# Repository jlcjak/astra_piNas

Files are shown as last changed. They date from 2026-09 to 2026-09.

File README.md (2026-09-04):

# Astra piNas — CM5 dual NVMe carrier

This project was an experiment in using GPT-6 Astra to create a complete PCB from a single initial prompt, followed by a request to fully route it.

**Initial prompt** *(lightly edited for spelling and grammar)*

> I need a new KiCad project with schematics for a small Raspberry Pi CM5 carrier board. It needs to take two full-size M.2 SSDs, so you will need a PCIe switch. Find parts for everything, along with symbols and footprints.
>
> It also needs one RJ45 Ethernet connector, an SD card slot, a barrel jack that accepts 9–25 V, PoE capability, and a power-only USB-C port. A second USB-C port should be used just for USB-to-UART.
>
> Find good symbols and footprints for everything, and keep it nice. Pay particular attention to the CM5 footprint and make sure it is correct. You have TI_API_KEY, TI_API_SECRET, MOUSER_API_KEY, DIGIKEY_CLIENT_ID and DIGIKEY_CLIENT_SECRET set as environment variables in `~/.local/share/codex`. You also have easyeda2kicad installed. You can use the other APIs for datasheets and create your own footprints too.
>
> Remember to put the footprints and symbols in self-contained project libraries. All parts should be well in stock and have a MANUFACTURER PART NUMBER property. Actually, let's use only in-stock LCSC parts, with 0402 as the minimum component size. Try to minimize the component count and number of passives.
>
> Place things logically on the board afterward so it is easy for me to route. Explicitly: do not look for other work on this computer that might help. It will not help and must not be used. Strictly.

**Routing follow-up** *(lightly edited for spelling and grammar)*

> OK, now fully route it. Feel free to move things around as much as you like; I like the current size. Make it nice and clean, and pick the stackup and everything. Use six layers at most. I think six makes sense here, actually.

Open **[astra_piNas.kicad_pro](astra_piNas.kicad_pro)** in **KiCad 10**. The project contains nine schematic sheets and a fully routed **100 × 120 mm, six-layer** board. Both 2280 NVMe sockets are on the underside. Use a **CM5 Lite** for the native microSD interface.

- [Routing and placement notes](docs/ROUTING.md), [selected stackup](docs/STACKUP.md)
- [Schematic PDF](docs/schematics.pdf)
- [Top copper view](docs/routing_top.svg), [bottom copper view](docs/routing_bottom.svg)
- [Top assembly view](docs/placement_top.svg), [bottom assembly view](docs/placement_bottom.svg)
- [BOM with MPNs and LCSC stock snapshots](docs/BOM.csv), [library provenance](docs/LIBRARIES.md)
- [Final validation summary](docs/routing_validation.json), [pair measurements](docs/pair_lengths.csv)
- [ERC](docs/erc.rpt), [PCB DRC](docs/drc.rpt), [schematic parity](docs/schematic_parity.rpt)

All symbols and footprints resolve through the project-local library tables to `lib/`. Available 3D models use project-relative paths. No unrelated local project was searched or reused; the Raspberry Pi reference files were downloaded from the official archive linked in [library provenance](docs/LIBRARIES.md).

The main project files above are the current design. Local routing experiments, tool caches and the downloaded CM5IO reference archive are excluded from this repository. Final routing measurements and validation reports are included under `docs/`. Regeneration scripts can overwrite manual edits. No fabrication package is released while the PoE hold remains unresolved.

**Board views**

Slightly angled 3D views of both sides, with project-local passive models:

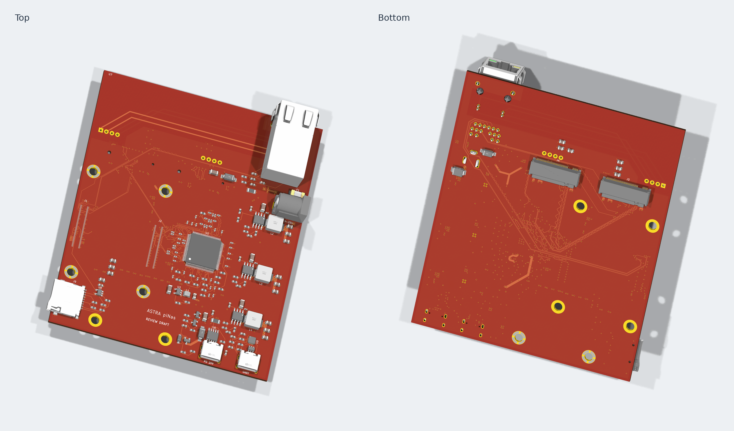
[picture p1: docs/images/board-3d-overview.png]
Angled top and bottom 3D views


Top and bottom placement views:

| Top | Bottom |
| --- | --- |
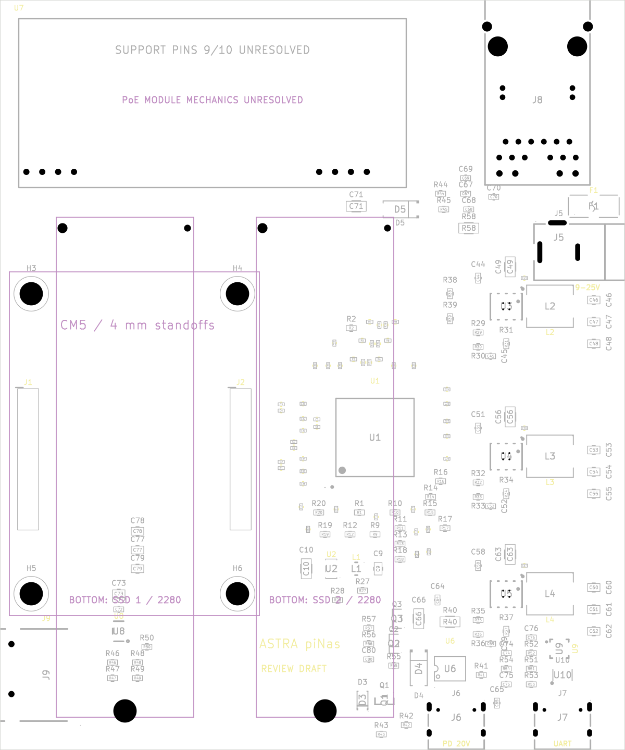
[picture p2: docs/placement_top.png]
Top component placement
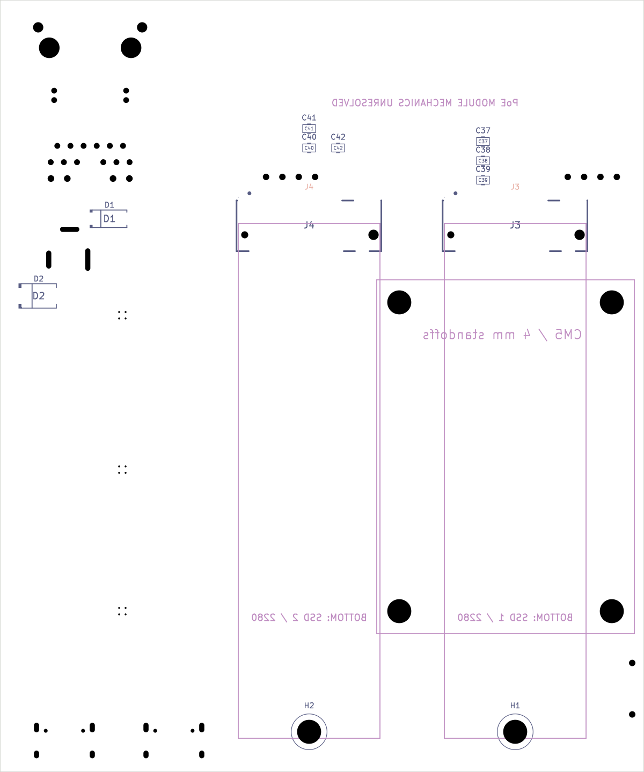
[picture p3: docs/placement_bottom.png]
Bottom component placement
|  |  |

All six copper layers, viewed from the top in stackup order:

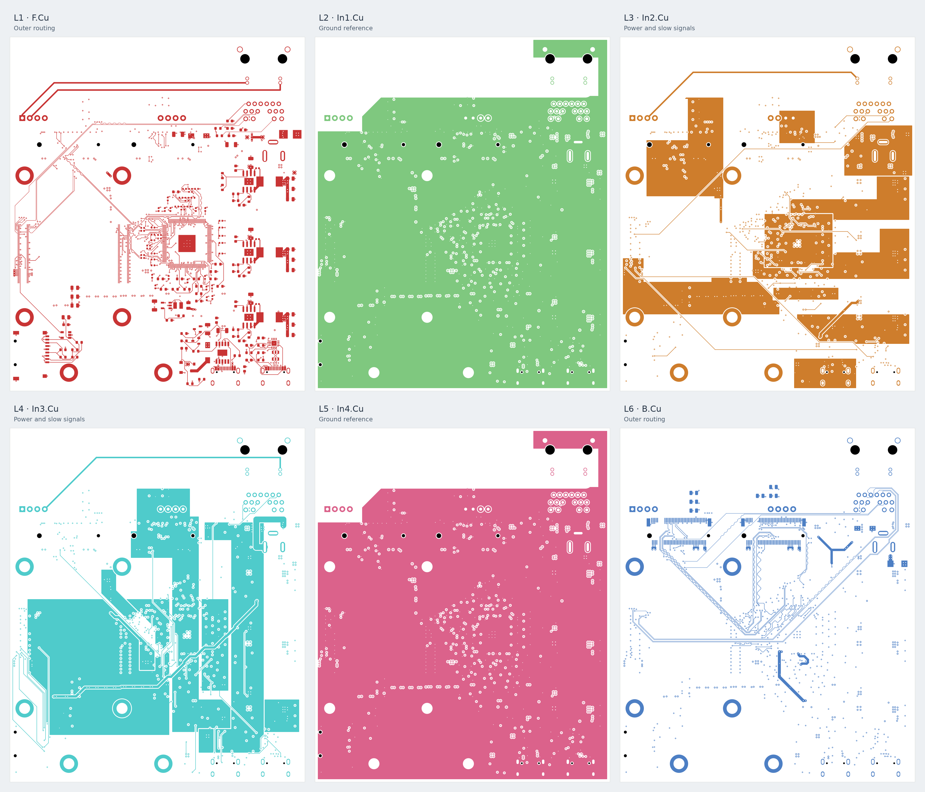
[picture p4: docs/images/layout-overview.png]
Overview of all six PCB copper layers


Individual layers are shown below. Click a layer name for the full-resolution vector drawing.

| Layer | Copper view |
| --- | --- |
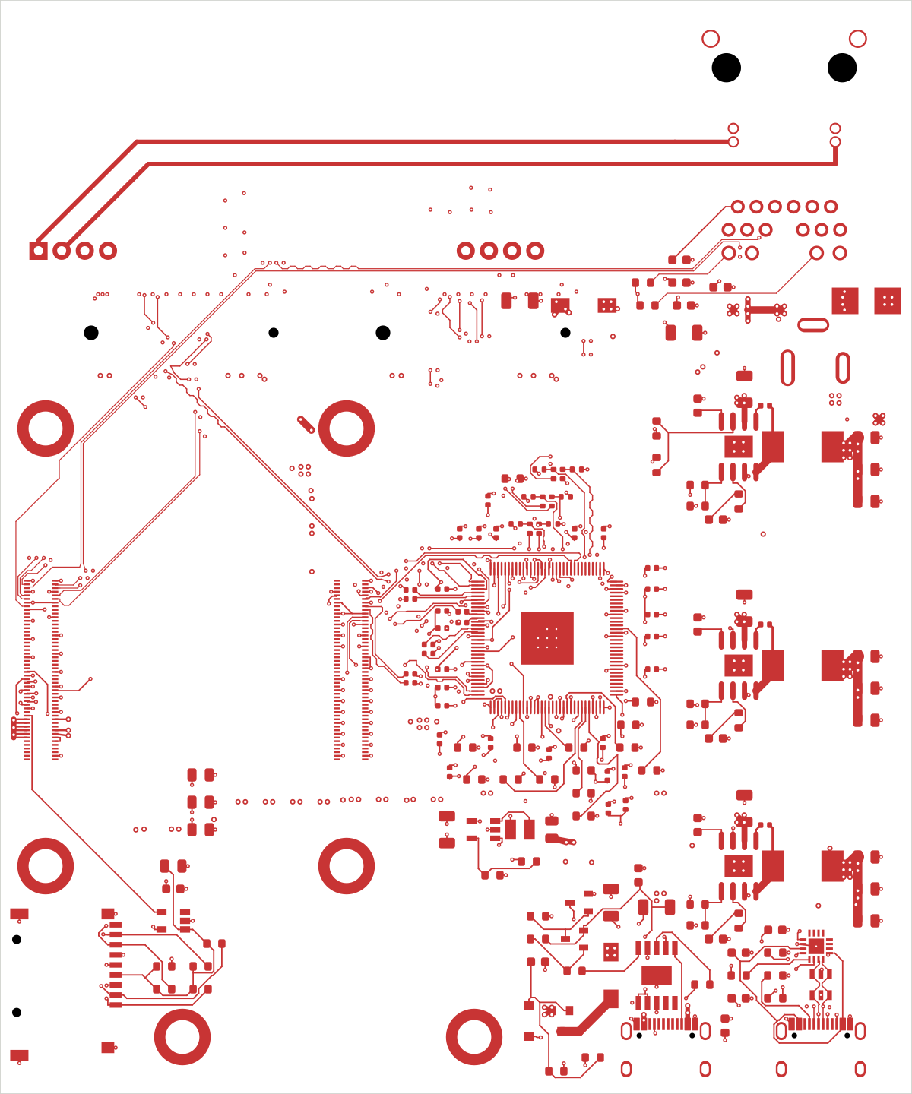
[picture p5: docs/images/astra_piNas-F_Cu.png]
Front copper
| [L1 · F.Cu — outer routing](docs/images/astra_piNas-F_Cu.svg) |  |
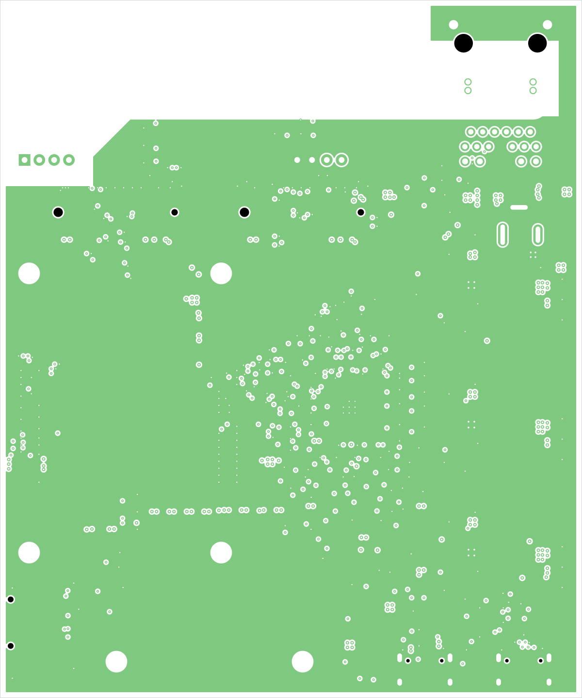
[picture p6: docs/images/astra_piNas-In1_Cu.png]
Inner layer 1 ground plane
| [L2 · In1.Cu — ground reference](docs/images/astra_piNas-In1_Cu.svg) |  |
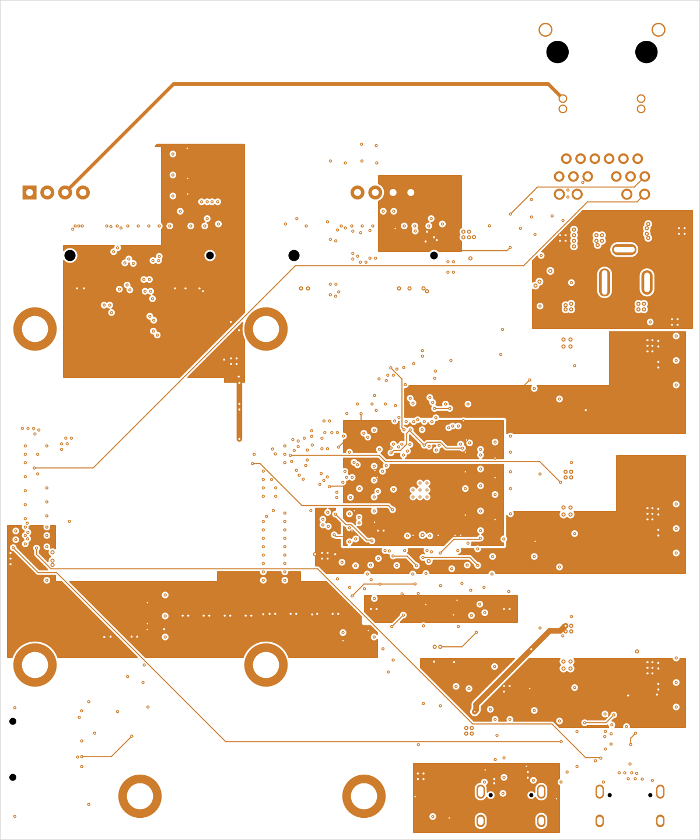
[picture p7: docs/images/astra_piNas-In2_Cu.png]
Inner layer 2 power and signal routing
| [L3 · In2.Cu — power and slow signals](docs/images/astra_piNas-In2_Cu.svg) |  |
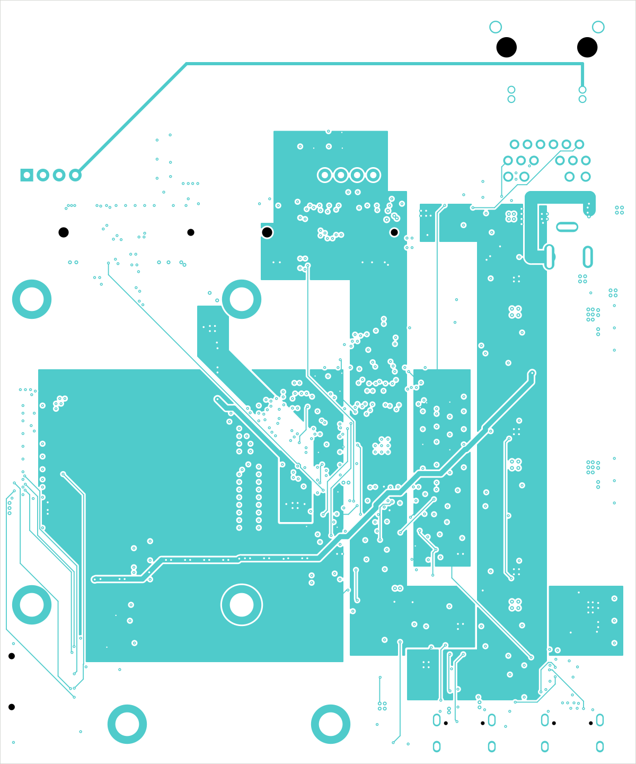
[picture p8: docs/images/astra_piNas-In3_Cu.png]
Inner layer 3 power and signal routing
| [L4 · In3.Cu — power and slow signals](docs/images/astra_piNas-In3_Cu.svg) |  |
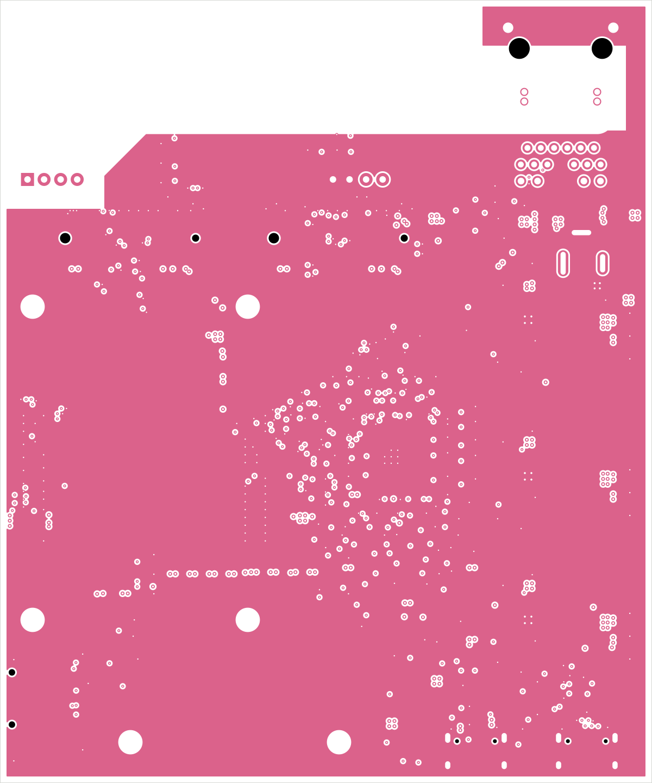
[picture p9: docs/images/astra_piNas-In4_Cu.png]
Inner layer 4 ground plane
| [L5 · In4.Cu — ground reference](docs/images/astra_piNas-In4_Cu.svg) |  |
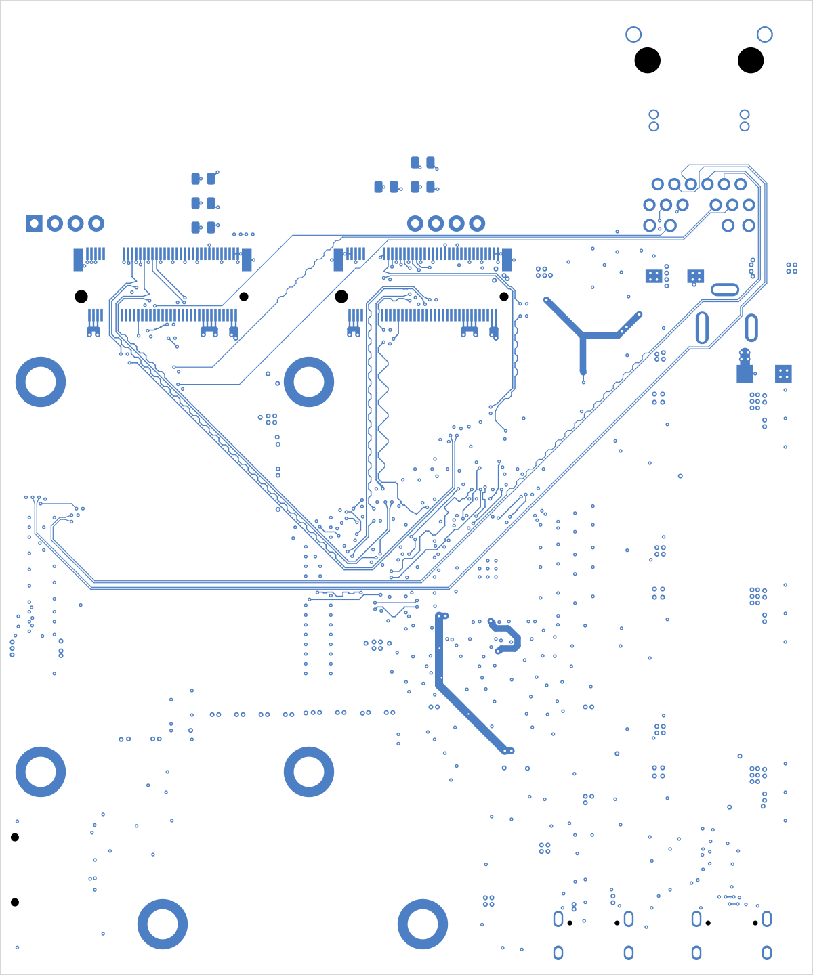
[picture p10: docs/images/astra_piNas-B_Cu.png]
Back copper viewed from the top
| [L6 · B.Cu — outer routing](docs/images/astra_piNas-B_Cu.svg) |  |

**Schematic overview**

All nine sheets are shown below. Open the [schematic PDF](docs/schematics.pdf) to zoom into individual circuits.

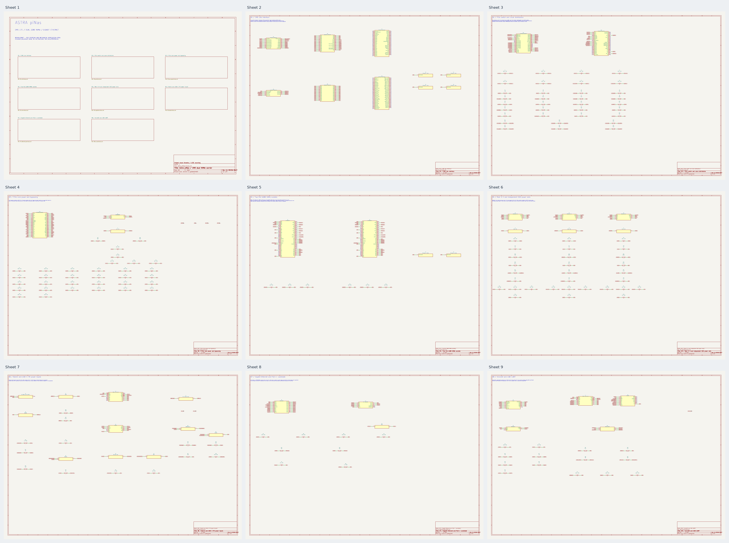
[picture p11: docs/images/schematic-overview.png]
Overview of all nine schematic sheets


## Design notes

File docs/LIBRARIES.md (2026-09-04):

# Local libraries and provenance

`lib/design.kicad_sym` is the active symbol library. Symbols were redrawn into readable functional units with explicit pin numbers; the CM5 connectors and PCIe switch use multiple units but each physical part appears once in the BOM. `lib/astra_piNas.kicad_sym` retains downloaded EasyEDA symbol sources. Active symbols point only to `astra_piNas:` footprints in the project-local `.pretty` directory.

| Part family | Geometry source and treatment |
|---|---|
| CM5 connectors, Amphenol 10164227-1004A1RLF | Pad coordinates taken from Raspberry Pi's official CM5IO revision 2 downloadable KiCad footprint. Split into two physical 100-pin connectors with local numbering. Connector separation, hole locations and module envelope retained in the carrier placement. No substituted CM4/Hirose footprint. |
| TE 1-2199230-5 M.2 | EasyEDA import checked against TE drawing C-2199230, revision B3, sheets 1–3. 0.5 mm pitch, correct M-key gap, 1.1/1.6 mm asymmetric locating holes, and 4.2 mm connector height. Locating holes corrected to NPTH. |
| Hanrun HR913180AE RJ45 | EasyEDA import, checked against Hanrun's schematic and dimensional drawing. Four independent cable center taps feed PoE. Locating holes corrected to NPTH. |
| TYPE-C-31-M-12 | EasyEDA import. Combined VBUS/GND contacts use custom pad shapes; their tiny anchor dimensions do not represent the full copper shape. Locating holes corrected to NPTH. Local pad clearance is 0.09 mm to accommodate the connector's narrow manufactured pad gaps; confirm fabrication capability. |
| AP64501 | EasyEDA package import. Four exposed-pad thermal holes corrected to pin 9/GND and removed from paste openings. Review thermal-via solder treatment with the fabricator. |
| Other semiconductors and connectors | EasyEDA imports tied to the specific LCSC ID, with explicit pin-map review against downloaded datasheets. Imported artwork is not a guarantee of assembly fit. |
| Resistors/capacitors | Vendored standard KiCad SMD footprints matching the selected package size. No 0201 parts. The 1 kΩ PD-feed and PoE-bleeder parts are 1206, 0.5 W ROHM ESR18EZPF1001. |
| YIYUAN SMTSOM225BTR and SMTSOM240BTR spacers | Custom footprints from the YIYUAN family drawing, M2 row: 6.2 mm minimum solder land and 3.73 mm finished hole. Plated holes selected (the drawing permits plating); four separate paste sectors avoid paste over the holes. Heights 2.5 and 4 mm. Verified LCSC pages C5301773 and C19626599. |
| WC-PD60B120A | **Incomplete custom candidate footprint.** The eight electrical pins use dimensions from the module drawing; support pins 9/10 are deliberately absent because their X position is not dimensioned. The body envelope is for placement only. Do not fabricate. |

Available imported WRL/STEP files are stored under `lib/astra_piNas.3dshapes`. Missing optional 3D models were not replaced with guessed geometry. A full assembled CM5/SSD/heatsink model is not provided. All existing model links resolve locally; all 138 resistors and capacitors now link to seven vendored KiCad STEP package models, alongside the existing four inductor models. The generic resistor/capacitor models are visual package representations, not manufacturer-specific height or clearance certification. Their original copyright headers are preserved; see [KiCad model license](../lib/astra_piNas.3dshapes/KICAD-MODELS-LICENSE.md). Model links are present in both the board and local footprint library.

## Primary technical sources

- [Raspberry Pi CM5 datasheet](https://datasheets.raspberrypi.com/cm5/cm5-datasheet.pdf), saved as `sources/cm5.pdf`.
- [Official CM5IO revision 2 KiCad archive](https://pip-assets.raspberrypi.com/categories/1098-design-files/documents/RP-008099-DD-1-CM5%20IO%20Board,%20revision%202,%20KiCAD%20files..zip), used as a geometry reference; the archive and extracted reference project are excluded from this repository.
- [Diodes PI7C9X2G404SL datasheet](https://www.diodes.com/assets/Datasheets/PI7C9X2G404SL.pdf), `sources/switch.pdf`.
- [Diodes AP64501 datasheet](https://www.diodes.com/assets/Datasheets/AP64501.pdf), `sources/ap64501.pdf`.
- [YIYUAN SMTSOM225BTR](https://www.lcsc.com/product-detail/C5301773.html), manufacturer family drawing saved as `sources/C5301773.pdf`; [SMTSOM240BTR](https://www.lcsc.com/product-detail/C19626599.html).
- Other manufacturer datasheets downloaded via the corresponding LCSC product pages are saved as `sources/C<number>.pdf`. LCSC product URLs, actual LCSC stock (distinct from JLC assembly stock), and UTC timestamps are in `sources/catalog.json` and the BOM. Raw retrieved product HTML is retained as evidence.

The imported libraries and manufacturer reference material retain their original ownership and licensing. These were fetched from public sources; no unrelated local project was inspected or reused.

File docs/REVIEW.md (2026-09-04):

# Release status: routed review; fabrication hold

This is a new KiCad 10 project created in this directory. The schematics and board are linked, with project-local symbols, footprints and available 3D models. The 100 × 120 mm, six-layer board is routed and geometrically length-matched. No Gerbers have been released.

## Open design decisions

1. **PoE does not yet meet the sourcing/mechanical requirement.** WC-PD60B120A (LCSC C2848082) has only **15** units available in the captured LCSC evidence. It is a candidate, not an approved production selection. Its supplied drawing does not locate support pins 9/10 horizontally. Its local footprint therefore intentionally includes only the eight dimensioned electrical pins and a body envelope. Do not manufacture that footprint. A manufacturer-confirmed drawing and adequate supply, or a different PoE implementation, are required. The low stock was not silently accepted as “well stocked.”
2. **PoE power budget needs a decision.** The module advertises 12 V / 5 A and mentions class 5/6 operation. That does not establish delivery of 60 W to this carrier from a class-6 PSE. Classification, conversion loss and temperature derating must be resolved. A fully loaded CM5 and two unrestricted SSDs cannot be promised to operate on an ordinary PoE+ port. There is no software-controlled load shedding or negotiated-power telemetry in this draft.
3. **Power validation remains required.** Check AP64501 compensation with effective, voltage-biased output capacitance (including the SSD input capacitance), USB-PD inrush and source handover, 9 V maximum-load operation, and temperatures of the OR diodes and converters. Check the 1 V/3.3 V switch power-down sequence and reset timing on actual hardware. ERC does not validate these behaviors.
4. **Connector/mechanical fit must be checked with purchased samples.** CM5 connector pads and relative positioning use the official CM5IO reference. M.2 pads match the TE drawing. The SSD insertion datum and spacer height were derived from TE's drawing; confirm with the actual sockets and SSDs before release. The PoE support-hole problem is a known incompleteness, not a sample-validation formality.
5. **Assembly hardware:** the soldered spacers are in the LCSC BOM; removable M2 screws, the CM5 Lite, SSDs, heatsinks and enclosure are not included in the carrier BOM. Screw engagement and head diameter must be selected for the actual assembly. M2 screws are used through the CM5's 2.7 mm mounting holes.

## Implemented architecture

- CM5 **Lite** carrier; native microSD wiring. An eMMC-equipped CM5 cannot use this socket as its native SD boot interface.
- Two TE 1-2199230-5 M-key sockets, each connected at PCIe x1, supporting 2280 **NVMe** modules. SATA SSDs are not supported.
- Diodes PI7C9X2G404SLBFDEX PCIe switch: upstream port 0, SSDs on ports 1 and 2, port 3 unused. All SSD traffic shares the CM5 PCIe Gen 2 x1 link; this is not two independent x4 links.
- Integrated switch clock buffer. CM5 CLKREQ# is grounded for continuous clocking. Switch TX lines have external AC coupling; the CM5 TX coupling is already on the module. HCSL outputs use 49.9-ohm shunts and 33.2-ohm series resistors; the switch's own REFCLK input is AC coupled.
- Separate AP64501 converters for CM5 5 V and each SSD 3.3 V rail. SSD enables follow PCIE_PWR_EN. A TLV62569 generates the switch's 1 V rail, enabled from CM5 3.3 V.
- Gigabit PoE-capable Hanrun HR913180AE magjack, with the four cable-side center taps routed to the candidate PoE module. PHY-side center taps have local bypassing.
- Center-positive 9–25 V barrel input, 5 A fuse, TVS and Schottky reverse-current blocking. Input current and temperature, especially at 9 V, limit total usable power.
- Power-only USB-C uses a CH224K requesting **20 V** (CFG1=0, CFG2=1, CFG3=0; the CH224Q/A strap table is different). Use a supply offering 20 V at 3 A. Its status signal controls a level-shifted PMOS gate, with a 10 V gate clamp. The VDD feed resistor is rated 0.5 W. A gate capacitor slows switching, but compliant inrush has not been demonstrated.
- The second USB-C connects only to CH343P USB-UART. USB VBUS powers the bridge; CM5 3.3 V powers its independent VIO. GPIO14 is CM5 TX; GPIO15 is CM5 RX. This is **not** the separate on-module boot-debug UART. Configure the OS UART/pin mux accordingly. USB enumeration and a compatible driver are required on the host.
- All selected resistors and capacitors are 0402 or larger. Every populated carrier component has `MANUFACTURER PART NUMBER`, manufacturer and LCSC fields. Positive stock is recorded in the BOM, but stock is a snapshot, not a reservation.

## Verification meaning

`erc.rpt` is KiCad's electrical-rules report. `audit.json` checks the generated netlist against the explicit pin-to-net manifest and verifies MPN/stock metadata; it is a consistency check, not an independent circuit proof. `drc.rpt` records the final PCB geometry and connectivity checks. `pair_lengths.csv` records the pad-to-pad differential-path measurements. Known limitations must not be hidden by quoting a clean ERC result.

The imported EasyEDA footprints were corrected where locating holes were erroneously plated and where buck-converter thermal vias were unnamed. The terminal numbers of all connected schematic pins are checked against board pads. YIYUAN spacer footprints use the manufacturer's 6.2 mm solder land and 3.73 mm finished hole. Plated holes are selected and the paste aperture is split into four sectors. The rejected Würth candidates were not retained in the active BOM because their LCSC pages were unavailable.

## Final automated checks

See `routing_validation.json`, `erc.rpt`, `drc.rpt`, `schematic_parity.rpt`, `audit.json` and `board_audit.json` for the actual final results. Routing DRC and schematic parity are reported separately: the two omitted PoE support pads, U7.9 and U7.10, remain a known footprint incompleteness. The consistency audit checks 685 connected schematic pin assignments across 176 physical components. These checks do not resolve the PoE hold or replace prototype validation.

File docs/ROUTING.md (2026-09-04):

# Routed board

The outline remains **100 × 120 mm**. The board uses **six copper layers**, with the JLCPCB JLC06161H-3313 construction recorded in the KiCad stackup. See [STACKUP.md](STACKUP.md) for dielectric thicknesses, copper weights and impedance assumptions.

| Layer | Assignment |
|---|---|
| F.Cu | Components, differential pairs, local power loops and signal escapes |
| In1.Cu | Ground reference |
| In2.Cu | Power distribution and slow signals |
| In3.Cu | Power distribution and slow signals |
| In4.Cu | Ground reference |
| B.Cu | M.2 sockets, differential pairs and local connections |

There are no signal traces on In1.Cu or In4.Cu. Secondary ground is excluded from the cable-side PoE region. PCIe, reference-clock, Ethernet and USB data traces use the outer layers.

## Pair routing and verification

PCIe and USB nominal dimensions are 0.127 mm width / 0.150 mm coupled gap; Ethernet uses 0.100 mm / 0.150 mm. Local escapes, AC-coupling parts and tuning sections separate the pair members. Fabricator confirmation of controlled impedance remains necessary.

The pad-to-pad length audit follows each signal through its coupling capacitors and clock resistors, excludes unused branches, and checks both USB-C plug orientations. Pair members have equal traversed-via counts and equal calculated barrel lengths. Targets are 0.10 mm intra-pair skew for PCIe/clock/USB and 0.15 mm for Ethernet. See [pair_lengths.csv](pair_lengths.csv) for the final measurements and [routing_validation.json](routing_validation.json) for check results. This geometric audit is not an electromagnetic simulation or a hardware eye-diagram test.

Three supported PCIe polarity reversals are explicit in the schematics: the CM5 receive pair, the switch's upstream receive pair, and SSD2's receive pair at J4. These do not swap transmit and receive functions. The switch's RXPOLINV_DIS pin remains unconnected, using its internal pull-down.

Ground return vias accompany layer transitions. Long auxiliary supply bridges are stitched into the broad supply planes; local via arrays serve the regulators, OR diodes and load connections. Power-loop copper and regulator switch nodes were routed before the remaining signals. Some power, exposed-pad and small-component connections use vias in pads: specify an appropriate filled/capped process and review the stencil with the assembler.

## Mechanical placement

- CM5 body envelope: X=1.5–41.5, Y=43.5–98.5 mm. J1=(4.5,73.5), J2=(38.5,73.5), preserving the official 34 mm connector separation. CM5 spacer centers are (5,47), (38,47), (5,95), (38,95), a 33 × 48 mm mounting pattern with 4 mm spacers.
- Both 2280 SSDs are on the underside. Sockets are centered at (20,35) and (52,35), with insertion toward increasing Y. Their 2.5 mm retention spacers are at Y=113.75 mm. Card envelopes are drawn on Dwgs.User; bottom-side components are kept out of them.
- The PCIe switch and its small passives occupy the center. Three main power stages occupy the right side. RJ45 is at the upper-right edge, barrel power at the right edge, the two USB-C ports at the bottom, and microSD at the lower-left edge.
- Keep adequate airflow and CM5/SSD cooling. The project does not contain a complete enclosure or heatsink clearance model.

## Fabrication hold

Routing completion does not clear the PoE module's missing support-pin dimensions or its limited stock. See [REVIEW.md](REVIEW.md). No fabrication package is released. Prototype validation must cover supply regulation and temperature under load, source handover, USB-PD inrush, PoE classification/budget, reset sequencing, and operation of both SSDs.

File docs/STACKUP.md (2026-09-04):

# Six-layer stackup

Selected fabrication reference: **JLCPCB JLC06161H-3313**, nominal finished thickness **1.6 mm**, outer copper 1 oz and inner copper 0.5 oz. Dimensions below follow [JLCPCB's published impedance stackup](https://jlcpcb.com/impedance), checked 5 September 2026. Finished thickness includes manufacturing tolerances; do not substitute another six-layer construction without recalculating impedance.

| Layer / dielectric | Thickness, mm | Relative permittivity | Use |
|---|---:|---:|---|
| F.Cu | 0.0350 | — | Components, high-speed pairs, local power loops |
| 3313 prepreg | 0.0994 | 4.10 | |
| In1.Cu | 0.0152 | — | Ground reference; no signal routing |
| Core | 0.5500 | 4.60 | |
| In2.Cu | 0.0152 | — | Power distribution and slow signals |
| 2116 prepreg | 0.1088 | 4.16 | |
| In3.Cu | 0.0152 | — | Power distribution and slow signals |
| Core | 0.5500 | 4.60 | |
| In4.Cu | 0.0152 | — | Ground reference; no signal routing |
| 3313 prepreg | 0.0994 | 4.10 | |
| B.Cu | 0.0350 | — | SSD sockets, high-speed pairs and local bridges |

Outer microstrip starting dimensions are **0.127 mm width / 0.150 mm gap** for 90 Ω PCIe and USB, and **0.100 mm width / 0.150 mm gap** for 100 Ω Ethernet. These are nominal design dimensions, not measured impedance. The fabricator must confirm its controlled-impedance construction and coupon results; solder-mask thickness, etched conductor shape and actual dielectric properties affect the result. The exploratory quasi-static estimates in `routing/impedance_estimates.json` are not a fabrication field-solver sign-off.

The reference planes are continuous in the secondary power domain. Cable-side PoE conductors and the module primary connections are excluded from secondary copper regions. Power bridges use the two interior signal layers or the outer layers, retaining both ground reference layers.

Minimum ordinary clearance is 0.127 mm; existing fine-pitch connector land patterns retain their documented local clearances. Small through vias are 0.45 / 0.20 mm diameter/drill; power arrays use 0.60 / 0.30 mm. Copper is kept at least 0.5 mm from the routed board edge. Some exposed-pad and power-pad connections use vias in pads: confirm a filled/capped process and the corresponding stencil with the assembler before fabrication.

Raspberry Pi specifies 90 Ω differential PCIe routing with an ideal 0.1 mm intra-pair length match, and 100 Ω Ethernet with an ideal 0.15 mm intra-pair match. See the [CM5 datasheet](https://pip-assets.raspberrypi.com/categories/944-raspberry-pi-compute-module-5/documents/RP-008180-DS-4-cm5-datasheet.pdf). The two CM5 receiver coupling capacitors are 220 nF; the other data coupling positions are 100 nF.

This stackup selection does not clear the outstanding PoE mechanical fabrication hold in `REVIEW.md`.

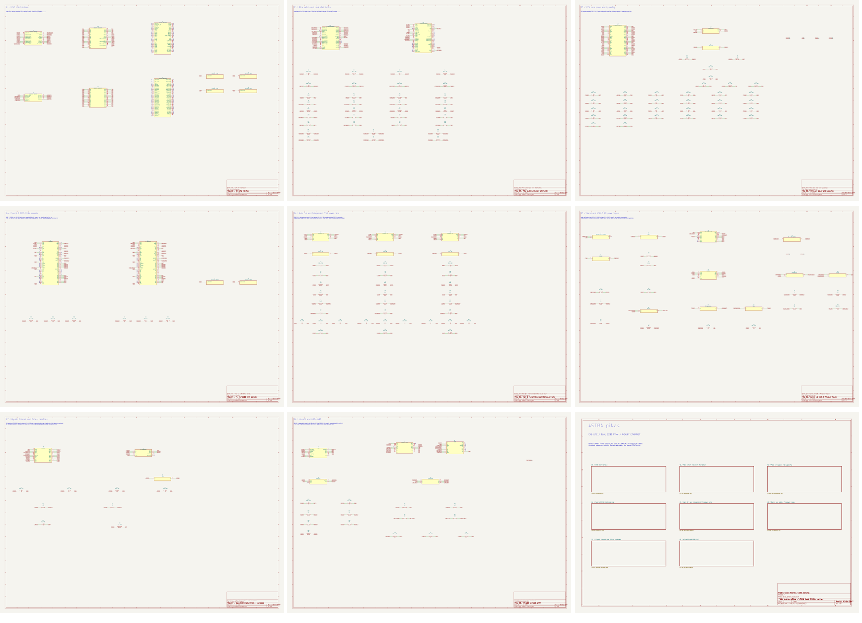
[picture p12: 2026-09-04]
docs/schematic_contact_sheet.png

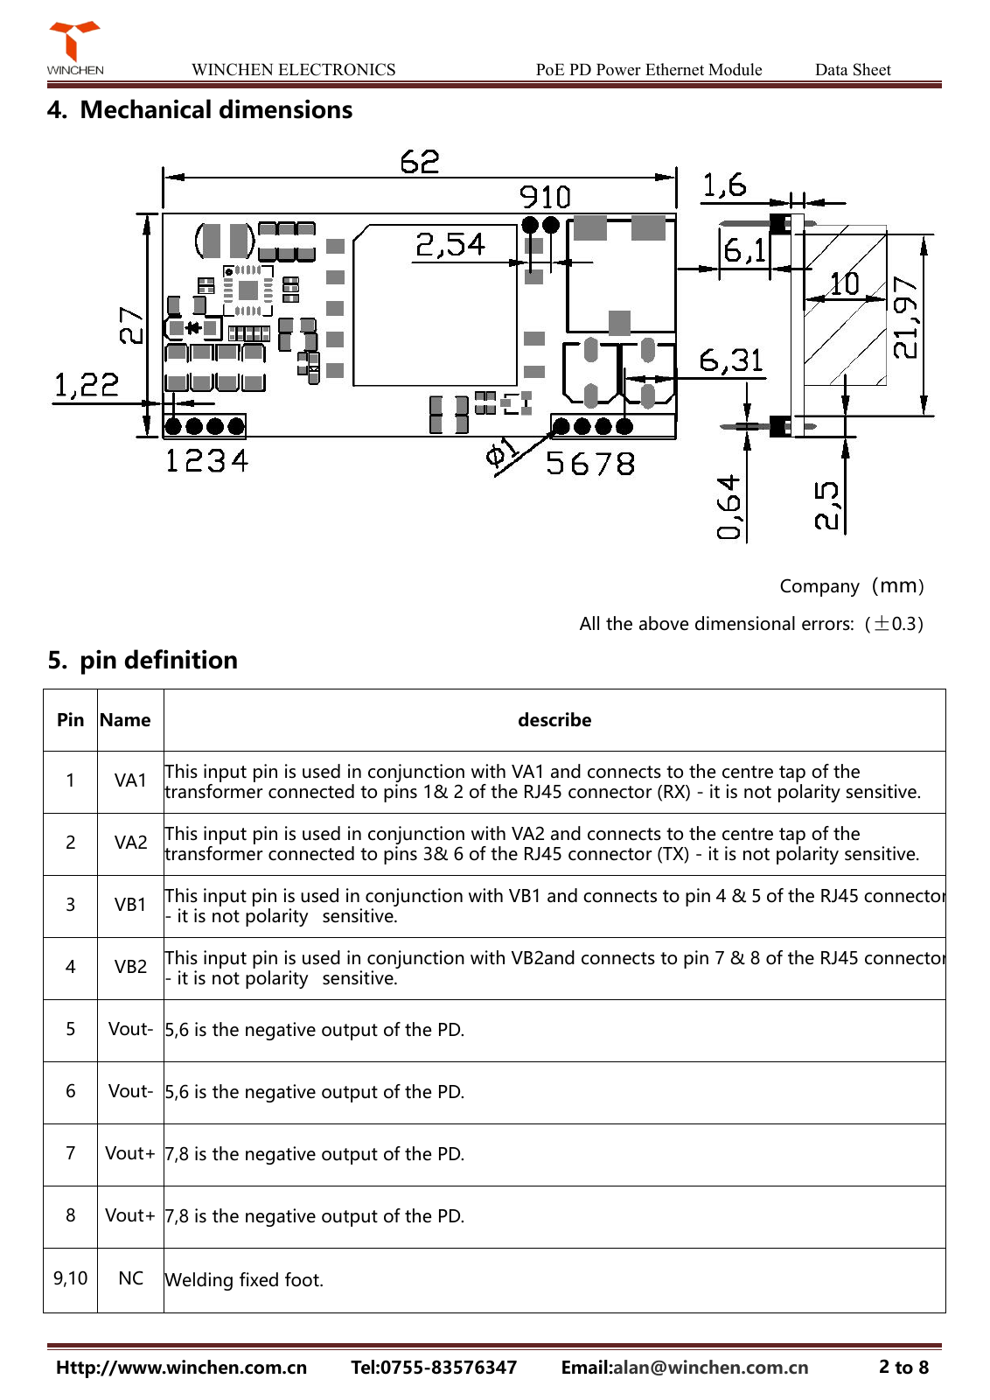
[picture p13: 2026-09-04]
sources/poe_mechanical.png

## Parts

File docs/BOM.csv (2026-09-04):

References | Quantity | Manufacturer | MANUFACTURER PART NUMBER | LCSC Part Number | LCSC Stock | Stock checked UTC | Footprint | Product URL | Status
D2 | 1 | MDD(Microdiode Semiconductor) | SMBJ26A | C123820 | 25520 | 2026-09-04T21:32:39.584681+00:00 | SMB_L4.6-W3.6-LS5.3-RD | https://www.lcsc.com/product-detail/C123820.html | Selected; prototype validation required
D1, D4, D5 | 3 | Shandong Jingdao Microelectronics | SS54 | C123946 | 46960 | 2026-09-04T21:32:38.063087+00:00 | SMA_L4.4-W2.8-LS5.4-RD | https://www.lcsc.com/product-detail/C123946.html | Selected; prototype validation required
U2 | 1 | Texas Instruments | TLV62569DBVR | C141836 | 128295 | 2026-09-04T21:32:37.690946+00:00 | SOT-23-5_L3.0-W1.7-P0.95-LS2.8-BR | https://www.lcsc.com/product-detail/C141836.html | Selected; prototype validation required
C10, C49, C56, C63, C66, C71 | 6 | Samsung Electro-Mechanics | CL31B106KAHNNNE | C14860 | 1052960 | 2026-09-04T21:32:39.182945+00:00 | C_1206_3216Metric | https://www.lcsc.com/product-detail/C14860.html | Selected; prototype validation required
Q1 | 1 | Alpha & Omega Semicon | AO3401A | C15127 | 244595 | 2026-09-04T21:32:39.691958+00:00 | SOT-23_L2.9-W1.3-P1.90-LS2.4-BR | https://www.lcsc.com/product-detail/C15127.html | Selected; prototype validation required
C3, C4, C5, C6, C7, C8, C11, C12, C13, C14, C15, C16, C17, C18, C19, C20, C21, C22, C23, C24, C25, C26, C27, C28, C29, C30, C31, C32, C33, C34, C35, C36, C43, C50, C57 | 35 | Samsung Electro-Mechanics | CL05B104KO5NNNC | C1525 | 7129300 | 2026-09-04T21:46:20.728586+00:00 | C_0402_1005Metric | https://www.lcsc.com/product-detail/C1525.html | Selected; prototype validation required
C44, C51, C58 | 3 | Samsung Electro-Mechanics | CL10B103KB8NNNC | C1589 | 2840150 | 2026-09-04T21:32:39.313226+00:00 | C_0603_1608Metric | https://www.lcsc.com/product-detail/C1589.html | Selected; prototype validation required
C67, C68, C69, C70, C72, C74, C75, C76, C80 | 9 | Samsung Electro-Mechanics | CL10B104KB8NNNC | C1591 | 2493100 | 2026-09-04T21:32:38.954077+00:00 | C_0603_1608Metric | https://www.lcsc.com/product-detail/C1591.html | Selected; prototype validation required
J6, J7 | 2 | Korean Hroparts Elec | TYPE-C-31-M-12 | C165948 | 284155 | 2026-09-04T21:32:37.263211+00:00 | USB-C_SMD-TYPE-C-31-M-12_1 | https://www.lcsc.com/product-detail/C165948.html | Selected; prototype validation required
C1, C2 | 2 | Samsung Electro-Mechanics | CL05B224KO5NNNC | C16772 | 2585850 | 2026-09-04T22:11:29.445277+00:00 | C_0402_1005Metric | https://www.lcsc.com/product-detail/C16772.html | Selected; prototype validation required
H3, H4, H5, H6 | 4 | YIYUAN | SMTSOM240BTR | C19626599 | 875 | 2026-09-04T21:34:10.001349+00:00 | YIYUAN_SMTSOM240BTR | https://www.lcsc.com/product-detail/C19626599.html | Selected; prototype validation required
J8 | 1 | HANRUN(Zhongshan HanRun Elec) | HR913180AE | C19724762 | 169 | 2026-09-04T21:32:37.227892+00:00 | RJ45-TH_HR913180AE | https://www.lcsc.com/product-detail/C19724762.html | Selected; prototype validation required
U3, U4, U5 | 3 | Diodes Incorporated | AP64501SP-13 | C2071517 | 1806 | 2026-09-04T21:32:37.682590+00:00 | SOIC-8_L4.9-W3.9-P1.27-LS6.0-BL-EP-1 | https://www.lcsc.com/product-detail/C2071517.html | Selected; prototype validation required
R40, R58 | 2 | ROHM Semicon | ESR18EZPF1001 | C2074262 | 11480 | 2026-09-04T21:32:40.354956+00:00 | R_1206_3216Metric | https://www.lcsc.com/product-detail/C2074262.html | Selected; prototype validation required
D3 | 1 | Jiangsu Changjing Electronics Technology Co., Ltd. | BZT52C10 | C2103 | 85600 | 2026-09-04T21:32:39.704045+00:00 | SOD-123_L2.8-W1.8-LS3.7-RD | https://www.lcsc.com/product-detail/C2103.html | Selected; prototype validation required
R29 | 1 | UNI-ROYAL(Uniroyal Elec) | 0603WAF1153T5E | C22783 | 95900 | 2026-09-04T21:32:38.615274+00:00 | R_0603_1608Metric | https://www.lcsc.com/product-detail/C22783.html | Selected; prototype validation required
R1 | 1 | UNI-ROYAL(Uniroyal Elec) | 0603WAF1431T5E | C22840 | 14900 | 2026-09-04T21:32:38.347249+00:00 | R_0603_1608Metric | https://www.lcsc.com/product-detail/C22840.html | Selected; prototype validation required
R34, R37 | 2 | UNI-ROYAL(Uniroyal Elec) | 0603WAF1052T5E | C22855 | 125200 | 2026-09-04T21:32:38.845629+00:00 | R_0603_1608Metric | https://www.lcsc.com/product-detail/C22855.html | Selected; prototype validation required
R31 | 1 | UNI-ROYAL(Uniroyal Elec) | 0603WAF1582T5E | C22880 | 41900 | 2026-09-04T21:32:38.774034+00:00 | R_0603_1608Metric | https://www.lcsc.com/product-detail/C22880.html | Selected; prototype validation required
R28 | 1 | UNI-ROYAL(Uniroyal Elec) | 0603WAF3003T5E | C23024 | 440700 | 2026-09-04T21:32:38.978050+00:00 | R_0603_1608Metric | https://www.lcsc.com/product-detail/C23024.html | Selected; prototype validation required
R32, R35 | 2 | UNI-ROYAL(Uniroyal Elec) | 0603WAF6982T5E | C23098 | 32100 | 2026-09-04T21:32:38.534037+00:00 | R_0603_1608Metric | https://www.lcsc.com/product-detail/C23098.html | Selected; prototype validation required
R14, R15, R16, R17, R18, R19, R20, R44, R45, R53, R54 | 11 | UNI-ROYAL(Uniroyal Elec) | 0603WAF3300T5E | C23138 | 2435600 | 2026-09-04T21:32:38.107244+00:00 | R_0603_1608Metric | https://www.lcsc.com/product-detail/C23138.html | Selected; prototype validation required
R2 | 1 | UNI-ROYAL(Uniroyal Elec) | 0603WAF4750T5E | C23181 | 3300 | 2026-09-04T21:32:38.457299+00:00 | R_0603_1608Metric | https://www.lcsc.com/product-detail/C23181.html | Selected; prototype validation required
R9, R10, R11, R12, R13, R51, R52 | 7 | UNI-ROYAL(Uniroyal Elec) | 0603WAF5101T5E | C23186 | 20146800 | 2026-09-04T21:32:38.051660+00:00 | R_0603_1608Metric | https://www.lcsc.com/product-detail/C23186.html | Selected; prototype validation required
U8 | 1 | Richtek Tech | RT9742GGJ5 | C250547 | 6085 | 2026-09-04T21:32:37.703076+00:00 | TSOT-23-5_L2.9-W1.6-P0.95-LS2.8-BR | https://www.lcsc.com/product-detail/C250547.html | Selected; prototype validation required
R21, R22, R23, R24, R25, R26 | 6 | UNI-ROYAL(Uniroyal Elec) | 0402WGF332JTCE | C25106 | 26200 | 2026-09-04T21:46:21.111842+00:00 | R_0402_1005Metric | https://www.lcsc.com/product-detail/C25106.html | Selected; prototype validation required
R3, R4, R5, R6, R7, R8 | 6 | UNI-ROYAL(Uniroyal Elec) | 0402WGF499JTCE | C25120 | 1256000 | 2026-09-04T21:46:21.494433+00:00 | R_0402_1005Metric | https://www.lcsc.com/product-detail/C25120.html | Selected; prototype validation required
R38, R42, R56, R57 | 4 | UNI-ROYAL(Uniroyal Elec) | 0603WAF1003T5E | C25803 | 17262200 | 2026-09-04T21:32:38.095536+00:00 | R_0603_1608Metric | https://www.lcsc.com/product-detail/C25803.html | Selected; prototype validation required
R27 | 1 | UNI-ROYAL(Uniroyal Elec) | 0603WAF2003T5E | C25811 | 1621700 | 2026-09-04T21:32:38.891275+00:00 | R_0603_1608Metric | https://www.lcsc.com/product-detail/C25811.html | Selected; prototype validation required
R30, R33, R36, R39 | 4 | UNI-ROYAL(Uniroyal Elec) | 0603WAF2212T5E | C25961 | 16200 | 2026-09-04T21:32:38.495874+00:00 | R_0603_1608Metric | https://www.lcsc.com/product-detail/C25961.html | Selected; prototype validation required
U9 | 1 | WCH(Jiangsu Qin Heng) | CH343P | C2846043 | 4883 | 2026-09-04T21:32:37.653872+00:00 | TQFN-16_L3.0-W3.0-P0.50-BL-EP1.7 | https://www.lcsc.com/product-detail/C2846043.html | Selected; prototype validation required
L2, L3, L4 | 3 | KOHERelec | MDA7050-3R3M | C2847540 | 742 | 2026-09-04T21:32:39.326260+00:00 | IND-SMD_L7.3-W6.6 | https://www.lcsc.com/product-detail/C2847540.html | Selected; prototype validation required
U7 | 1 | Winchen | WC-PD60B120A | C2848082 | 15 | 2026-09-04T21:32:37.304659+00:00 | WC_PD60B120A_MECHANICAL_REVIEW | https://www.lcsc.com/product-detail/C2848082.html | PROVISIONAL: low stock and incomplete mechanics
C64, C65 | 2 | Samsung Electro-Mechanics | CL10B105KA8NNNC | C29936 | 1640030 | 2026-09-04T21:32:39.785787+00:00 | C_0603_1608Metric | https://www.lcsc.com/product-detail/C29936.html | Selected; prototype validation required
C9, C37, C38, C39, C40, C41, C42, C46, C47, C48, C53, C54, C55, C60, C61, C62, C73, C77, C78, C79 | 20 | Samsung Electro-Mechanics | CL21A226MAQNNNE | C45783 | 1788200 | 2026-09-04T21:32:39.032809+00:00 | C_0805_2012Metric | https://www.lcsc.com/product-detail/C45783.html | Selected; prototype validation required
F1 | 1 | Littelfuse | 0451005.MRL | C48467 | 27635 | 2026-09-04T21:32:40.428725+00:00 | FUSE-SMD_L6.1-W2.6 | https://www.lcsc.com/product-detail/C48467.html | Selected; prototype validation required
U1 | 1 | Diodes Incorporated | PI7C9X2G404SLBFDEX | C500767 | 2750 | 2026-09-04T21:32:37.276258+00:00 | LQFP-128_L14.0-W14.0-P0.40-LS16.0-BL-EP5.8 | https://www.lcsc.com/product-detail/C500767.html | Selected; prototype validation required
H1, H2 | 2 | YIYUAN | SMTSOM225BTR | C5301773 | 6500 | 2026-09-04T21:34:09.999921+00:00 | YIYUAN_SMTSOM225BTR | https://www.lcsc.com/product-detail/C5301773.html | Selected; prototype validation required
Q2 | 1 | onsemi | MMBT3906LT1G | C53444 | 1085650 | 2026-09-04T21:32:40.192534+00:00 | SOT-23-3_L2.9-W1.3-P1.90-LS2.4-BR | https://www.lcsc.com/product-detail/C53444.html | Selected; prototype validation required
J3, J4 | 2 | TE Connectivity | 1-2199230-5 | C590854 | 1169 | 2026-09-04T21:32:37.254522+00:00 | PCIE-SMD_75P-P0.50_1-2199230-5 | https://www.lcsc.com/product-detail/C590854.html | Selected; prototype validation required
J5 | 1 | HOOYA | DC-005D-2.0-PU-SP(UL) | C7428653 | 385 | 2026-09-04T21:32:37.959444+00:00 | DC-IN-TH_DC-005D-2.0-PU-SP | https://www.lcsc.com/product-detail/C7428653.html | Selected; prototype validation required
J1, J2 | 2 | Amphenol ICC | 10164227-1004A1RLF | C7435219 | 1174 | 2026-09-04T21:32:37.241261+00:00 | CM5_Amphenol_10164227_1004_OfficialPads | https://www.lcsc.com/product-detail/C7435219.html | Selected; prototype validation required
U10 | 1 | STMicroelectronics | USBLC6-2SC6 | C7519 | 29315 | 2026-09-04T21:32:39.526801+00:00 | SOT-23-6_L2.9-W1.6-P0.95-LS2.8-BL | https://www.lcsc.com/product-detail/C7519.html | Selected; prototype validation required
C45, C52, C59 | 3 | Samsung Electro-Mechanics | CL10B272KB8NNNC | C84713 | 34060 | 2026-09-04T21:32:39.297779+00:00 | C_0603_1608Metric | https://www.lcsc.com/product-detail/C84713.html | Selected; prototype validation required
Q3 | 1 | Jiangsu Changjing Electronics Technology Co., Ltd. | 2N7002 | C8545 | 1740550 | 2026-09-04T21:32:40.225072+00:00 | SOT-23-3_L2.9-W1.3-P1.90-LS2.4-BR | https://www.lcsc.com/product-detail/C8545.html | Selected; prototype validation required
L1 | 1 | TDK | VLS252010HBX-1R0M-1 | C88211 | 7680 | 2026-09-04T21:32:39.371507+00:00 | IND-SMD_L2.5-W2.0-1 | https://www.lcsc.com/product-detail/C88211.html | Selected; prototype validation required
J9 | 1 | Korean Hroparts Elec | TF-01A | C91145 | 213170 | 2026-09-04T21:32:37.590375+00:00 | TF-SMD_TF-01A | https://www.lcsc.com/product-detail/C91145.html | Selected; prototype validation required
U6 | 1 | WCH(Jiangsu Qin Heng) | CH224K | C970725 | 2894 | 2026-09-04T21:32:37.631989+00:00 | ESSOP-10_L4.9-W3.9-P1.0-LS6.0-TL-EP | https://www.lcsc.com/product-detail/C970725.html | Selected; prototype validation required
R41, R43, R46, R47, R48, R49, R50, R55 | 8 | YAGEO | RC0603FR-0710KL | C98220 | 11908000 | 2026-09-04T21:32:38.110740+00:00 | R_0603_1608Metric | https://www.lcsc.com/product-detail/C98220.html | Selected; prototype validation required

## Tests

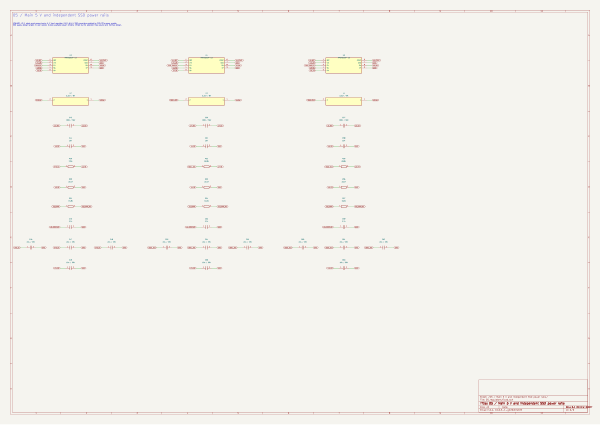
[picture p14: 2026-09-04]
docs/qa_4.png

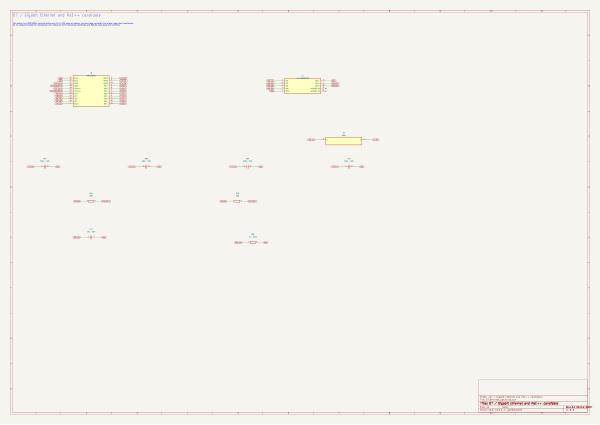
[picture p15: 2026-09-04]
docs/qa_6.png

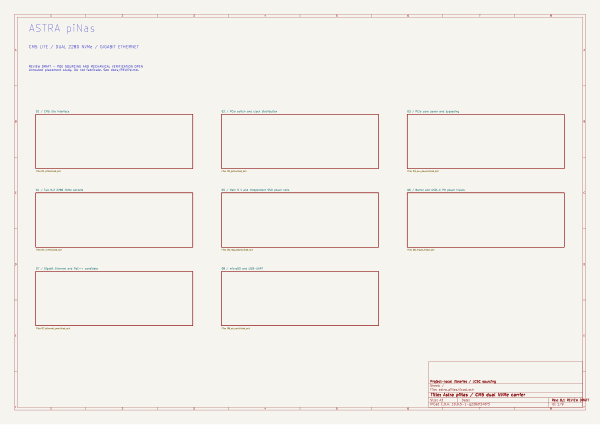
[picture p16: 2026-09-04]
docs/qa_8.png

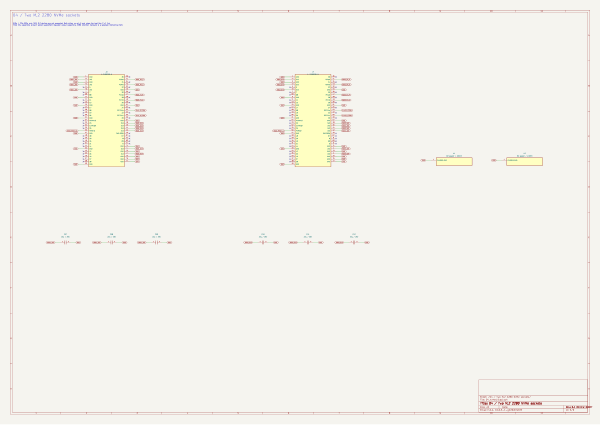
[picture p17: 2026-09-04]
docs/qa_3.png

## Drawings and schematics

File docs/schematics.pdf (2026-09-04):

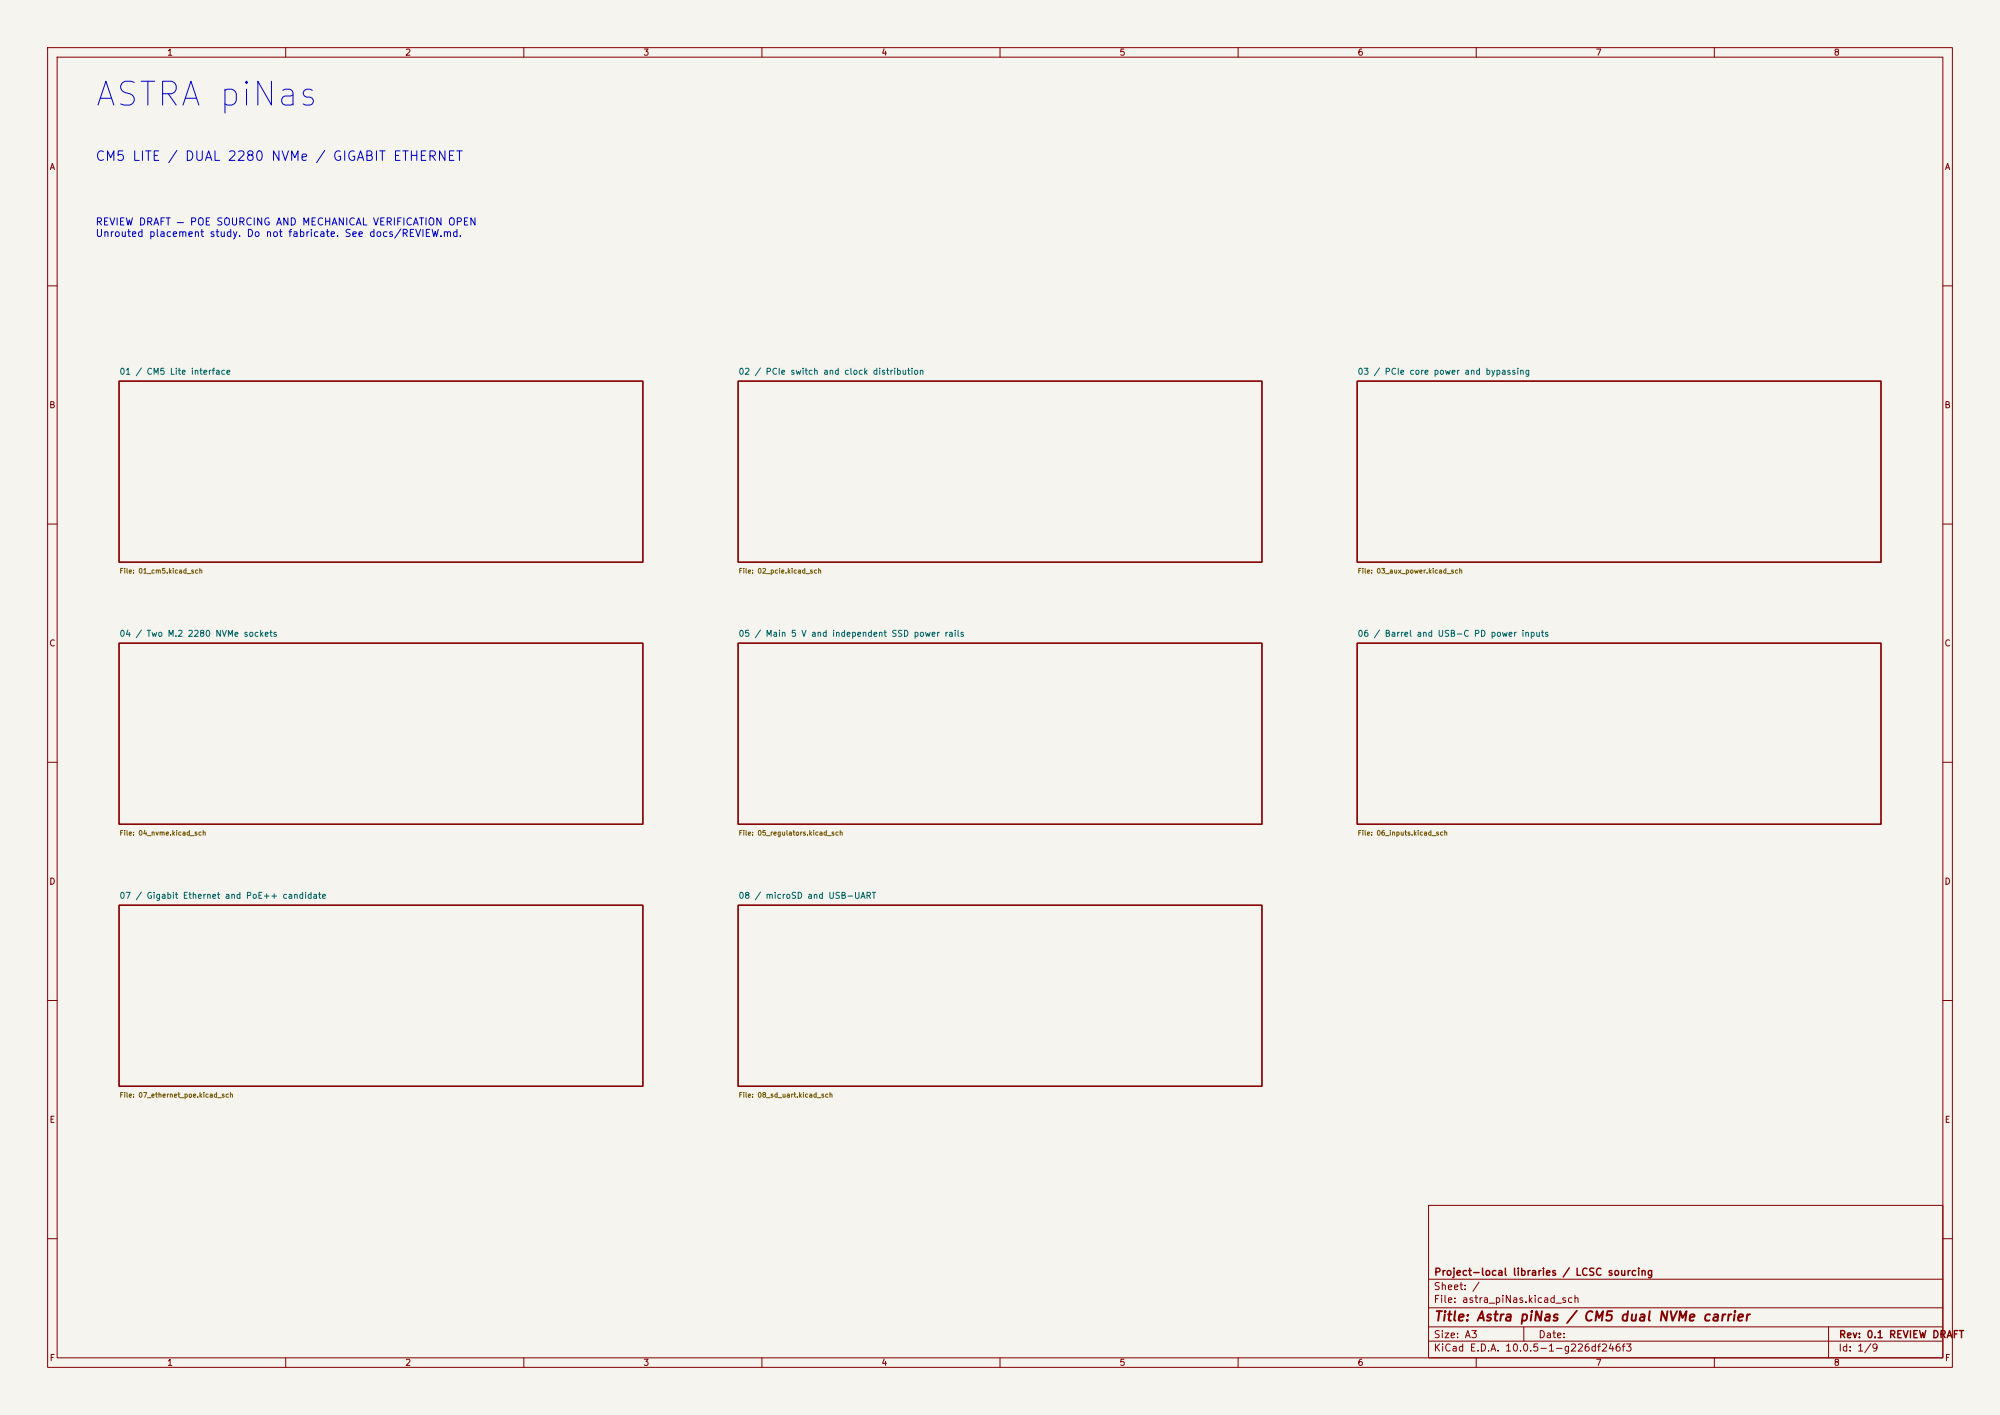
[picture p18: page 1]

CM5 LITE / DUAL 2280 NVMe / GIGABIT ETHERNET

REVIEW DRAFT — POE SOURCING AND MECHANICAL VERIFICATION OPEN
Unrouted placement study. Do not fabricate. See docs/REVIEW.md.

02 / PCIe switch and clock distribution

File: 01_cm5.kicad_sch 04 / Two M.2 2280 NVMe sockets

File: 03_aux_power.kicad_sch 05 / Main 5 V and independent SSD power rails

File: 04_nvme.kicad_sch 07 / Gigabit Ethernet and PoE++ candidate

File: 06_inputs.kicad_sch 08 / microSD and USB-UART

Project-local libraries / LCSC sourcing
Sheet: /
File: astra_piNas.kicad_sch
Title: Astra piNas / CM5 dual NVMe carrier

F Date:

KiCad E.D.A. 10.0.5-1-g226df246f3 | Id: 1/9

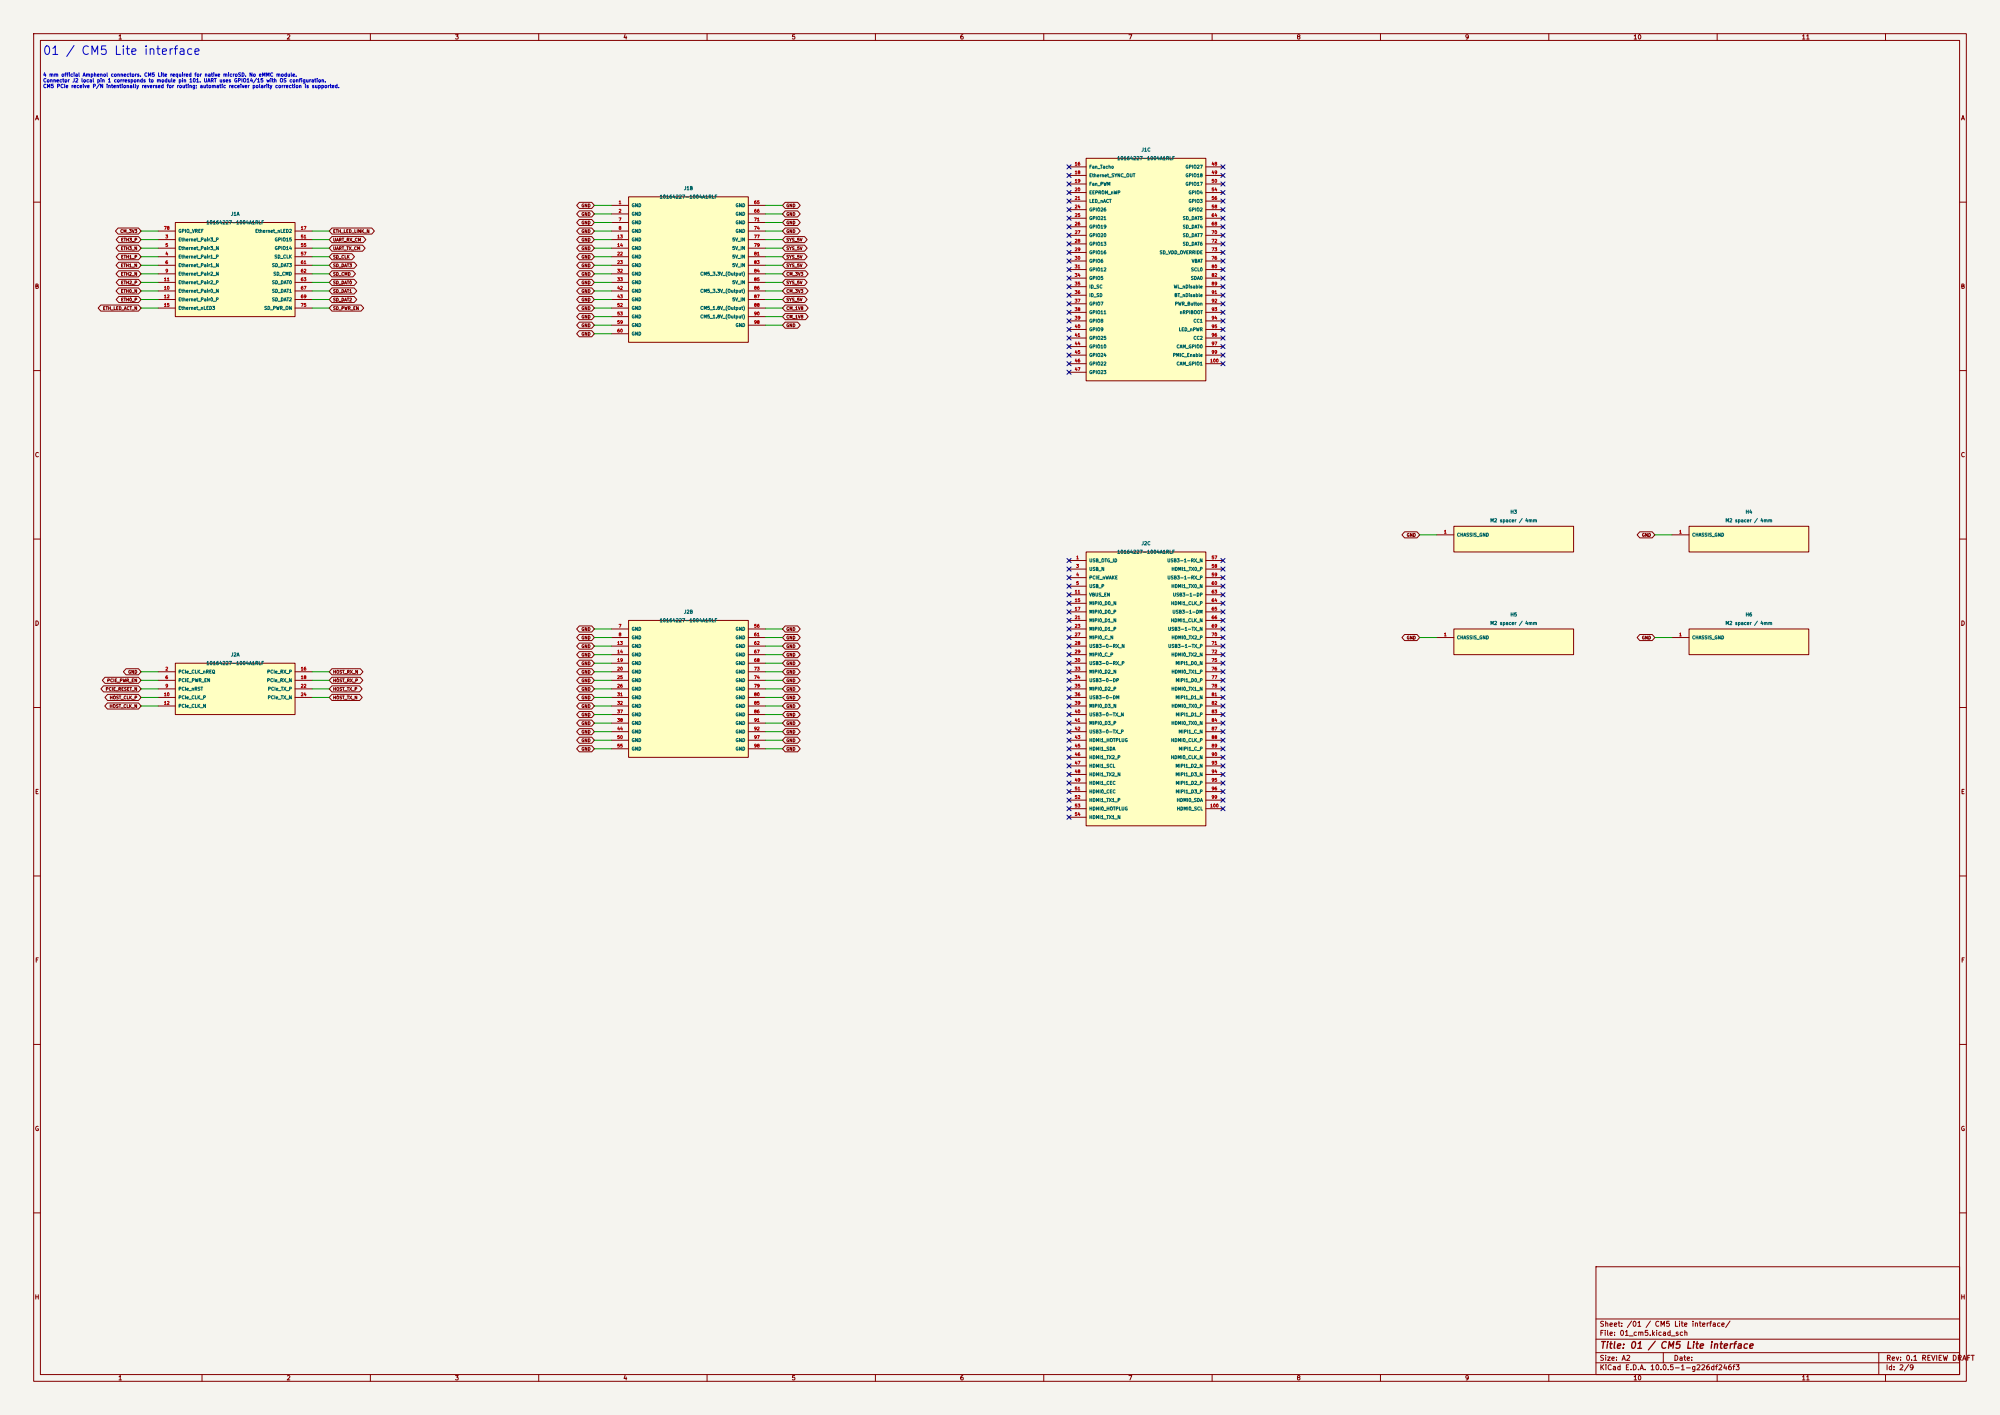
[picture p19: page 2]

4 mm official Amphenol connectors. CM5 Lite required for native microSD. No eMMC module. Connector J2 local pin 1 corresponds to module pin 101. UART uses GPIO14/15 with OS configuration. CM5 PCIe receive P/N intentionally reversed for routing; automatic receiver polarity correction is supported.

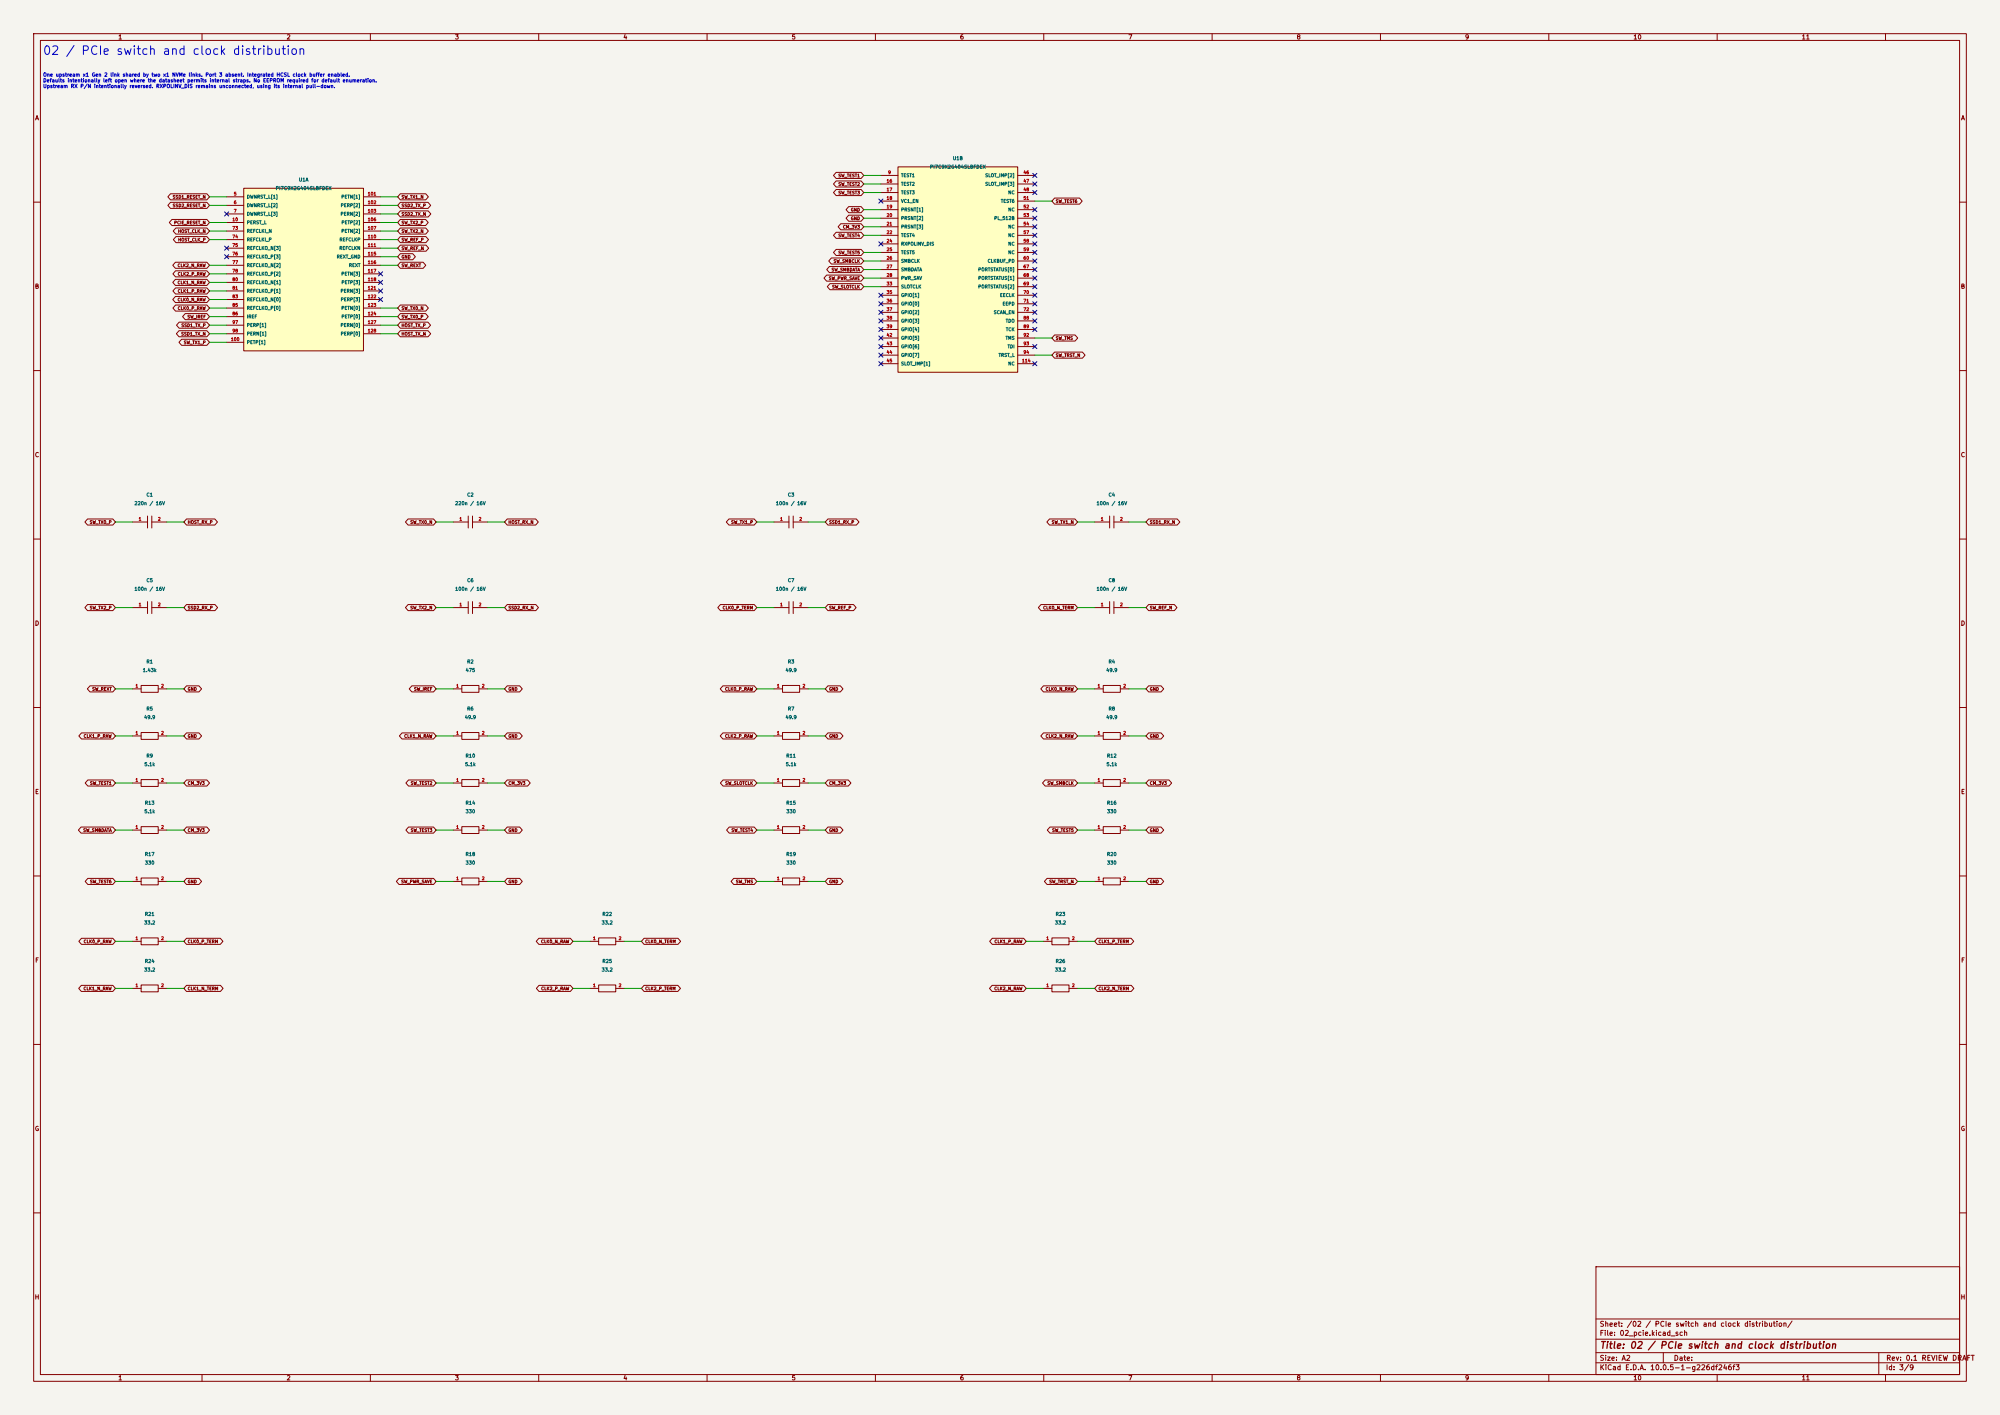
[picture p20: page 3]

SSD1_TX_N 02 / PCIe switch and clock distribution

One upstream x1 Gen 2 link shared by two x1 NVMe links. Port 3 absent. Integrated HCSL clock buffer enabled. Defaults intentionally left open where the datasheet permits internal straps. No EEPROM required for default enumeration. Upstream RX P/N intentionally reversed. RXPOLINV_DIS remains unconnected, using its internal pull-down.

Sheet: /02 / PCIe switch and clock distribution/
File: 02_pcie.kicad_sch
Title: 02 / PCIe switch and clock distribution

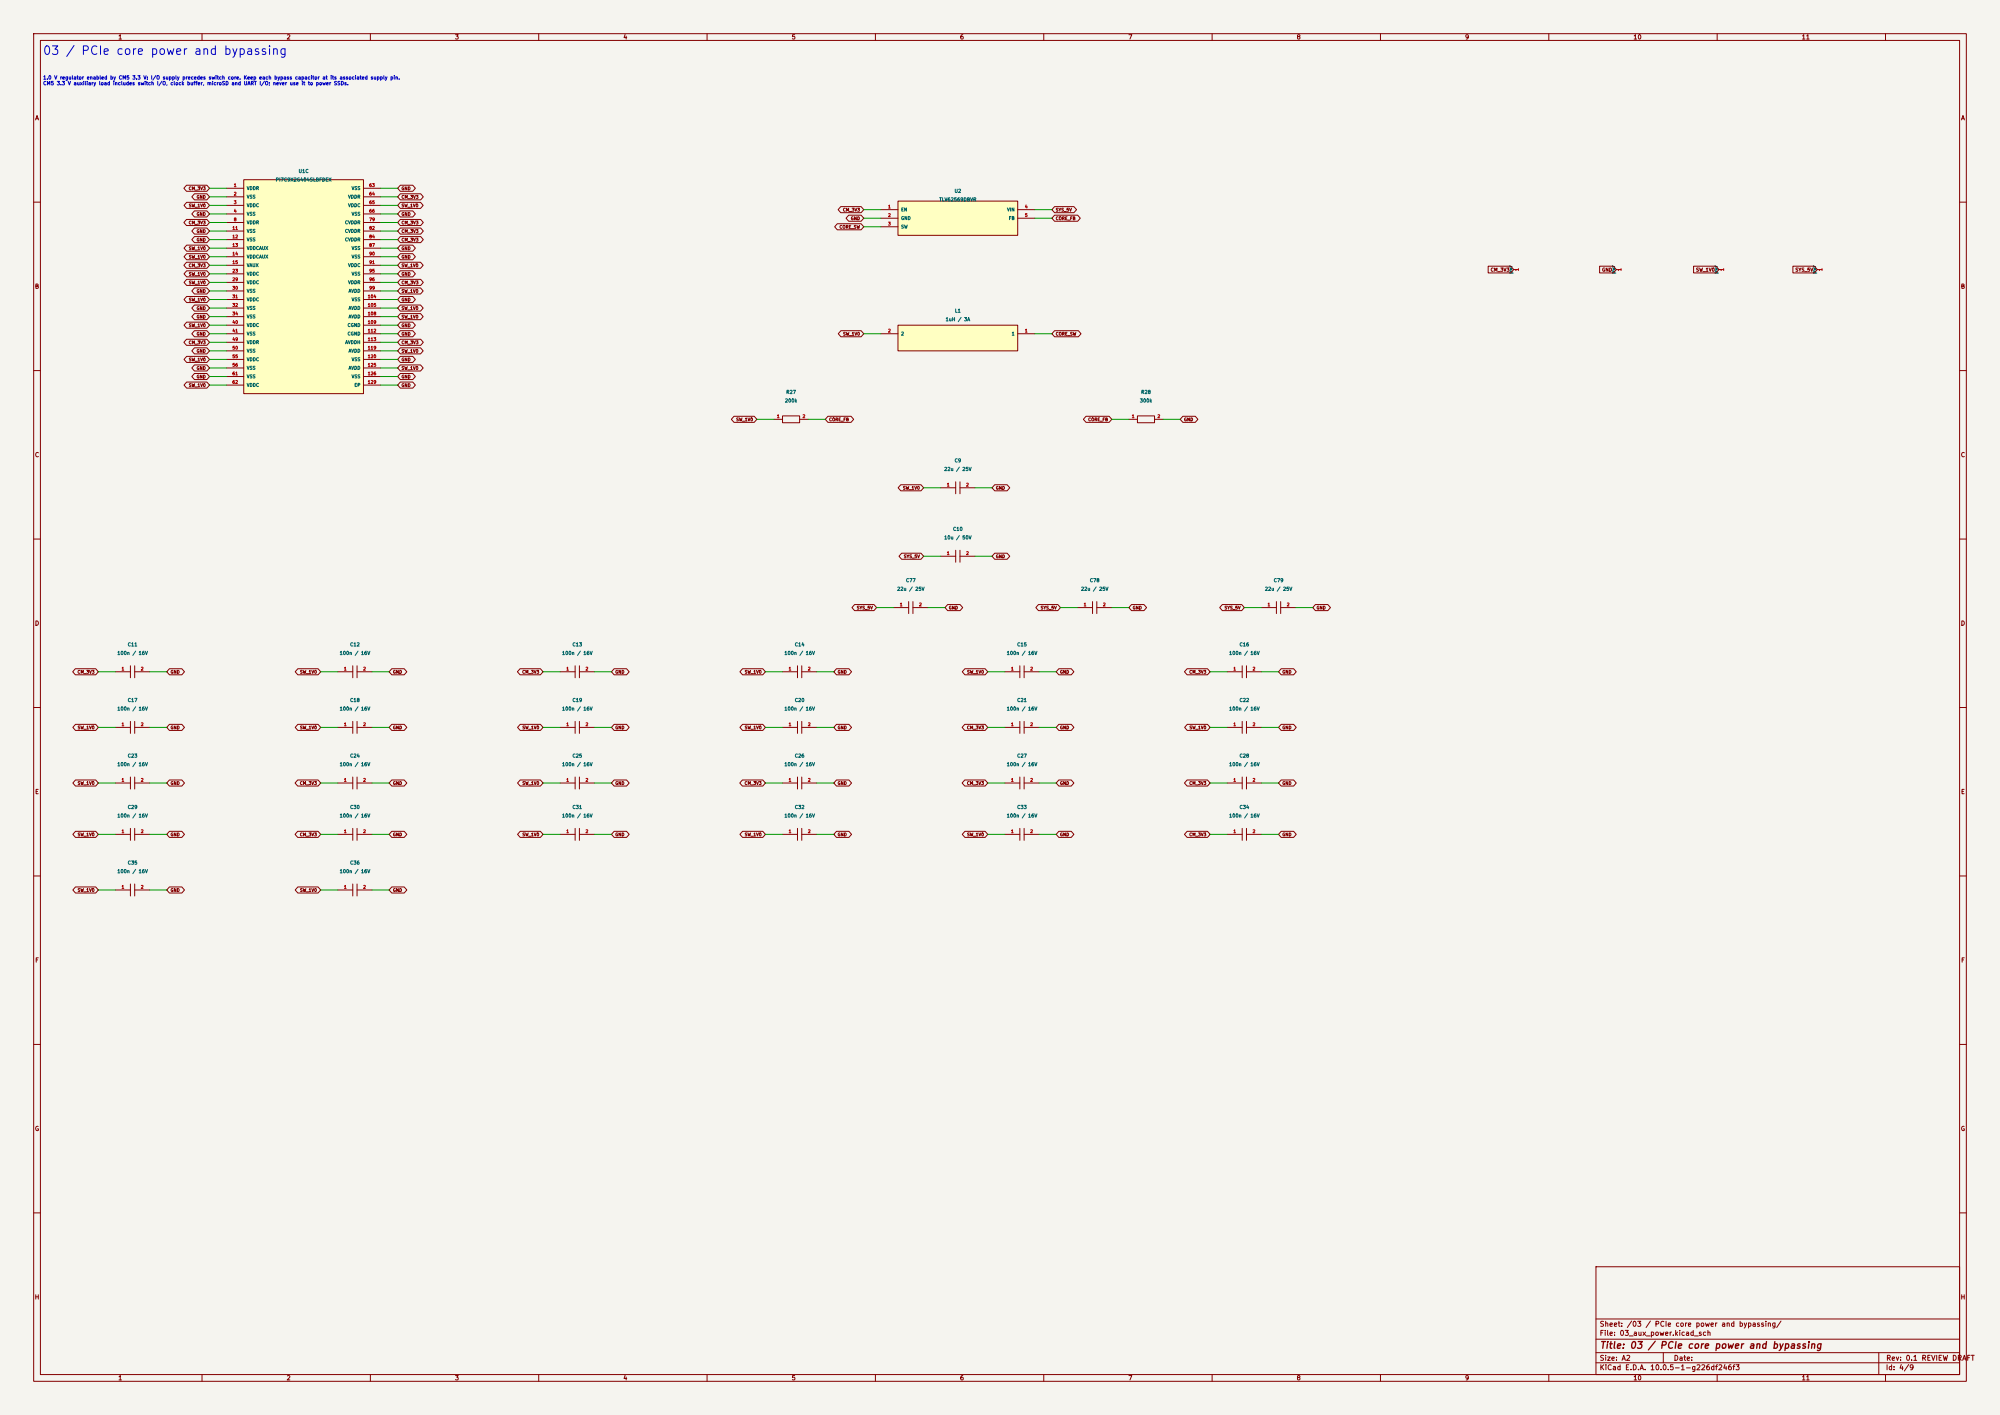
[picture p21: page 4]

GND 03 / PCIe core power and bypassing

1.0 V regulator enabled by CM5 3.3 V: I/O supply precedes switch core. Keep each bypass capacitor at its associated supply pin. CM5 3.3 V auxiliary load includes switch I/O, clock buffer, microSD and UART I/O; never use it to power SSDs.

Sheet: /03 / PCIe core power and bypassing/
File: 03_aux_power.kicad_sch
Title: 03 / PCIe core power and bypassing

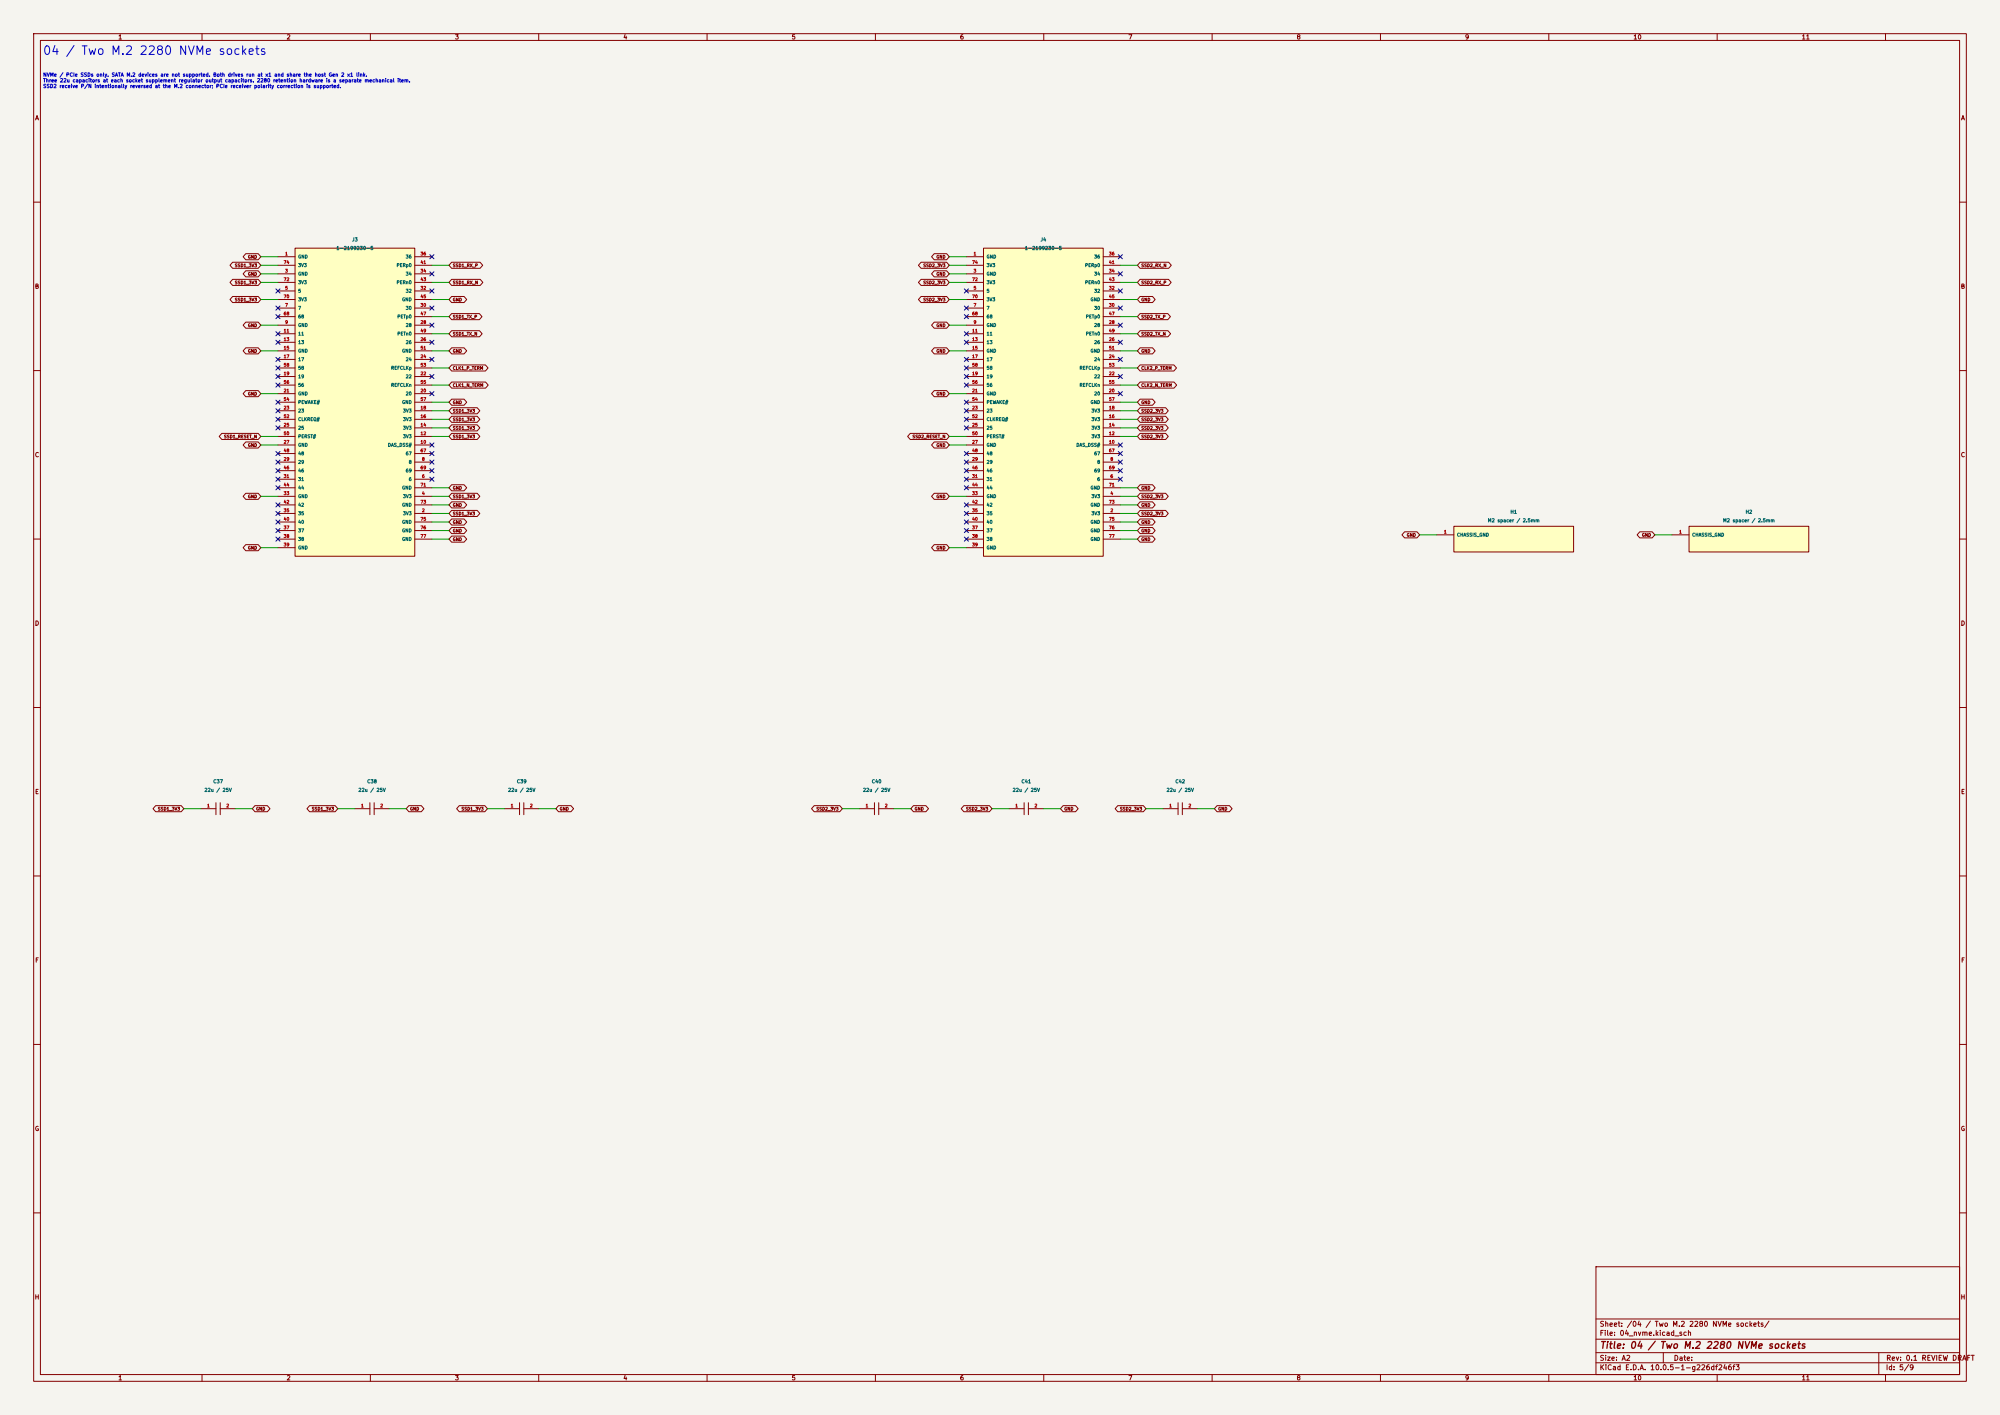
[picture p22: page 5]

GND 04 / Two M.2 2280 NVMe sockets

NVMe / PCIe SSDs only. SATA M.2 devices are not supported. Both drives run at x1 and share the host Gen 2 x1 link. Three 22u capacitors at each socket supplement regulator output capacitors. 2280 retention hardware is a separate mechanical item. SSD2 receive P/N intentionally reversed at the M.2 connector; PCIe receiver polarity correction is supported.

Sheet: /04 / Two M.2 2280 NVMe sockets/
File: 04_nvme.kicad_sch
Title: 04 / Two M.2 2280 NVMe sockets

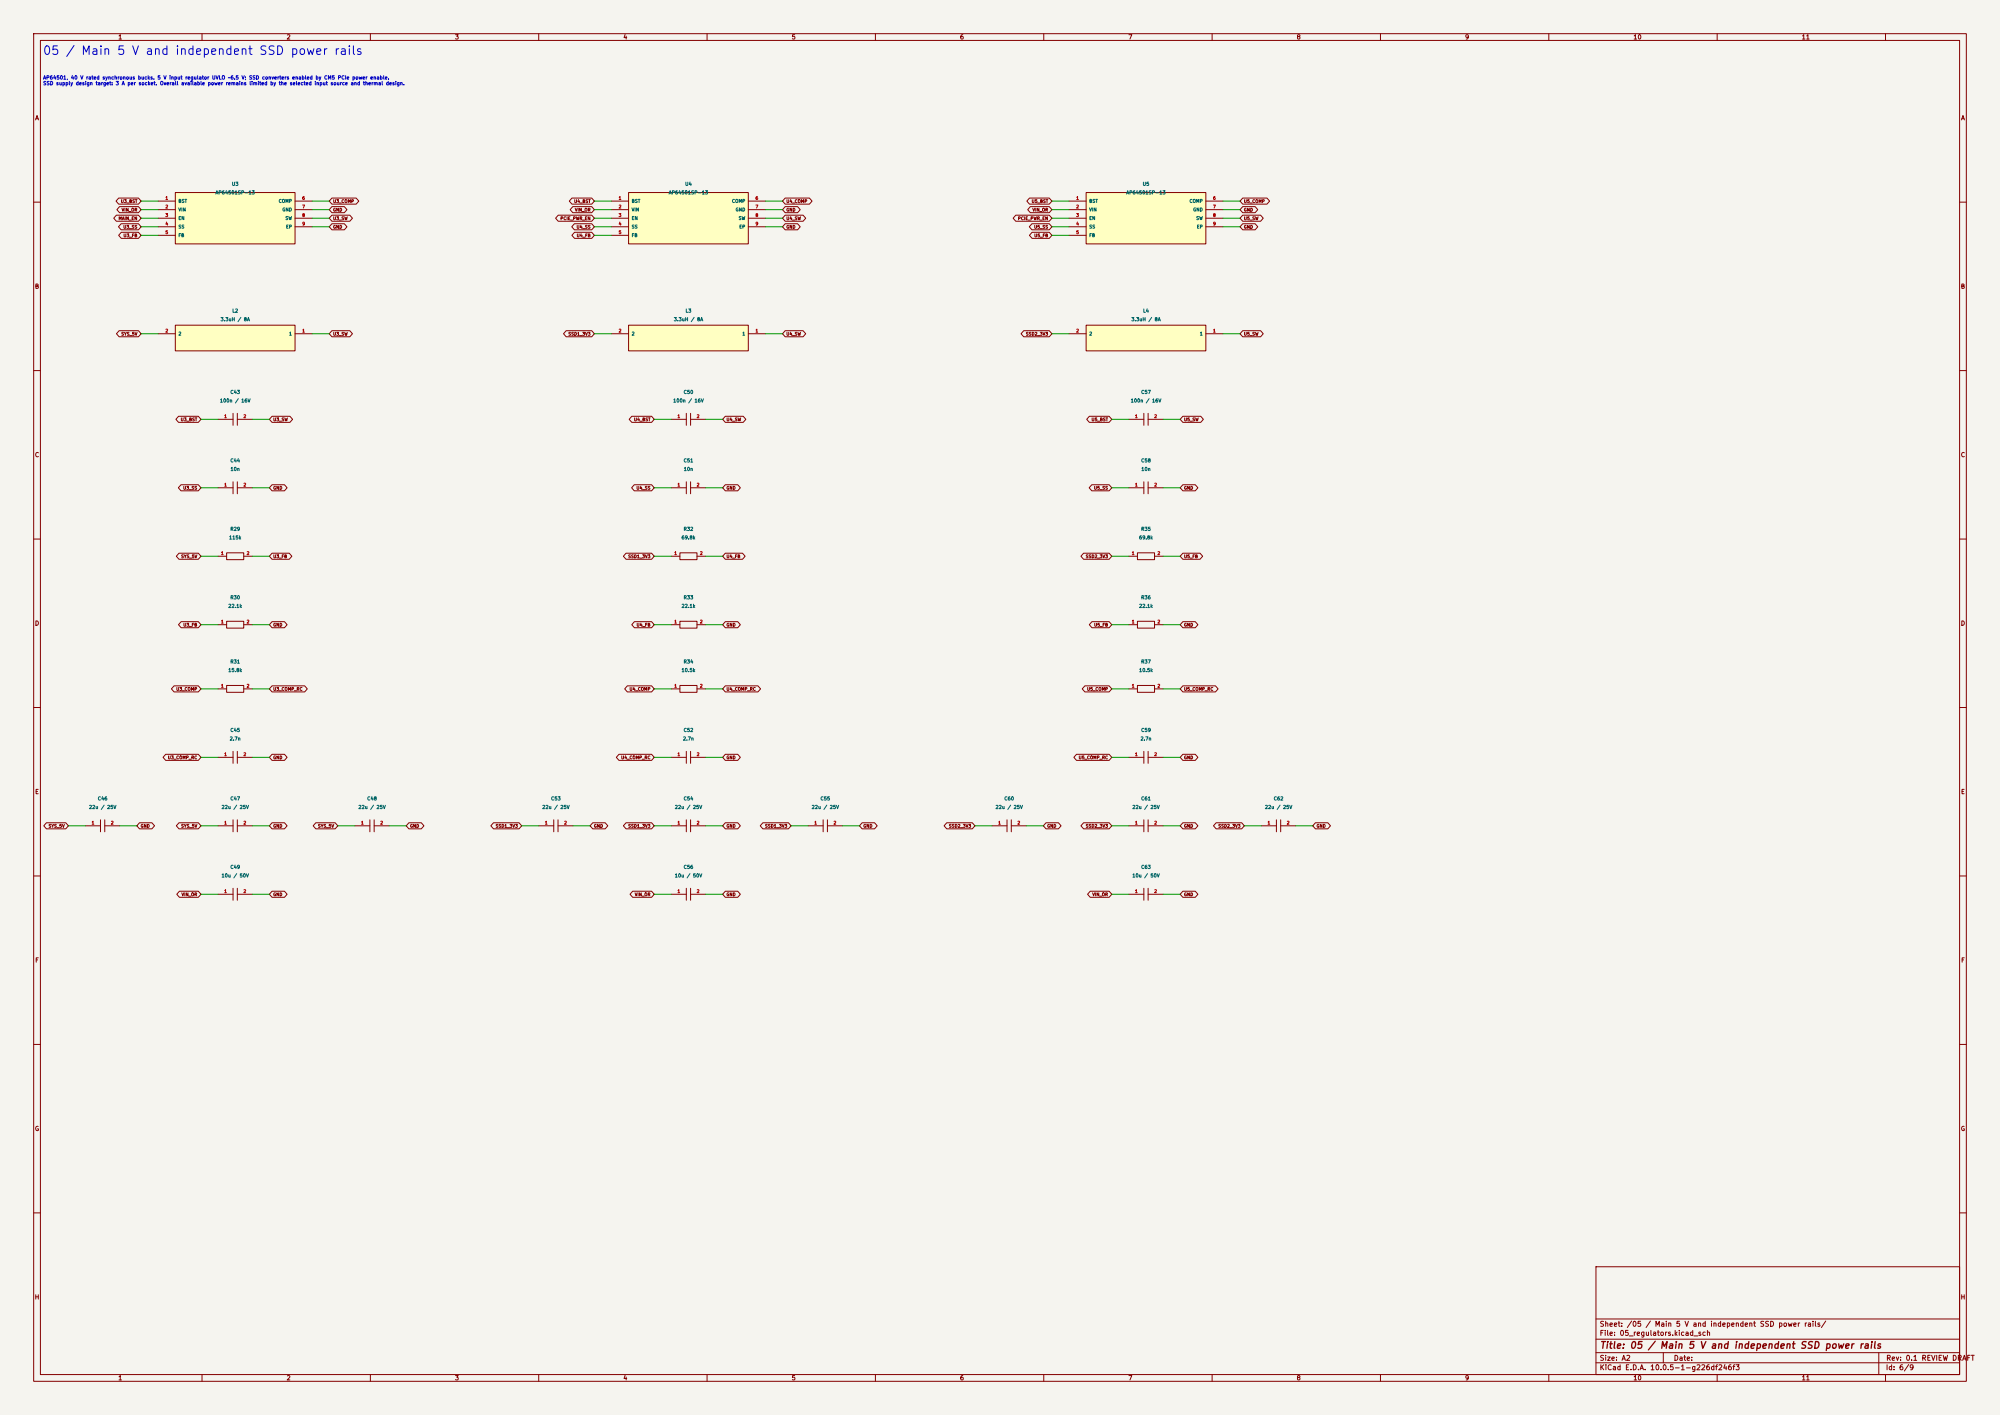
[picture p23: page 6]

AP64501, 40 V rated synchronous bucks. 5 V input regulator UVLO ~6.5 V; SSD converters enabled by CM5 PCIe power enable. SSD supply design target: 3 A per socket. Overall available power remains limited by the selected input source and thermal design. 05 / Main 5 V and independent SSD power rails

Sheet: /05 / Main 5 V and independent SSD power rails/
File: 05_regulators.kicad_sch
Title: 05 / Main 5 V and independent SSD power rails

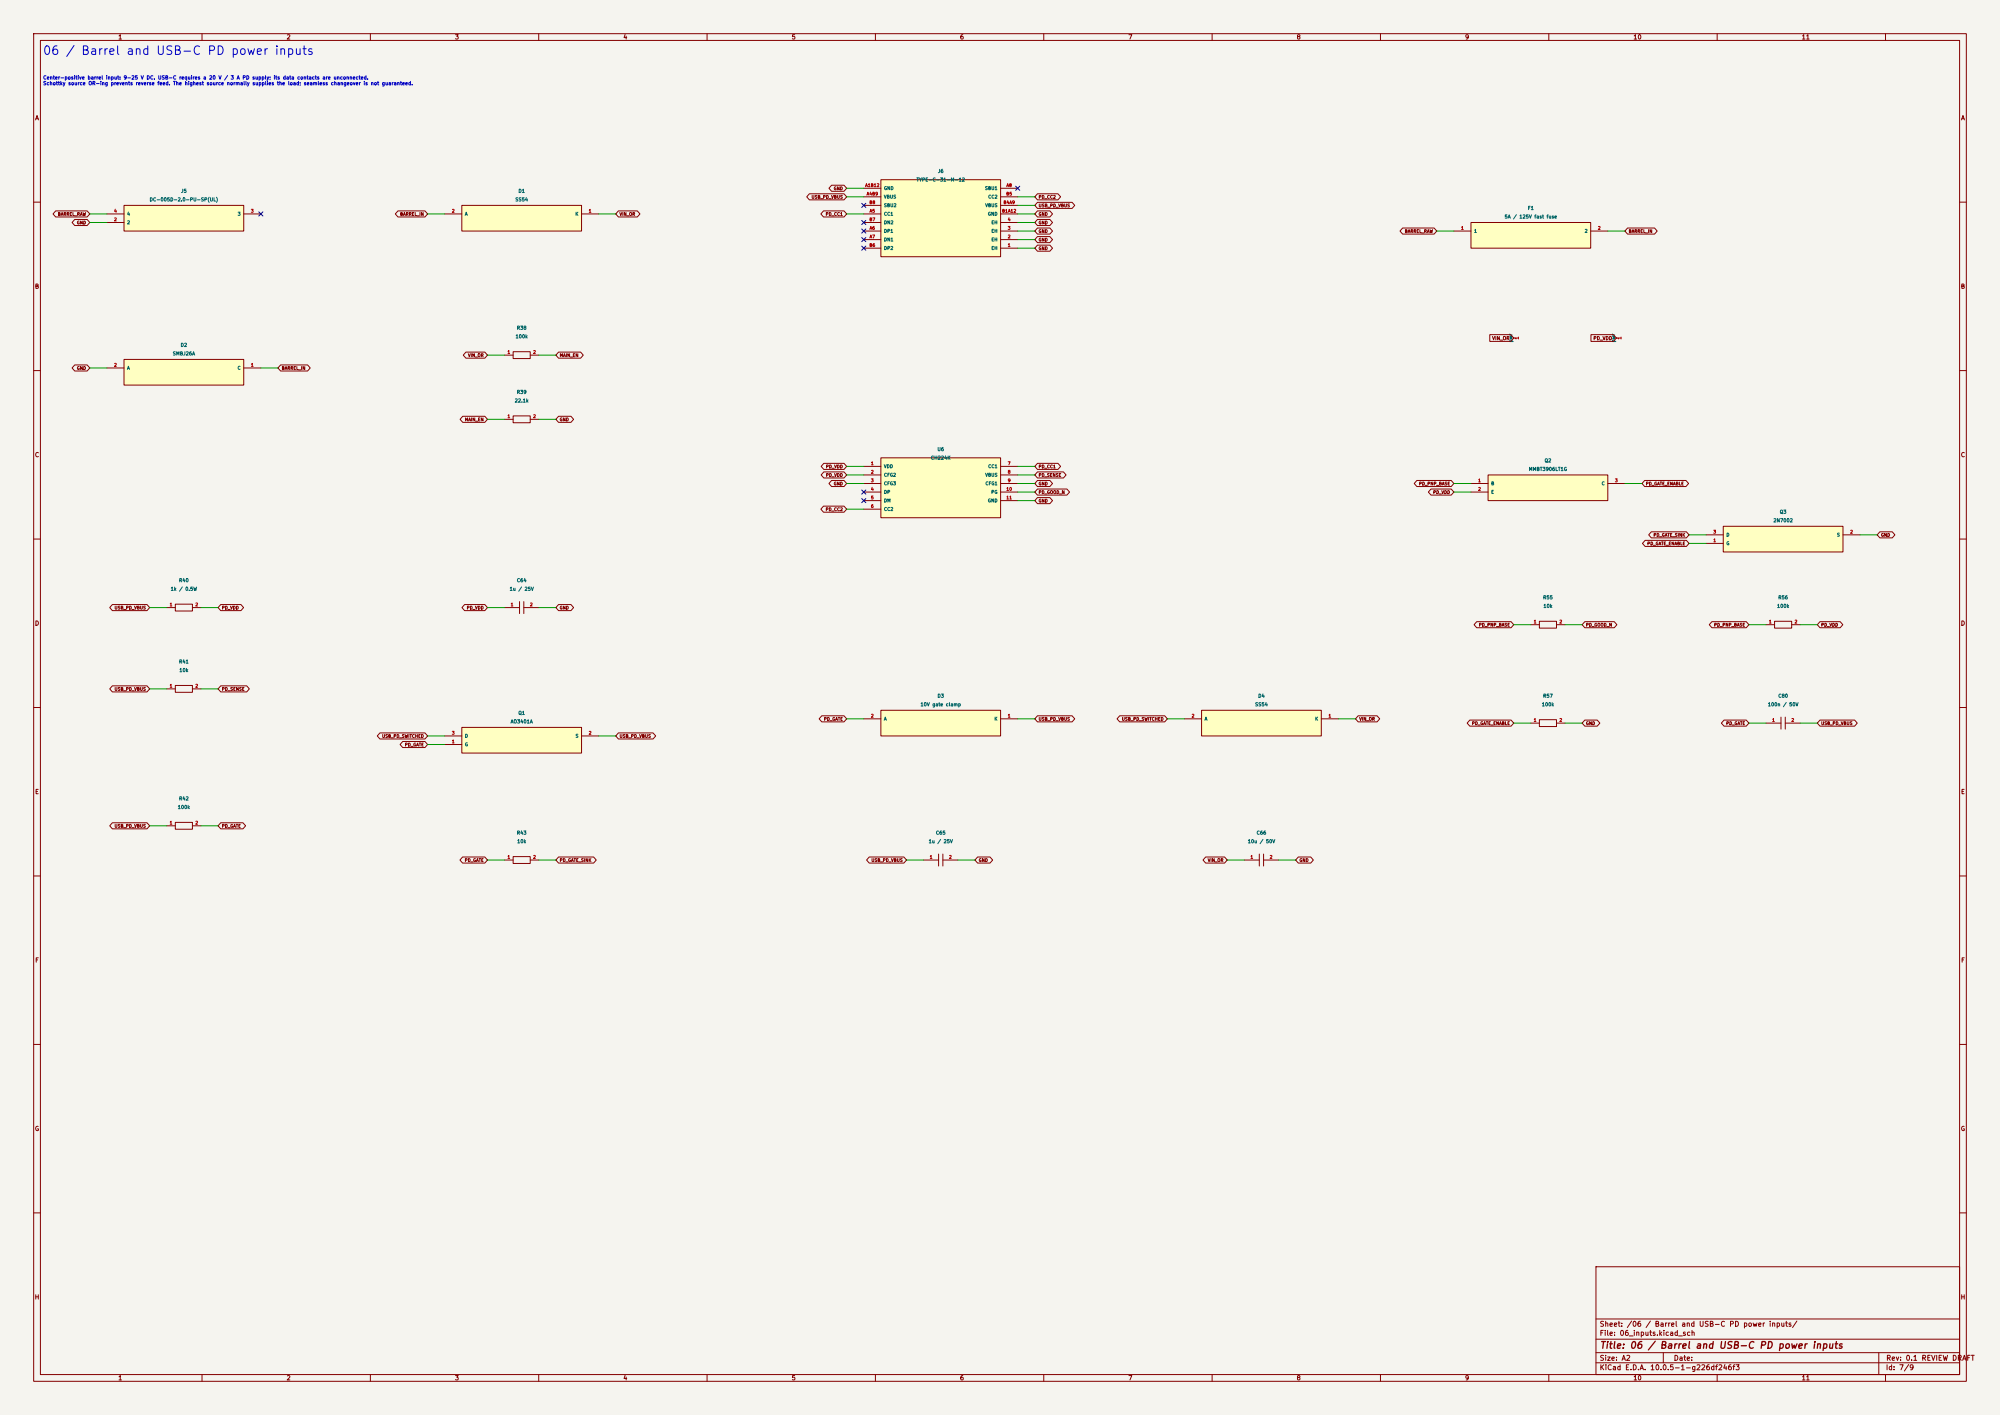
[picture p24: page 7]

06 / Barrel and USB-C PD power inputs

Center-positive barrel input: 9-25 V DC. USB-C requires a 20 V / 3 A PD supply; its data contacts are unconnected. Schottky source OR-ing prevents reverse feed. The highest source normally supplies the load; seamless changeover is not guaranteed.

Sheet: /06 / Barrel and USB-C PD power inputs/
File: 06_inputs.kicad_sch
Title: 06 / Barrel and USB-C PD power inputs

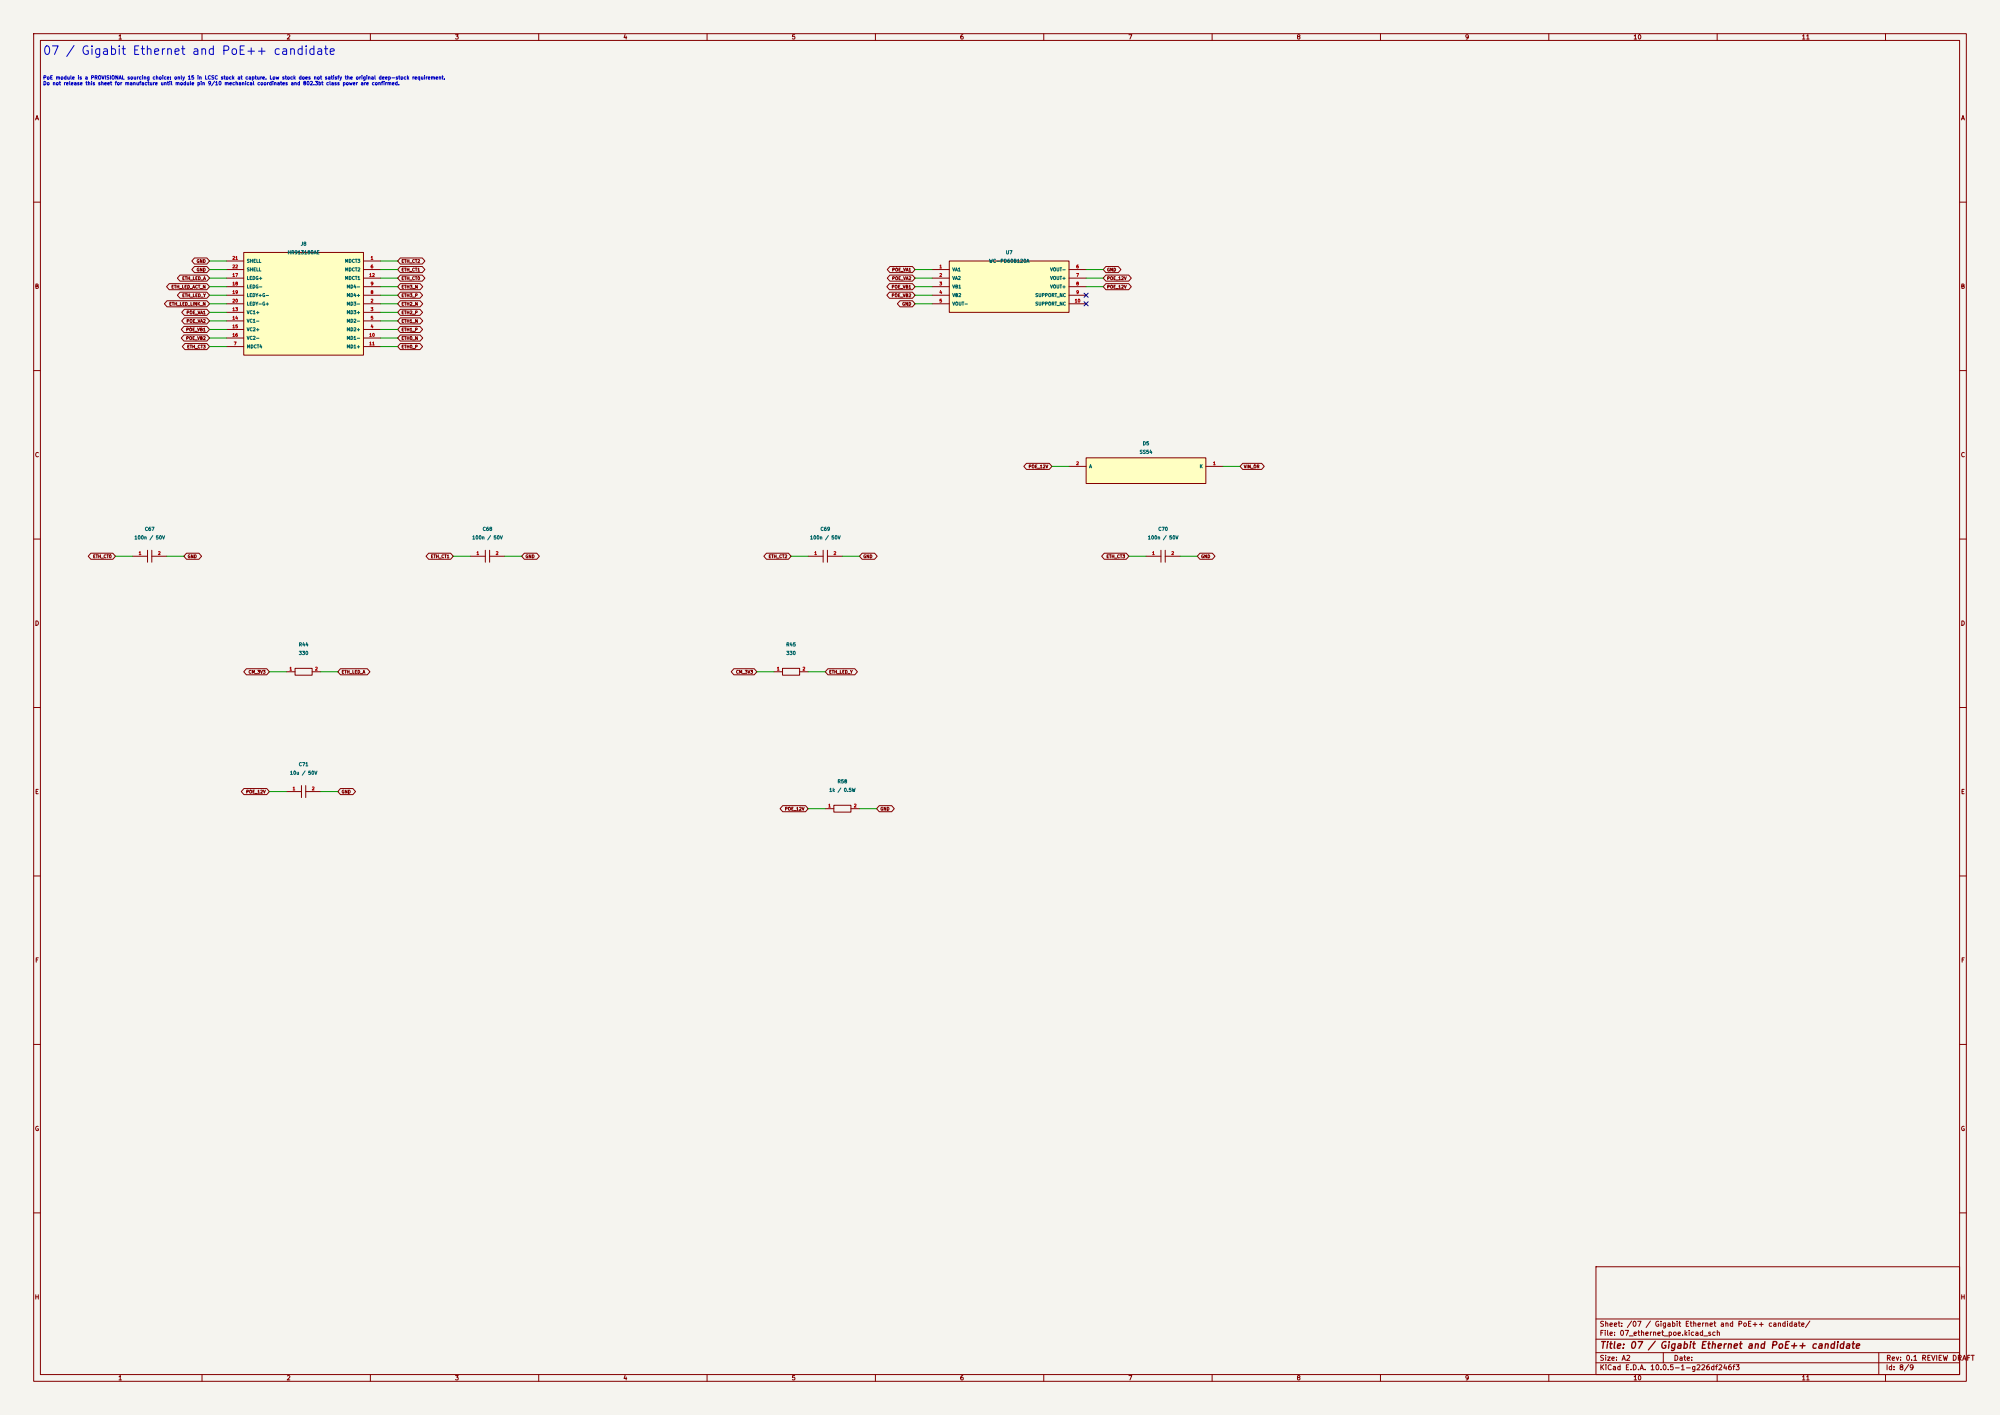
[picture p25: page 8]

POE_VB1 07 / Gigabit Ethernet and PoE++ candidate

PoE module is a PROVISIONAL sourcing choice: only 15 in LCSC stock at capture. Low stock does not satisfy the original deep-stock requirement. Do not release this sheet for manufacture until module pin 9/10 mechanical coordinates and 802.3bt class power are confirmed.

Sheet: /07 / Gigabit Ethernet and PoE++ candidate/
File: 07_ethernet_poe.kicad_sch
Title: 07 / Gigabit Ethernet and PoE++ candidate

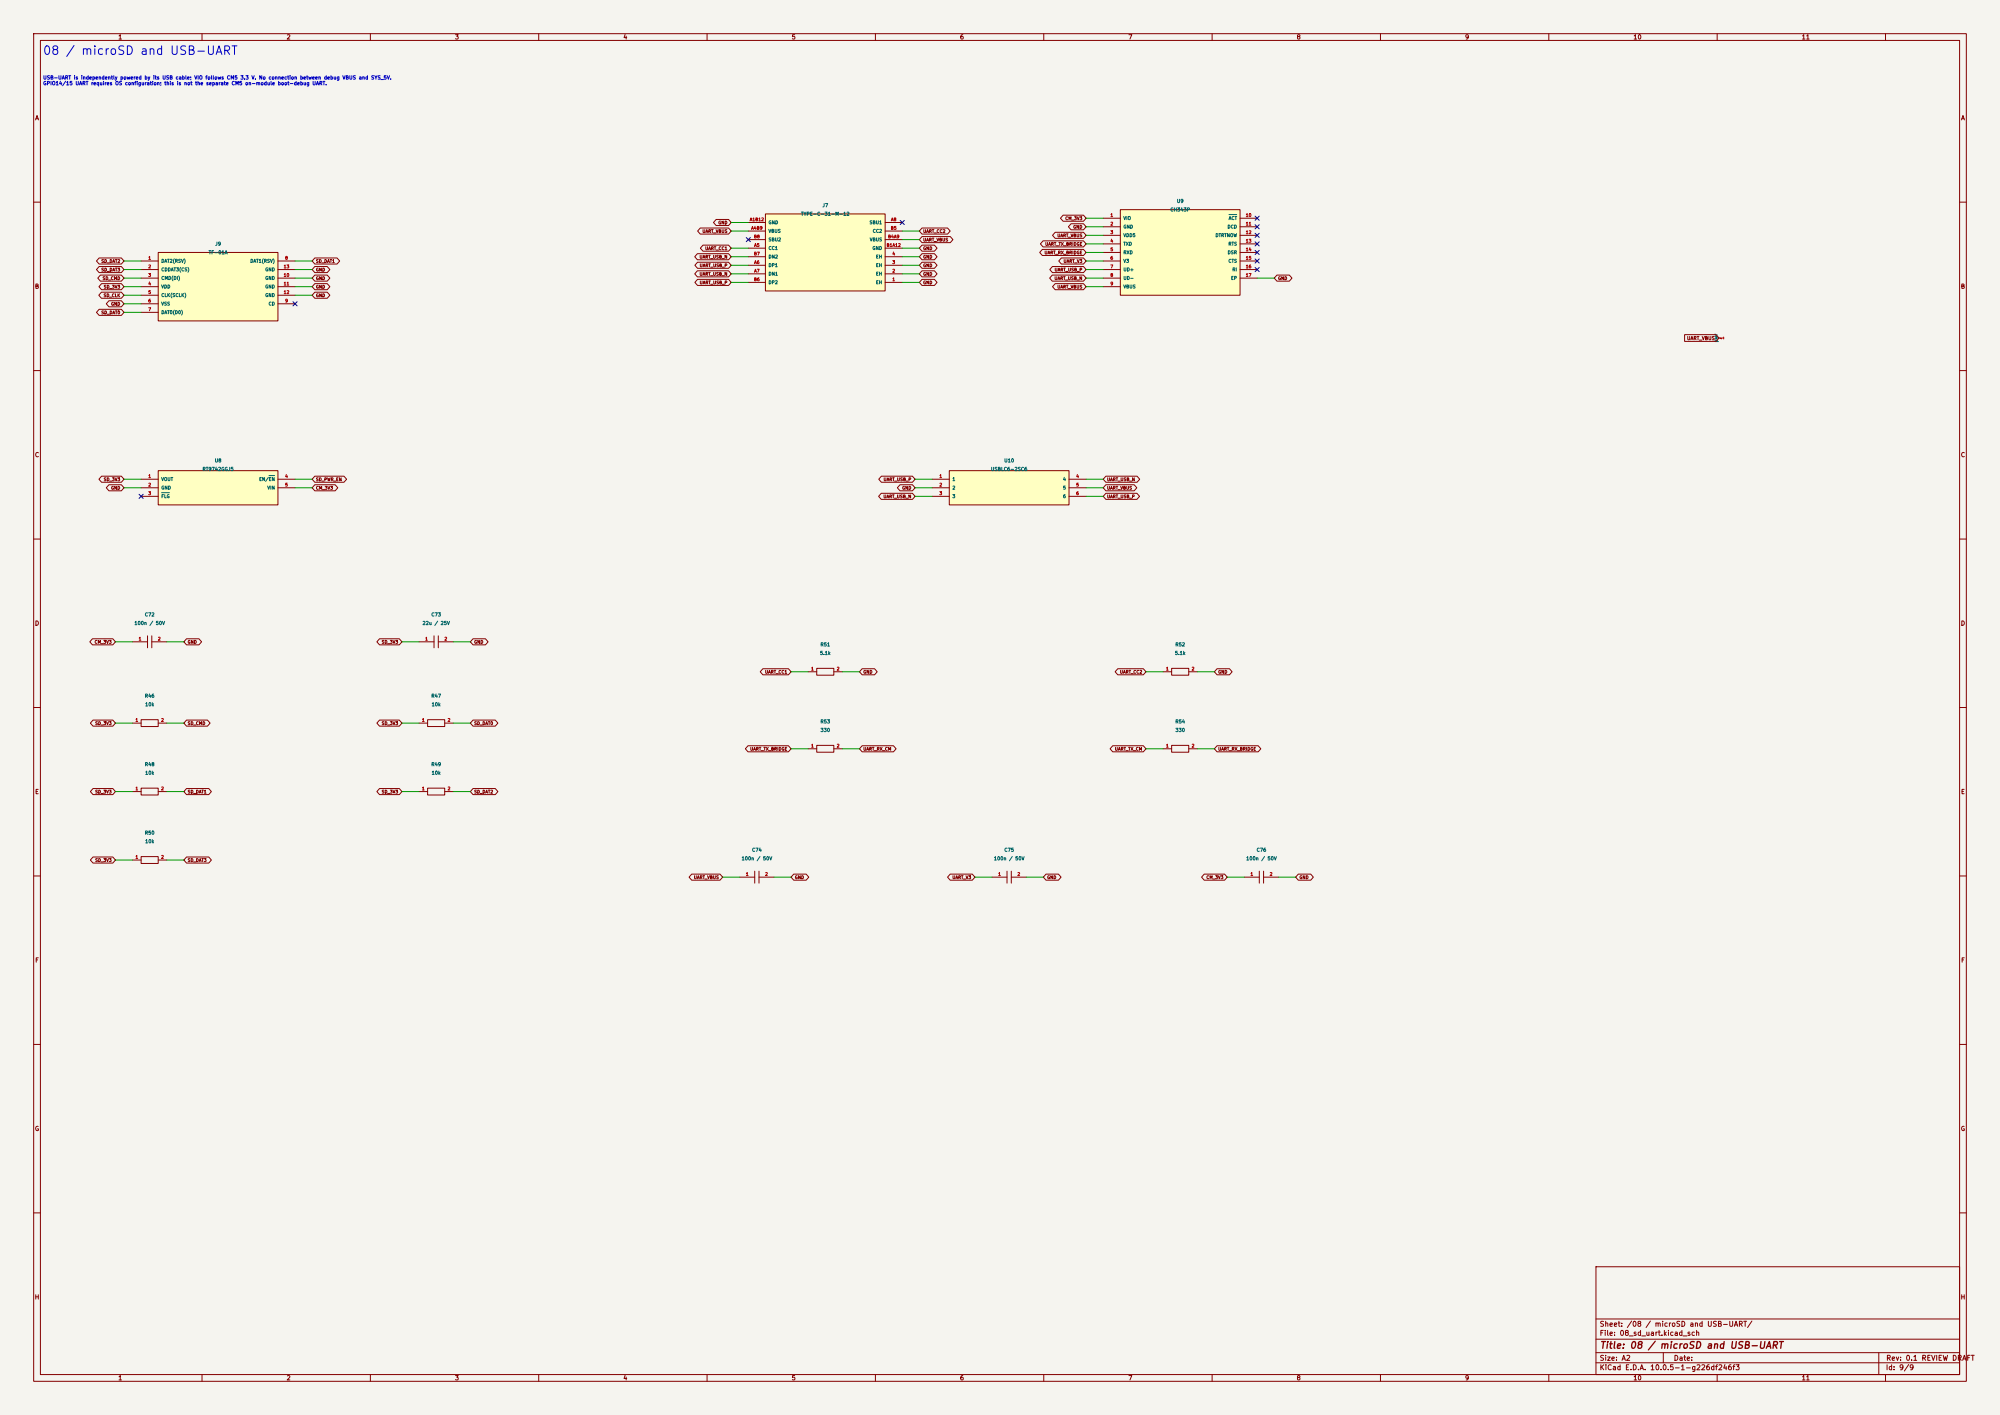
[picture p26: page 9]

SD_CLK 08 / microSD and USB-UART

USB-UART is independently powered by its USB cable; VIO follows CM5 3.3 V. No connection between debug VBUS and SYS_5V. GPIO14/15 UART requires OS configuration; this is not the separate CM5 on-module boot-debug UART.

Sheet: /08 / microSD and USB-UART/
File: 08_sd_uart.kicad_sch
Title: 08 / microSD and USB-UART

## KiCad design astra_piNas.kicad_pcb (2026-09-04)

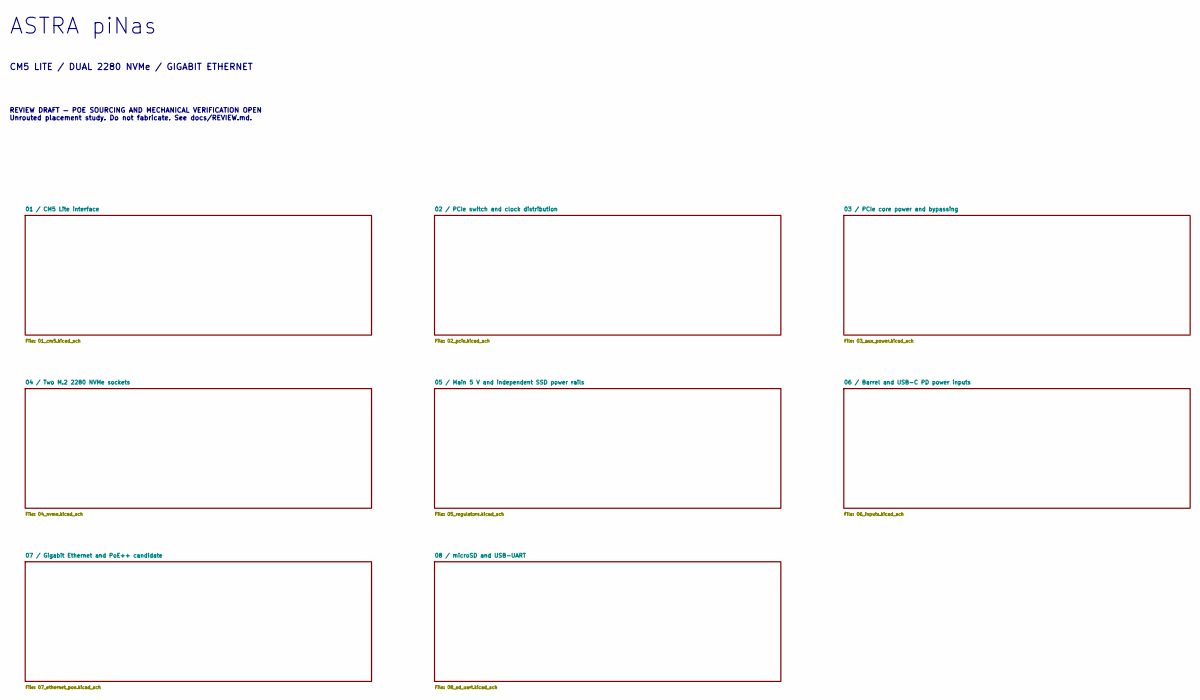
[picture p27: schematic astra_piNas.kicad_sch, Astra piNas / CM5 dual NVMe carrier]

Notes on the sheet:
ASTRA piNas
CM5 LITE / DUAL 2280 NVMe / GIGABIT ETHERNET
REVIEW DRAFT — POE SOURCING AND MECHANICAL VERIFICATION OPEN Unrouted placement study. Do not fabricate. See docs/REVIEW.md.

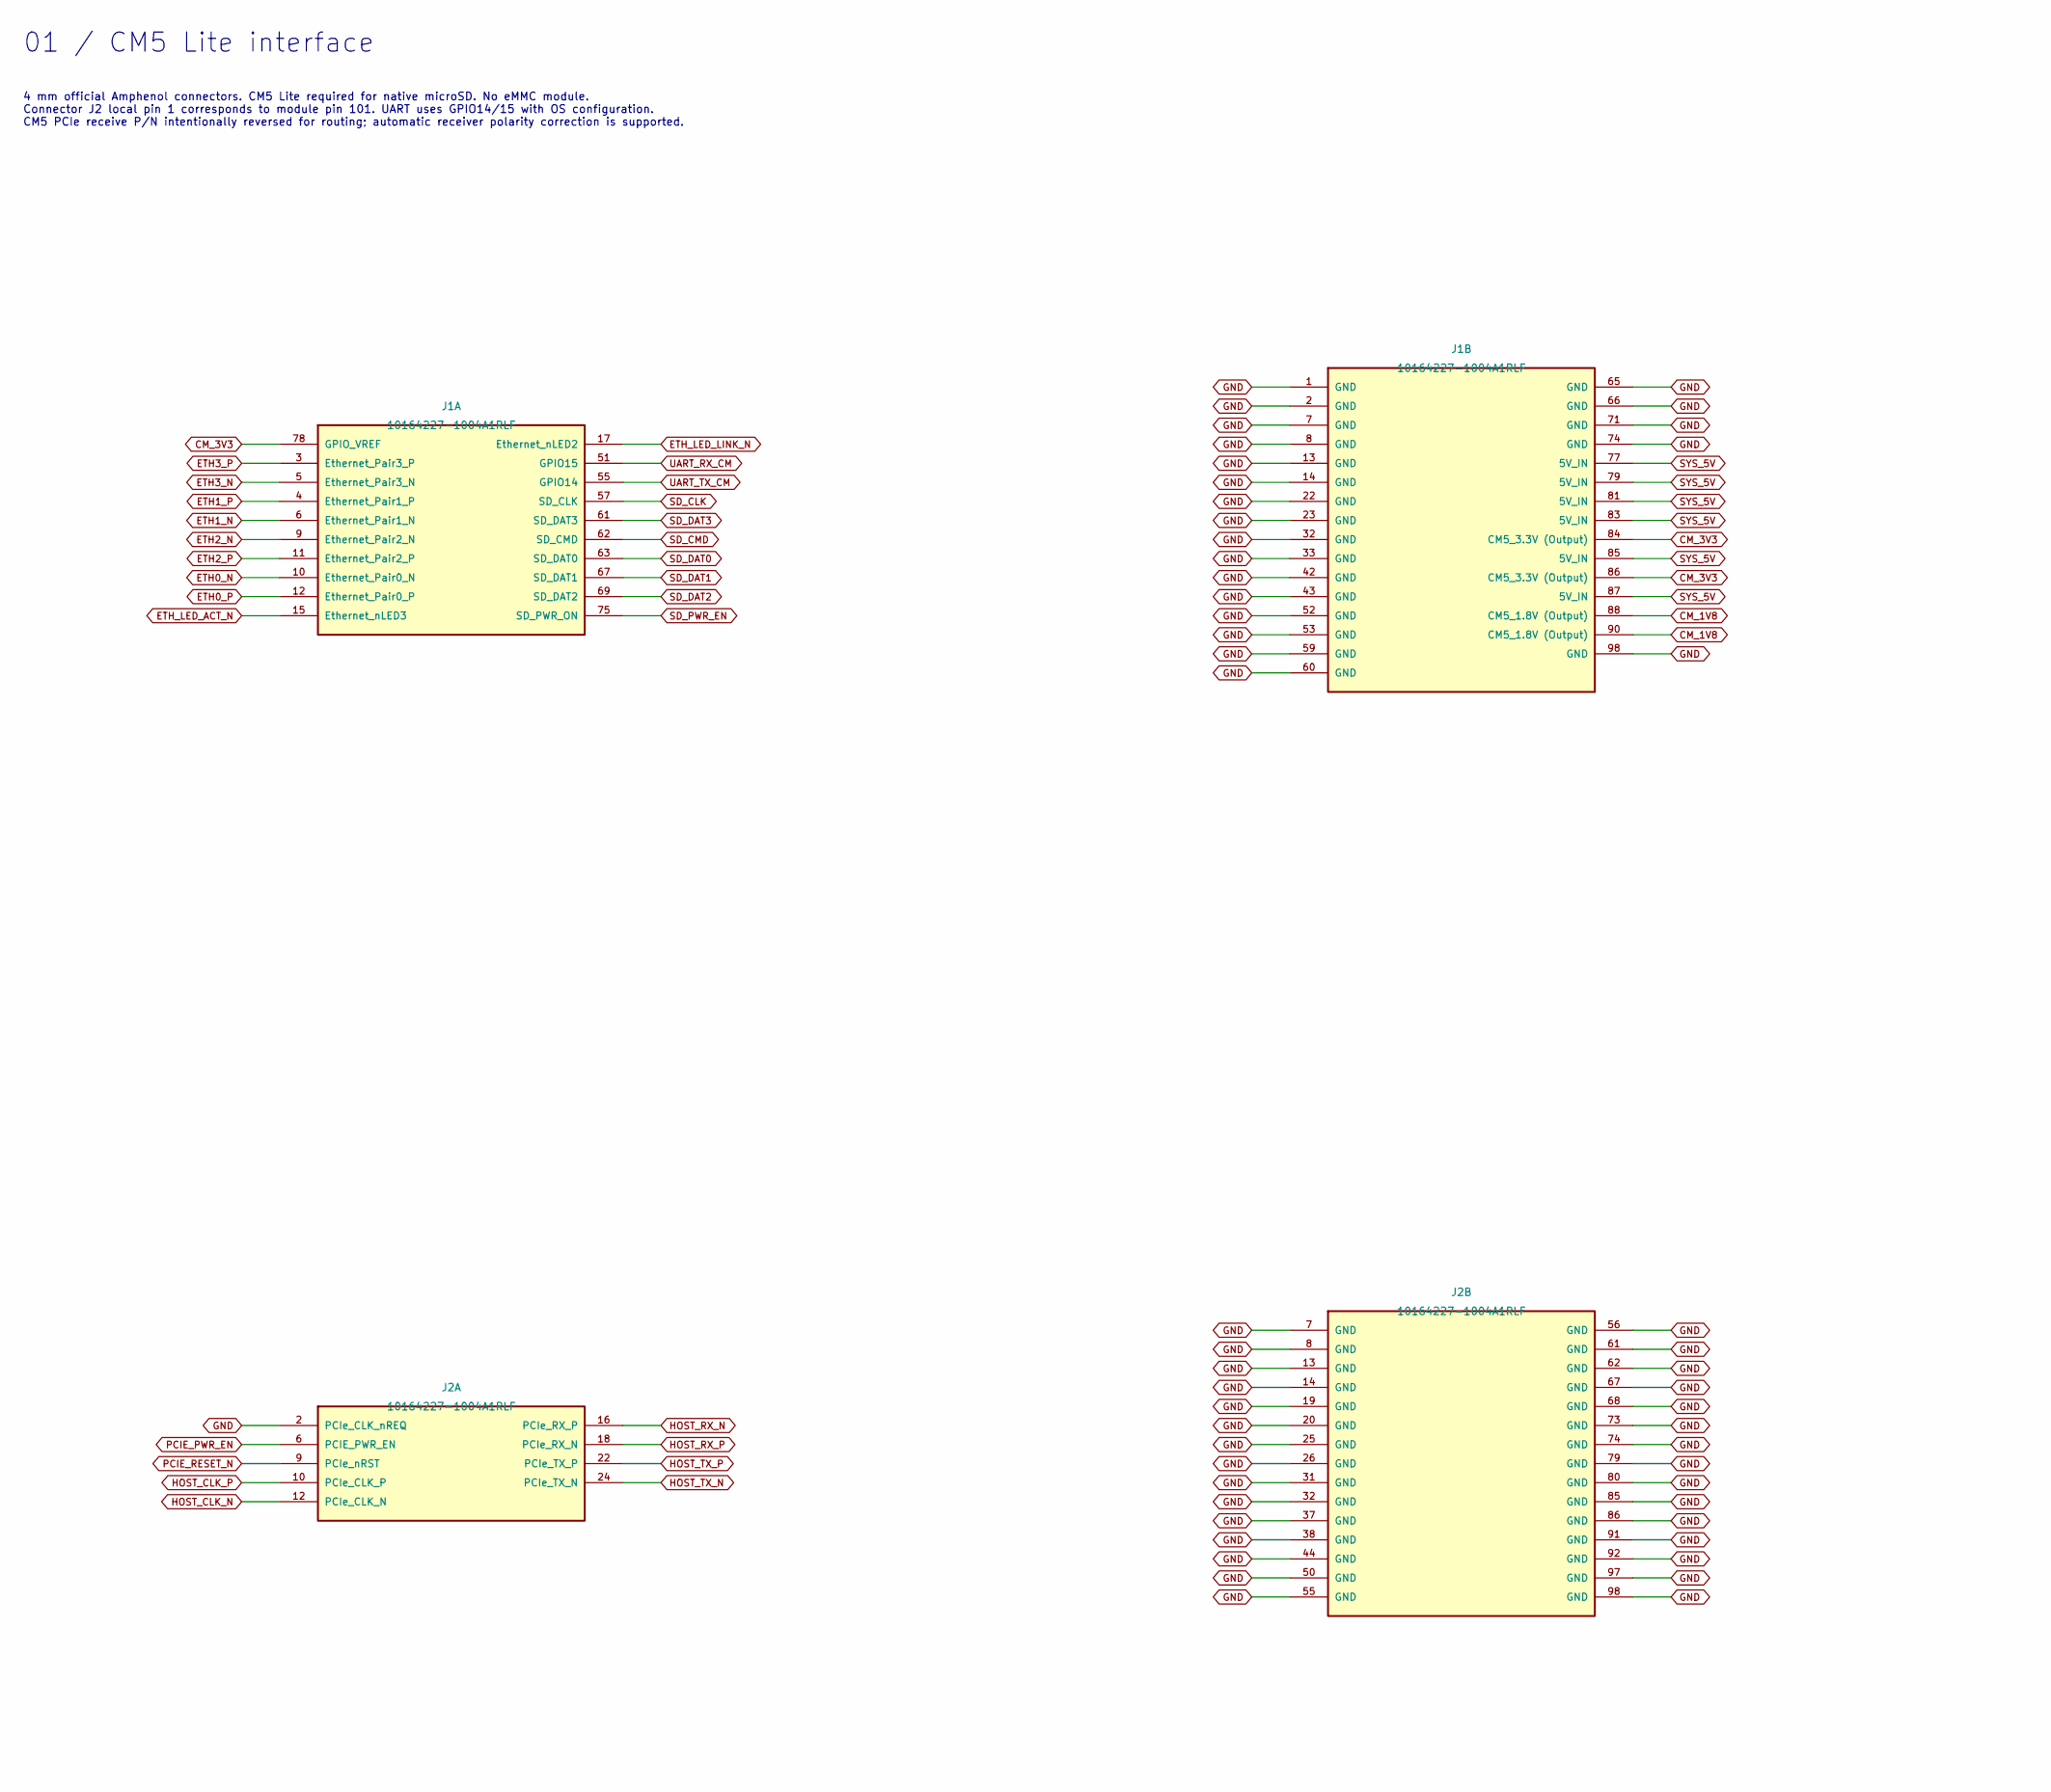
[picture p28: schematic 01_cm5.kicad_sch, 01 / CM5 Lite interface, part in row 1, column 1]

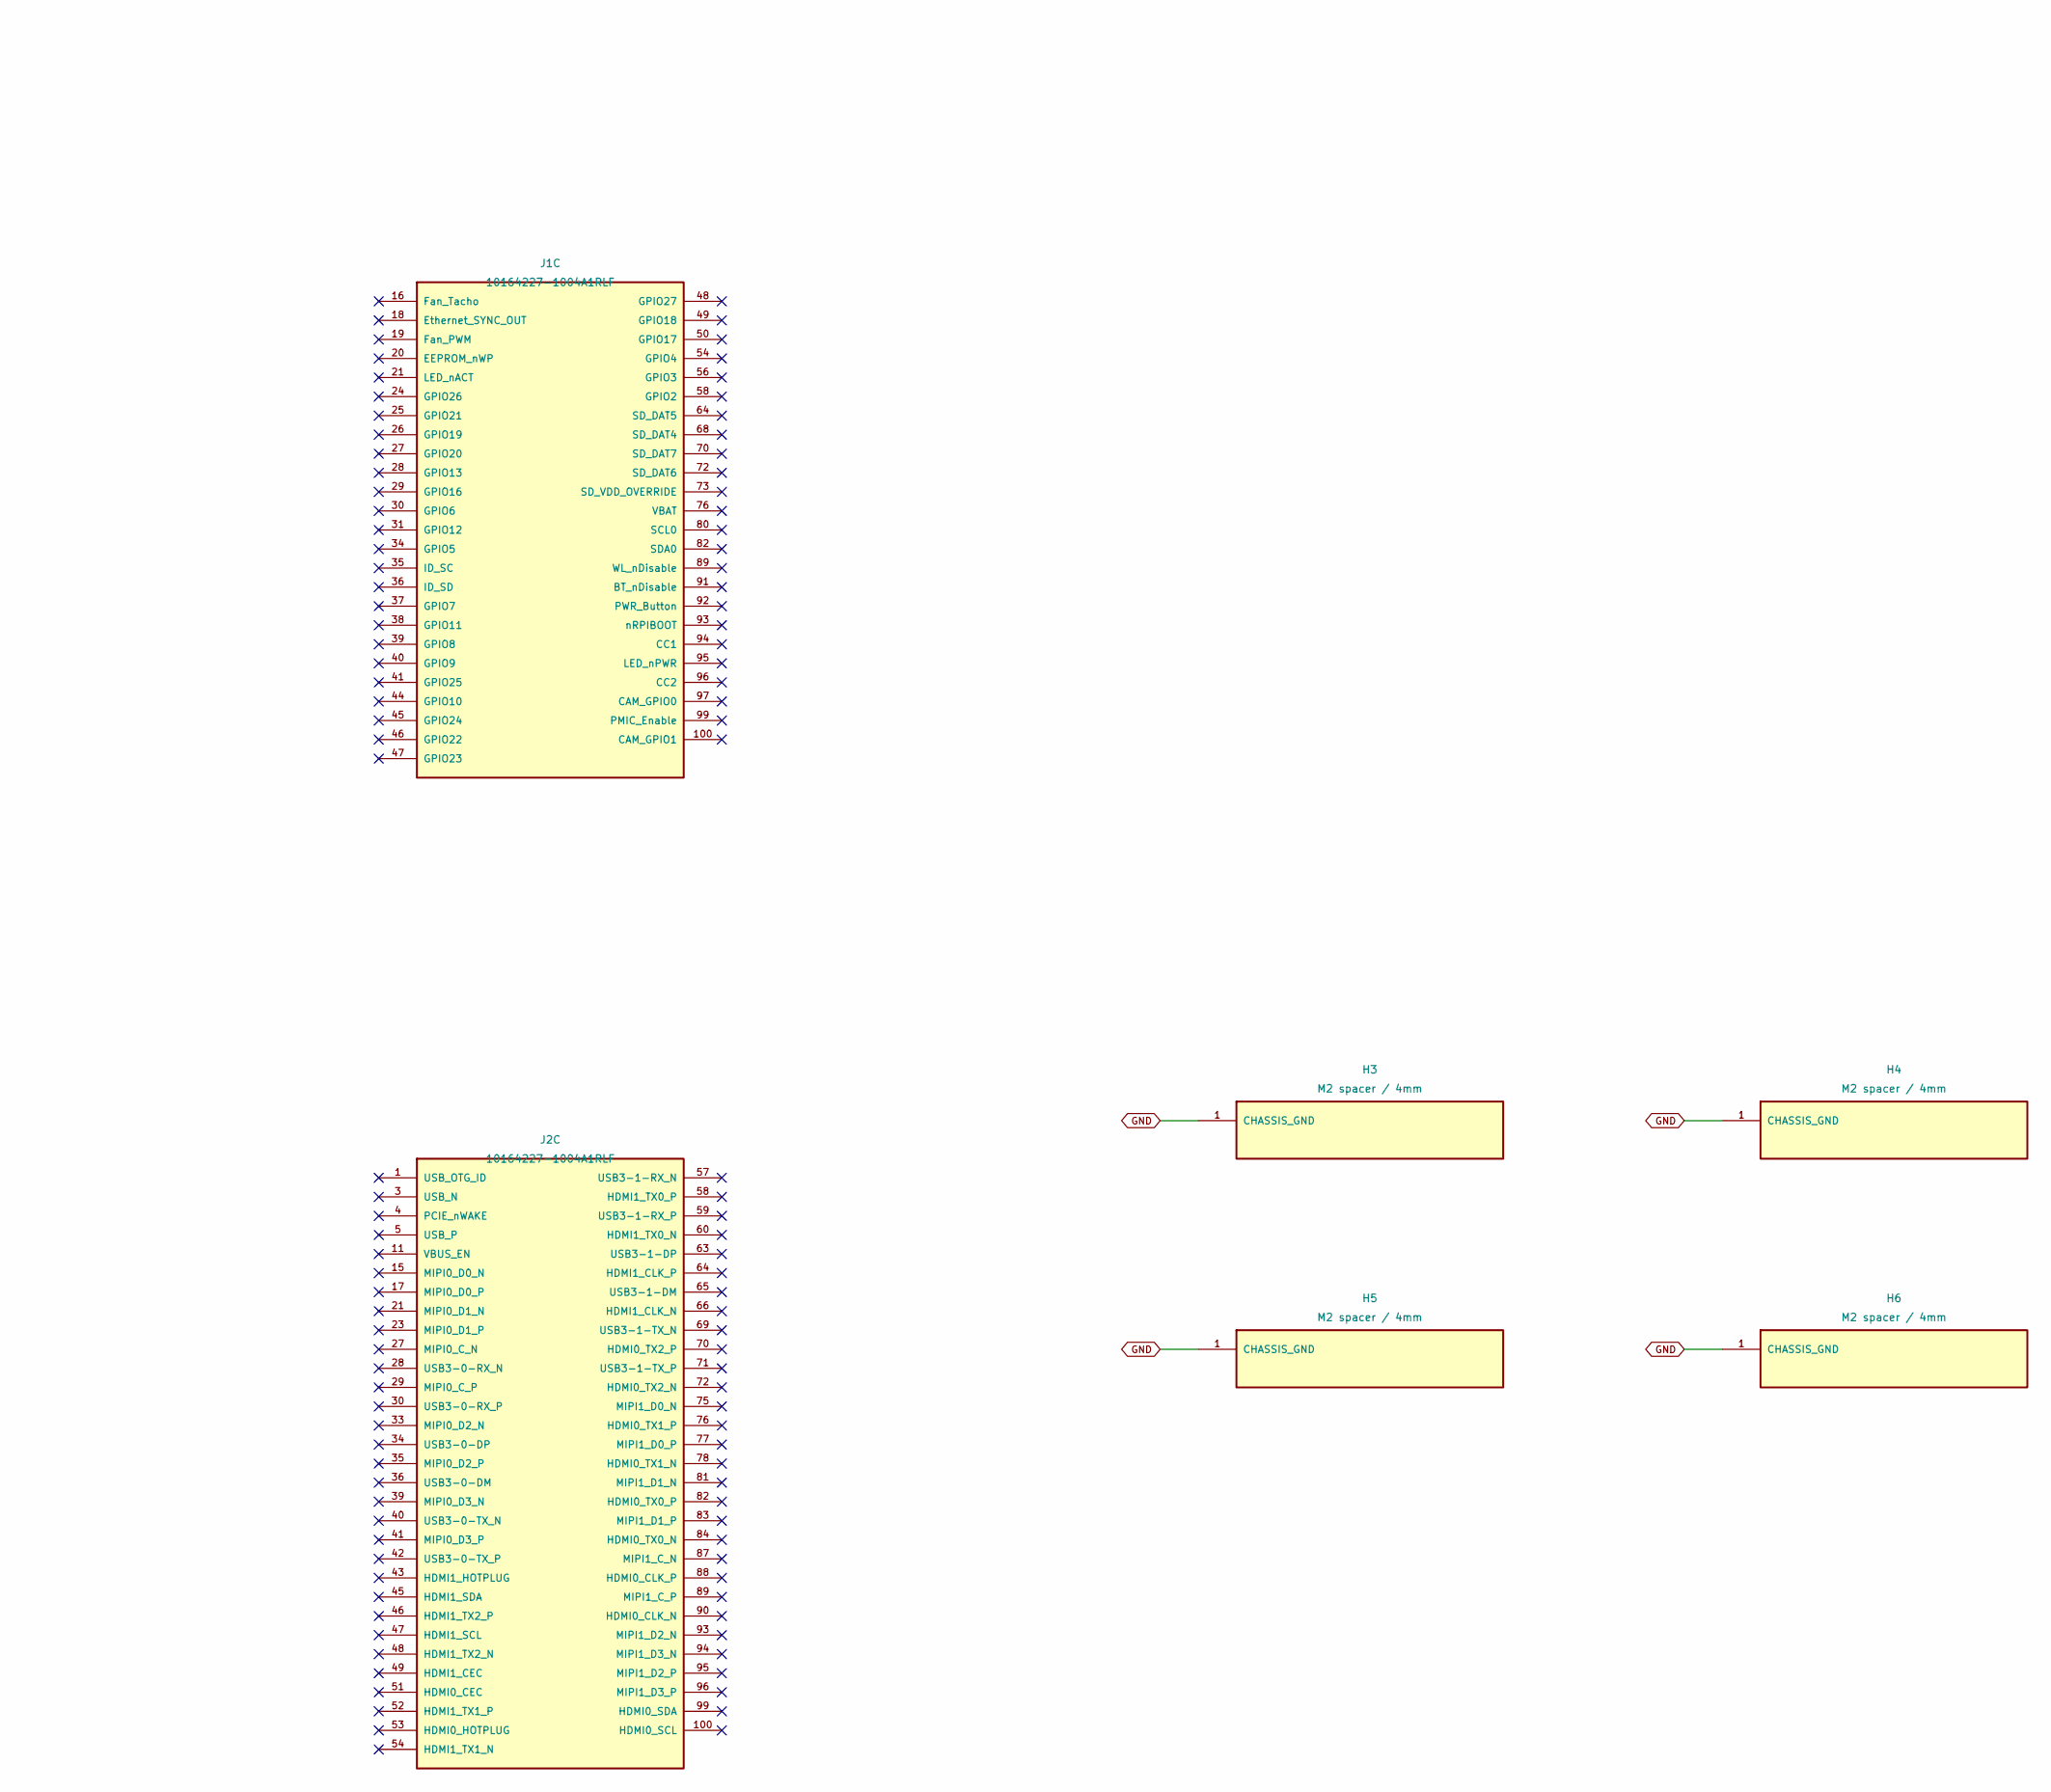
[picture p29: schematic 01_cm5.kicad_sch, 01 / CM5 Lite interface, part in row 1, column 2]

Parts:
H3, H4, H5, H6: M2 spacer / 4mm; YIYUAN_SMTSOM240BTR; MANUFACTURER PART NUMBER SMTSOM240BTR; LCSC Part Number C19626599
J1, J2: 10164227-1004A1RLF; CM5_Amphenol_10164227_1004_OfficialPads; MANUFACTURER PART NUMBER 10164227-1004A1RLF; LCSC Part Number C7435219

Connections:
CM_1V8: J1.88 (CM5_1.8V (Output)), J1.90 (CM5_1.8V (Output))
CM_3V3: J1.78 (GPIO_VREF), J1.84 (CM5_3.3V (Output)), J1.86 (CM5_3.3V (Output)); also elsewhere on the board
ETH0_N: J1.10 (Ethernet_Pair0_N); also elsewhere on the board
ETH0_P: J1.12 (Ethernet_Pair0_P); also elsewhere on the board
ETH1_N: J1.6 (Ethernet_Pair1_N); also elsewhere on the board
ETH1_P: J1.4 (Ethernet_Pair1_P); also elsewhere on the board
ETH2_N: J1.9 (Ethernet_Pair2_N); also elsewhere on the board
ETH2_P: J1.11 (Ethernet_Pair2_P); also elsewhere on the board
ETH3_N: J1.5 (Ethernet_Pair3_N); also elsewhere on the board
ETH3_P: J1.3 (Ethernet_Pair3_P); also elsewhere on the board
ETH_LED_ACT_N: J1.15 (Ethernet_nLED3); also elsewhere on the board
ETH_LED_LINK_N: J1.17 (Ethernet_nLED2); also elsewhere on the board
GND: H3.1, H4.1, H5.1, H6.1, J1.1 (GND), J1.2 (GND), J1.7 (GND), J1.8 (GND), J1.13 (GND), J1.14 (GND), J1.22 (GND), J1.23 (GND), J1.32 (GND), J1.33 (GND), J1.42 (GND), J1.43 (GND), J1.52 (GND), J1.53 (GND), J1.59 (GND), J1.60 (GND), J1.65 (GND), J1.66 (GND), J1.71 (GND), J1.74 (GND), J1.98 (GND), J2.2 (PCIe_CLK_nREQ), J2.7 (GND), J2.8 (GND), J2.13 (GND), J2.14 (GND), J2.19 (GND), J2.20 (GND), J2.25 (GND), J2.26 (GND), J2.31 (GND), J2.32 (GND), J2.37 (GND), J2.38 (GND), J2.44 (GND), J2.50 (GND), J2.55 (GND), J2.56 (GND), J2.61 (GND), J2.62 (GND), J2.67 (GND), J2.68 (GND), J2.73 (GND), J2.74 (GND), J2.79 (GND), J2.80 (GND), J2.85 (GND), J2.86 (GND), J2.91 (GND), J2.92 (GND), J2.97 (GND), J2.98 (GND); also elsewhere on the board
HOST_CLK_N: J2.12 (PCIe_CLK_N); also elsewhere on the board
HOST_CLK_P: J2.10 (PCIe_CLK_P); also elsewhere on the board
HOST_RX_N: J2.16 (PCIe_RX_P); also elsewhere on the board
HOST_RX_P: J2.18 (PCIe_RX_N); also elsewhere on the board
HOST_TX_N: J2.24 (PCIe_TX_N); also elsewhere on the board
HOST_TX_P: J2.22 (PCIe_TX_P); also elsewhere on the board
PCIE_PWR_EN: J2.6 (PCIE_PWR_EN); also elsewhere on the board
PCIE_RESET_N: J2.9 (PCIe_nRST); also elsewhere on the board
SD_CLK: J1.57 (SD_CLK); also elsewhere on the board
SD_CMD: J1.62 (SD_CMD); also elsewhere on the board
SD_DAT0: J1.63 (SD_DAT0); also elsewhere on the board
SD_DAT1: J1.67 (SD_DAT1); also elsewhere on the board
SD_DAT2: J1.69 (SD_DAT2); also elsewhere on the board
SD_DAT3: J1.61 (SD_DAT3); also elsewhere on the board
SD_PWR_EN: J1.75 (SD_PWR_ON); also elsewhere on the board
SYS_5V: J1.77 (5V_IN), J1.79 (5V_IN), J1.81 (5V_IN), J1.83 (5V_IN), J1.85 (5V_IN), J1.87 (5V_IN); also elsewhere on the board
UART_RX_CM: J1.51 (GPIO15); also elsewhere on the board
UART_TX_CM: J1.55 (GPIO14); also elsewhere on the board

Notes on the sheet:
01 / CM5 Lite interface
4 mm official Amphenol connectors. CM5 Lite required for native microSD. No eMMC module. Connector J2 local pin 1 corresponds to module pin 101. UART uses GPIO14/15 with OS configuration. CM5 PCIe receive P/N intentionally reversed for routing; automatic receiver polarity correction is supported.

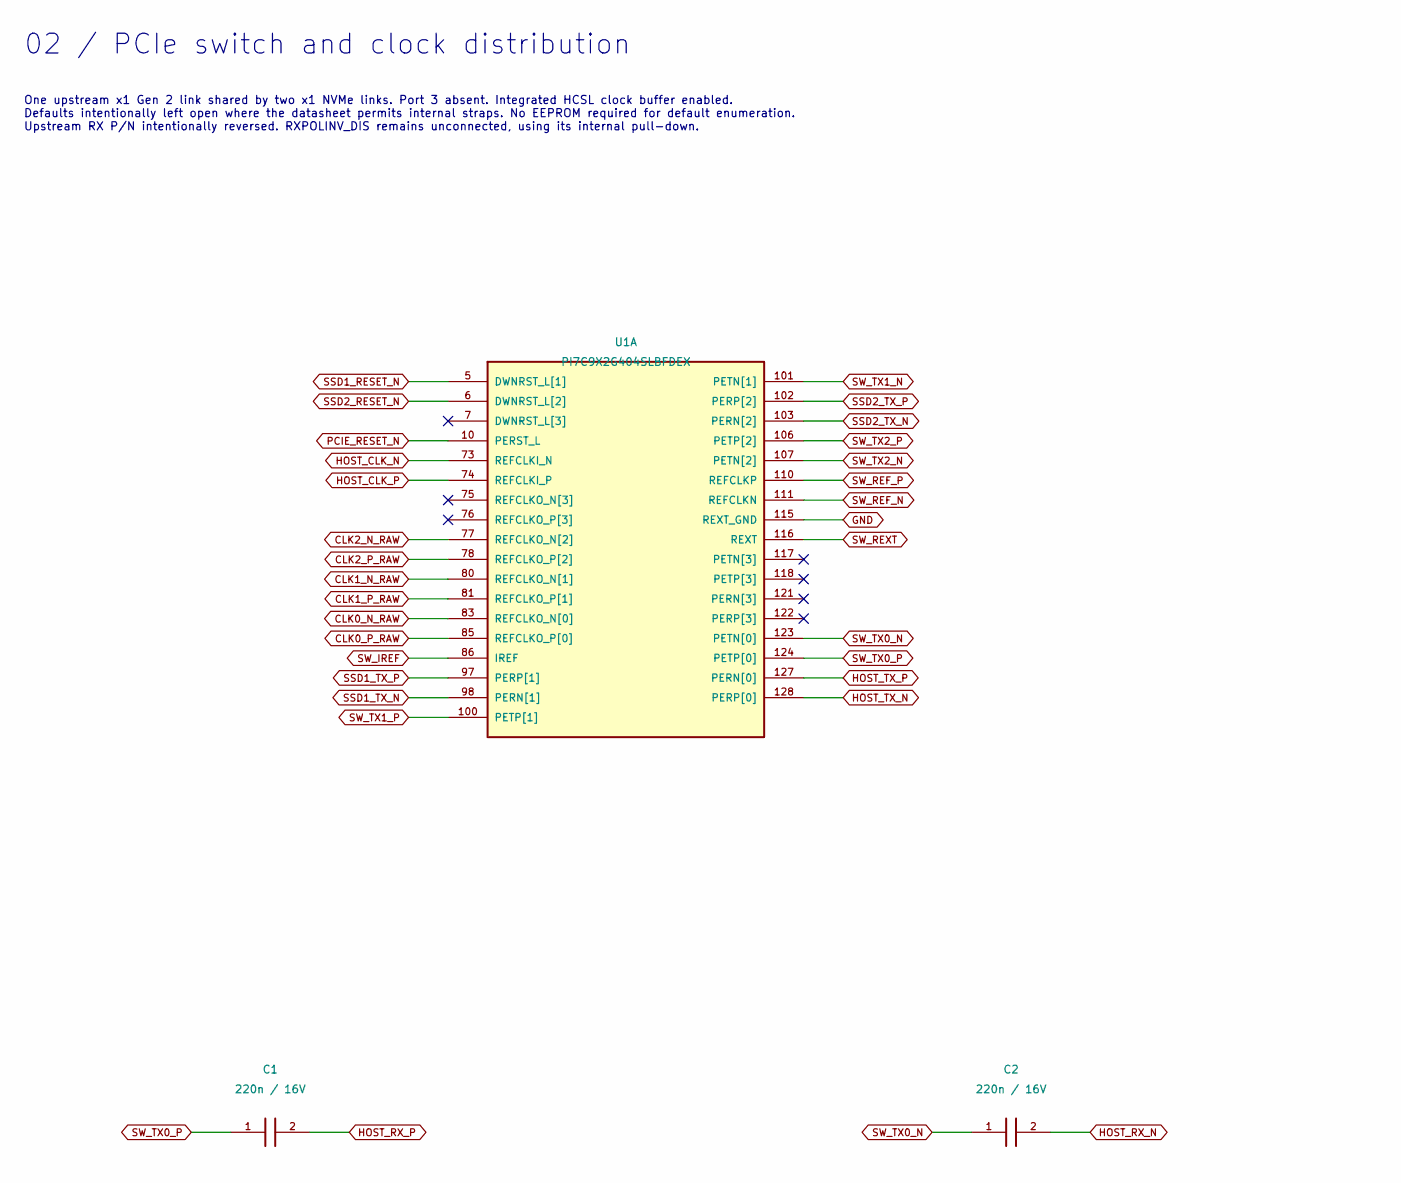
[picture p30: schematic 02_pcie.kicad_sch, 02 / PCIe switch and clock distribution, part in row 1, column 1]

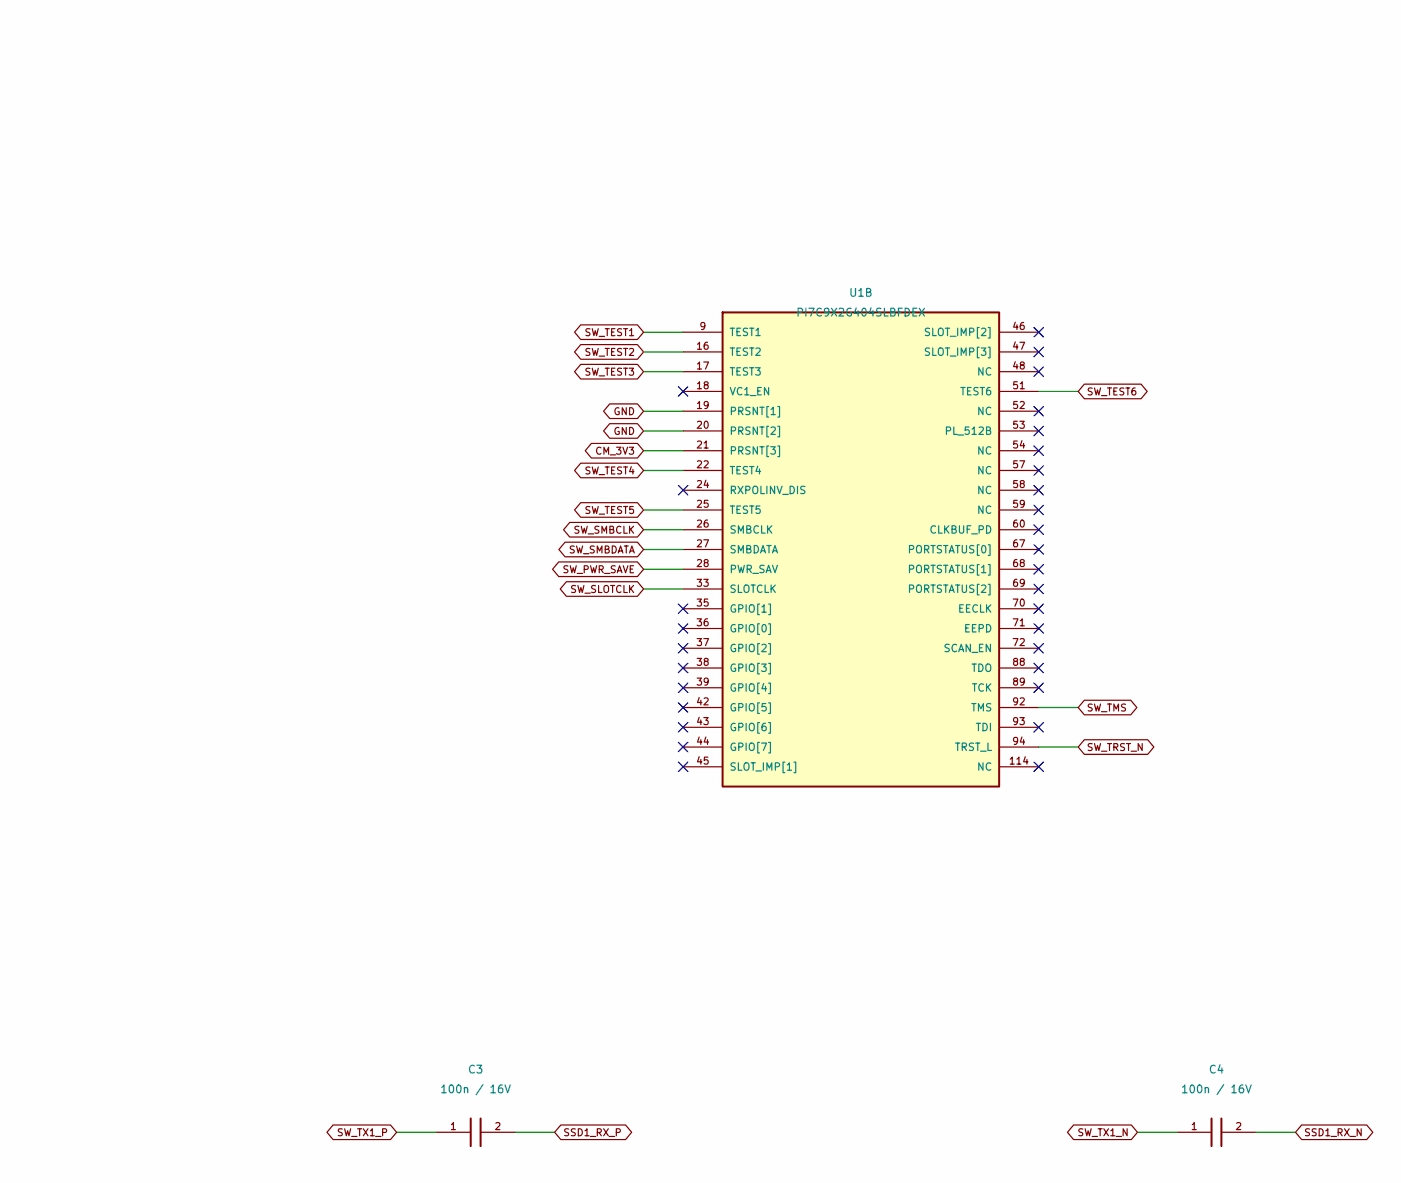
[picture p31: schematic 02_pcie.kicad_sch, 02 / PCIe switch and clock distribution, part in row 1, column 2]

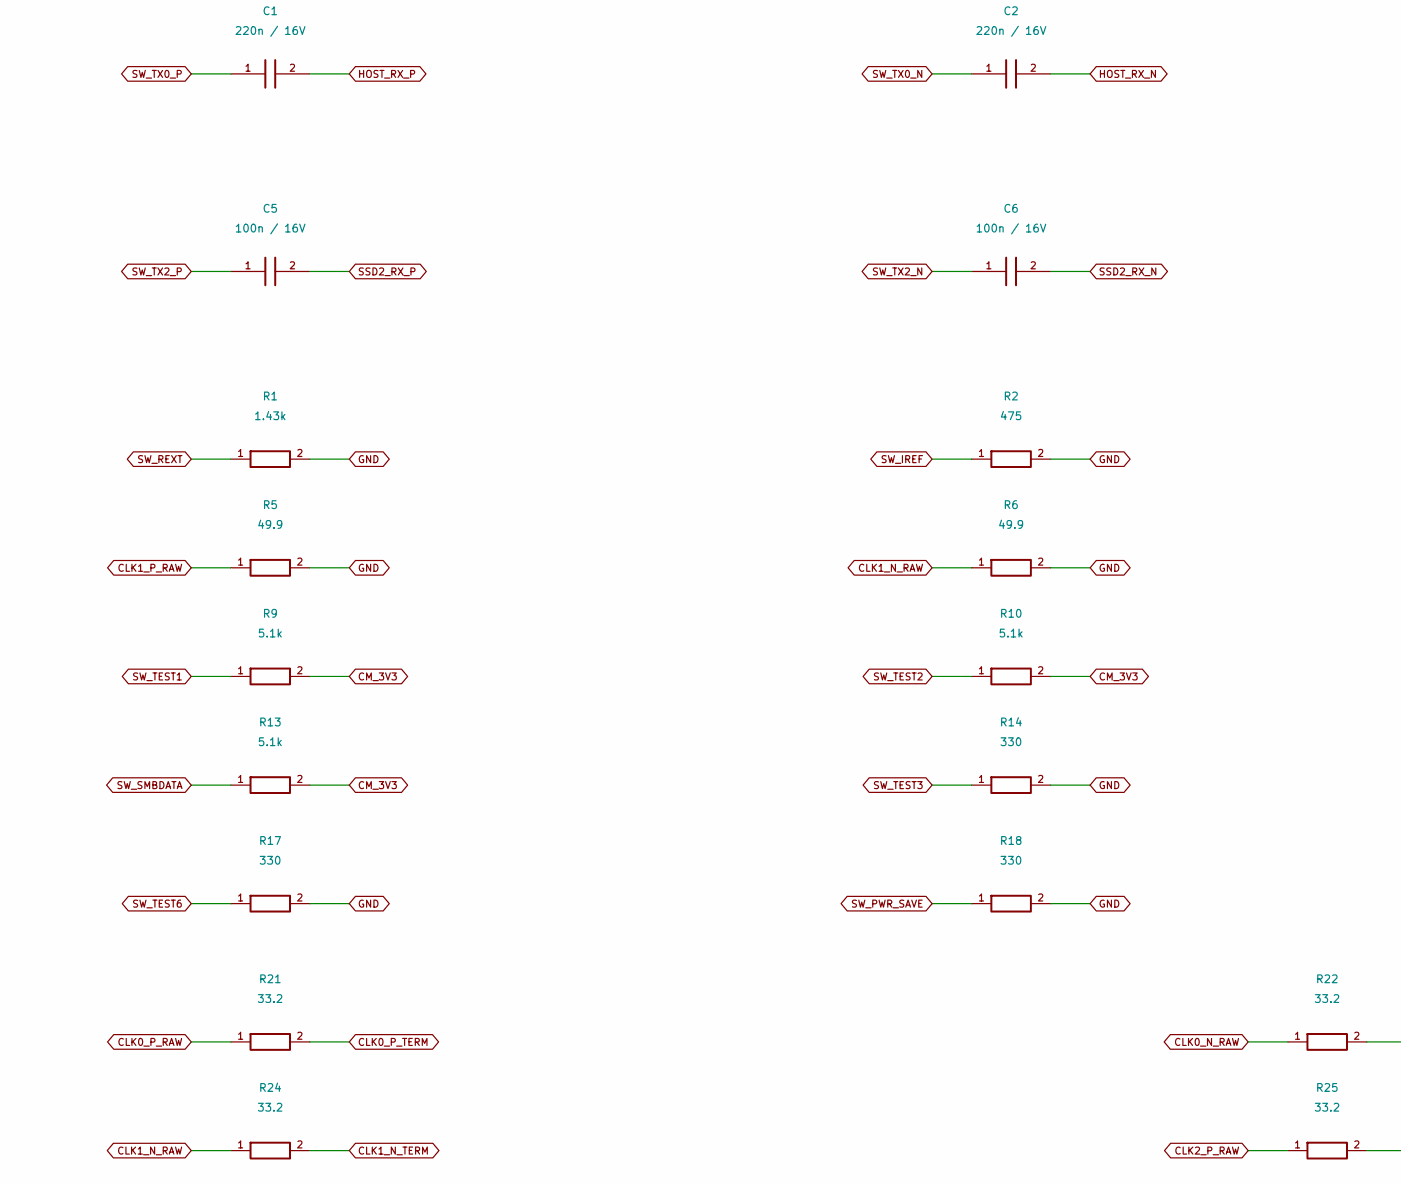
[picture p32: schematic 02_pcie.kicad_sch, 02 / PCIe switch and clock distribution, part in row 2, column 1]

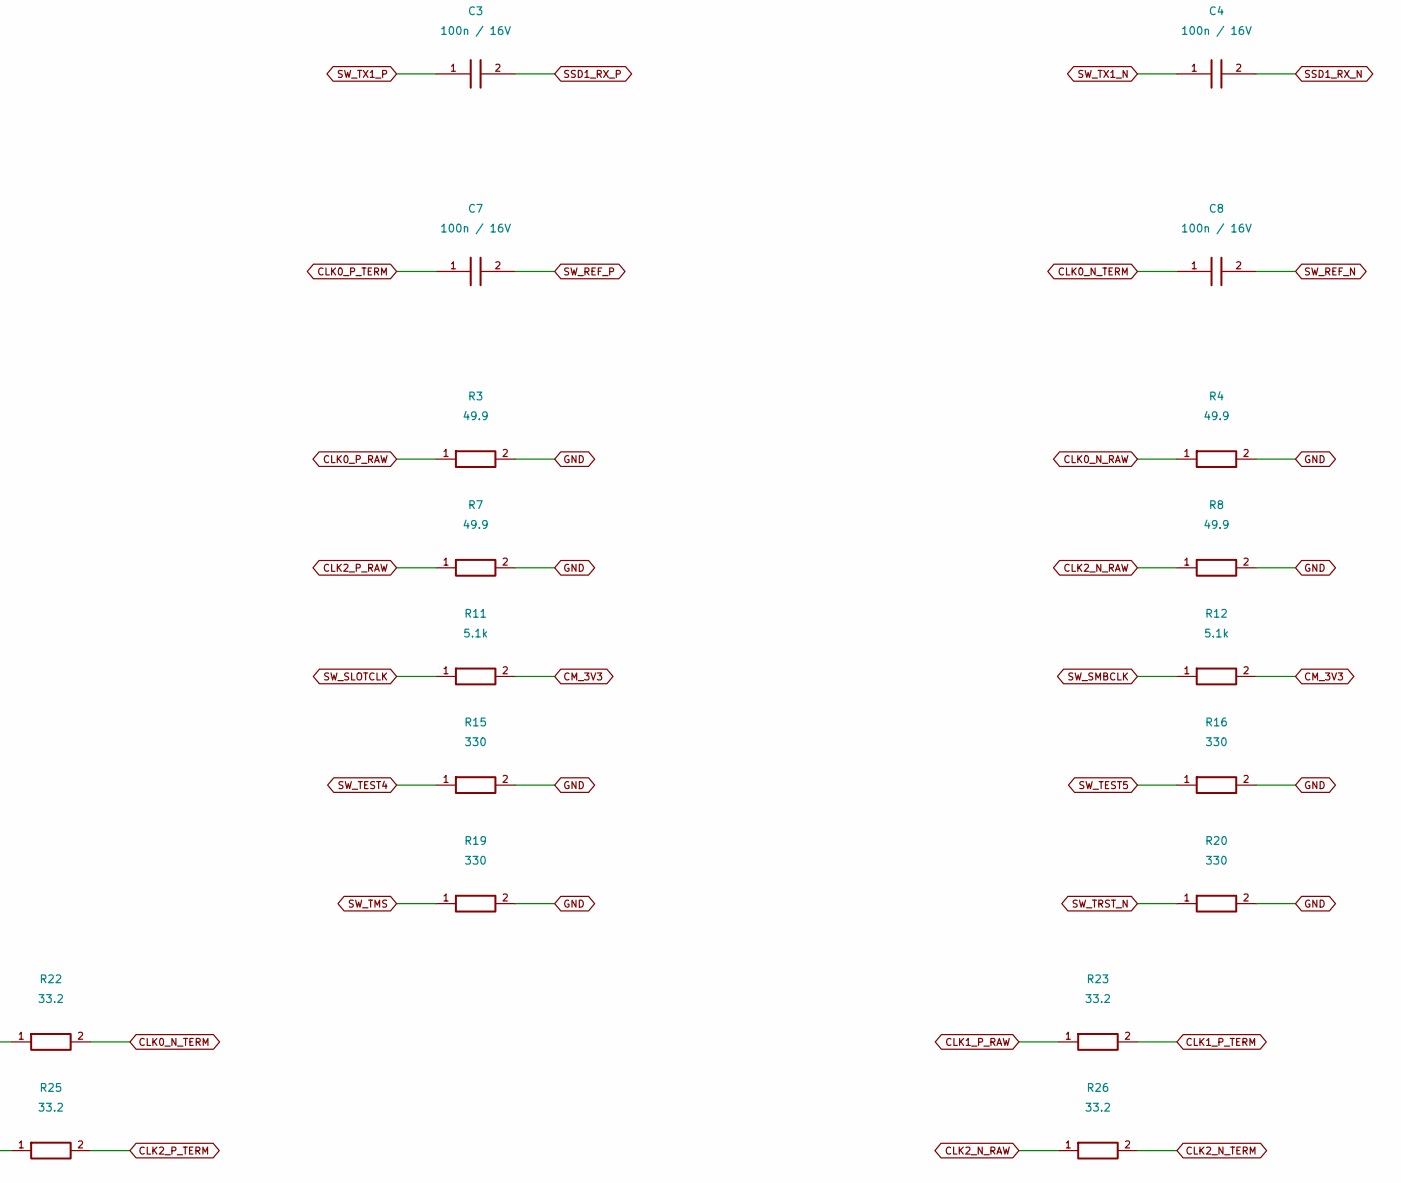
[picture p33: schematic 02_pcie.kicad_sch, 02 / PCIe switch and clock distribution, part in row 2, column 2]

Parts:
C1, C2: 220n / 16V; C_0402_1005Metric; MANUFACTURER PART NUMBER CL05B224KO5NNNC; LCSC Part Number C16772
C3, C4, C5, C6, C7, C8: 100n / 16V; C_0402_1005Metric; MANUFACTURER PART NUMBER CL05B104KO5NNNC; LCSC Part Number C1525
R1: 1.43k; R_0603_1608Metric; MANUFACTURER PART NUMBER 0603WAF1431T5E; LCSC Part Number C22840
R2: 475; R_0603_1608Metric; MANUFACTURER PART NUMBER 0603WAF4750T5E; LCSC Part Number C23181
R3, R4, R5, R6, R7, R8: 49.9; R_0402_1005Metric; MANUFACTURER PART NUMBER 0402WGF499JTCE; LCSC Part Number C25120
R9, R10, R11, R12, R13: 5.1k; R_0603_1608Metric; MANUFACTURER PART NUMBER 0603WAF5101T5E; LCSC Part Number C23186
R14, R15, R16, R17, R18, R19, R20: 330; R_0603_1608Metric; MANUFACTURER PART NUMBER 0603WAF3300T5E; LCSC Part Number C23138
R21, R22, R23, R24, R25, R26: 33.2; R_0402_1005Metric; MANUFACTURER PART NUMBER 0402WGF332JTCE; LCSC Part Number C25106
U1: PI7C9X2G404SLBFDEX; LQFP-128_L14.0-W14.0-P0.40-LS16.0-BL-EP5.8; MANUFACTURER PART NUMBER PI7C9X2G404SLBFDEX; LCSC Part Number C500767

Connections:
CLK0_N_RAW: R4.1, R22.1, U1.83 (REFCLKO_N[0])
CLK0_N_TERM: C8.1, R22.2
CLK0_P_RAW: R3.1, R21.1, U1.85 (REFCLKO_P[0])
CLK0_P_TERM: C7.1, R21.2
CLK1_N_RAW: R6.1, R24.1, U1.80 (REFCLKO_N[1])
CLK1_N_TERM: R24.2; also elsewhere on the board
CLK1_P_RAW: R5.1, R23.1, U1.81 (REFCLKO_P[1])
CLK1_P_TERM: R23.2; also elsewhere on the board
CLK2_N_RAW: R8.1, R26.1, U1.77 (REFCLKO_N[2])
CLK2_N_TERM: R26.2; also elsewhere on the board
CLK2_P_RAW: R7.1, R25.1, U1.78 (REFCLKO_P[2])
CLK2_P_TERM: R25.2; also elsewhere on the board
CM_3V3: R9.2, R10.2, R11.2, R12.2, R13.2, U1.21 (PRSNT[3]); also elsewhere on the board
GND: R1.2, R2.2, R3.2, R4.2, R5.2, R6.2, R7.2, R8.2, R14.2, R15.2, R16.2, R17.2, R18.2, R19.2, R20.2, U1.19 (PRSNT[1]), U1.20 (PRSNT[2]), U1.115 (REXT_GND); also elsewhere on the board
HOST_CLK_N: U1.73 (REFCLKI_N); also elsewhere on the board
HOST_CLK_P: U1.74 (REFCLKI_P); also elsewhere on the board
HOST_RX_N: C2.2; also elsewhere on the board
HOST_RX_P: C1.2; also elsewhere on the board
HOST_TX_N: U1.128 (PERP[0]); also elsewhere on the board
HOST_TX_P: U1.127 (PERN[0]); also elsewhere on the board
PCIE_RESET_N: U1.10 (PERST_L); also elsewhere on the board
SSD1_RESET_N: U1.5 (DWNRST_L[1]); also elsewhere on the board
SSD1_RX_N: C4.2; also elsewhere on the board
SSD1_RX_P: C3.2; also elsewhere on the board
SSD1_TX_N: U1.98 (PERN[1]); also elsewhere on the board
SSD1_TX_P: U1.97 (PERP[1]); also elsewhere on the board
SSD2_RESET_N: U1.6 (DWNRST_L[2]); also elsewhere on the board
SSD2_RX_N: C6.2; also elsewhere on the board
SSD2_RX_P: C5.2; also elsewhere on the board
SSD2_TX_N: U1.103 (PERN[2]); also elsewhere on the board
SSD2_TX_P: U1.102 (PERP[2]); also elsewhere on the board
SW_IREF: R2.1, U1.86 (IREF)
SW_PWR_SAVE: R18.1, U1.28 (PWR_SAV)
SW_REF_N: C8.2, U1.111 (REFCLKN)
SW_REF_P: C7.2, U1.110 (REFCLKP)
SW_REXT: R1.1, U1.116 (REXT)
SW_SLOTCLK: R11.1, U1.33 (SLOTCLK)
SW_SMBCLK: R12.1, U1.26 (SMBCLK)
SW_SMBDATA: R13.1, U1.27 (SMBDATA)
SW_TEST1: R9.1, U1.9 (TEST1)
SW_TEST2: R10.1, U1.16 (TEST2)
SW_TEST3: R14.1, U1.17 (TEST3)
SW_TEST4: R15.1, U1.22 (TEST4)
SW_TEST5: R16.1, U1.25 (TEST5)
SW_TEST6: R17.1, U1.51 (TEST6)
SW_TMS: R19.1, U1.92 (TMS)
SW_TRST_N: R20.1, U1.94 (TRST_L)
SW_TX0_N: C2.1, U1.123 (PETN[0])
SW_TX0_P: C1.1, U1.124 (PETP[0])
SW_TX1_N: C4.1, U1.101 (PETN[1])
SW_TX1_P: C3.1, U1.100 (PETP[1])
SW_TX2_N: C6.1, U1.107 (PETN[2])
SW_TX2_P: C5.1, U1.106 (PETP[2])

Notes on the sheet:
02 / PCIe switch and clock distribution
One upstream x1 Gen 2 link shared by two x1 NVMe links. Port 3 absent. Integrated HCSL clock buffer enabled. Defaults intentionally left open where the datasheet permits internal straps. No EEPROM required for default enumeration. Upstream RX P/N intentionally reversed. RXPOLINV_DIS remains unconne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

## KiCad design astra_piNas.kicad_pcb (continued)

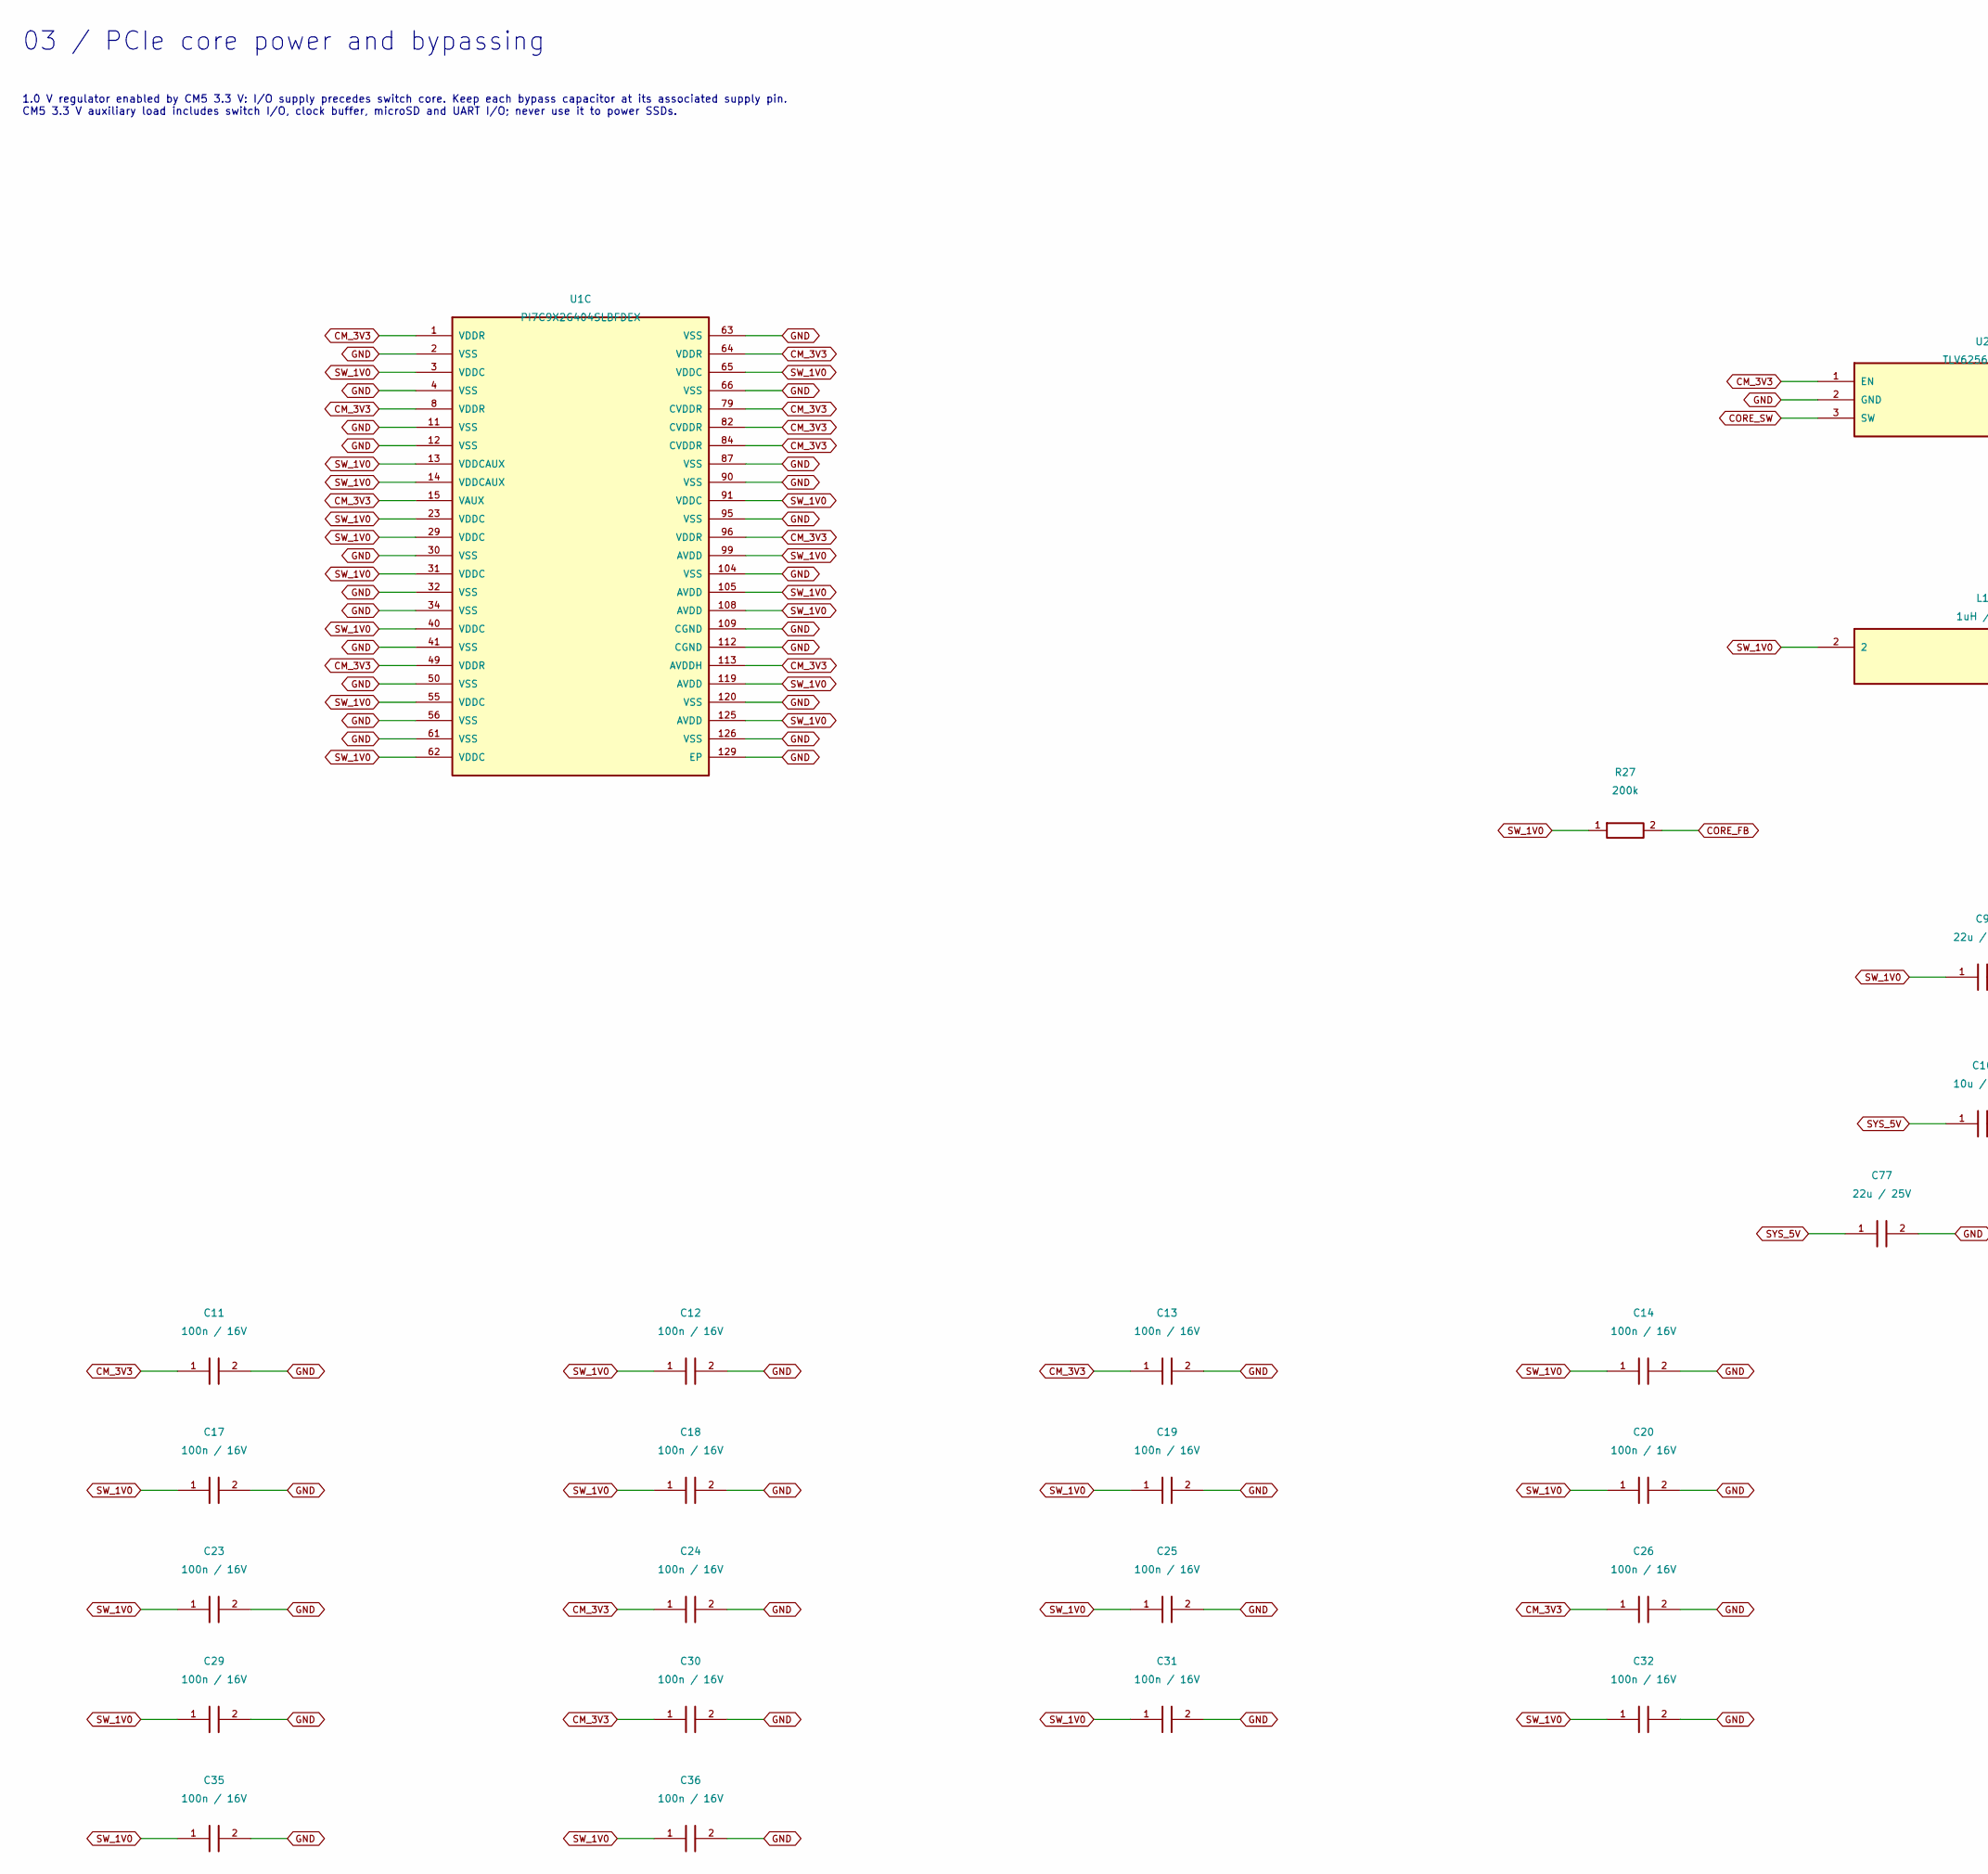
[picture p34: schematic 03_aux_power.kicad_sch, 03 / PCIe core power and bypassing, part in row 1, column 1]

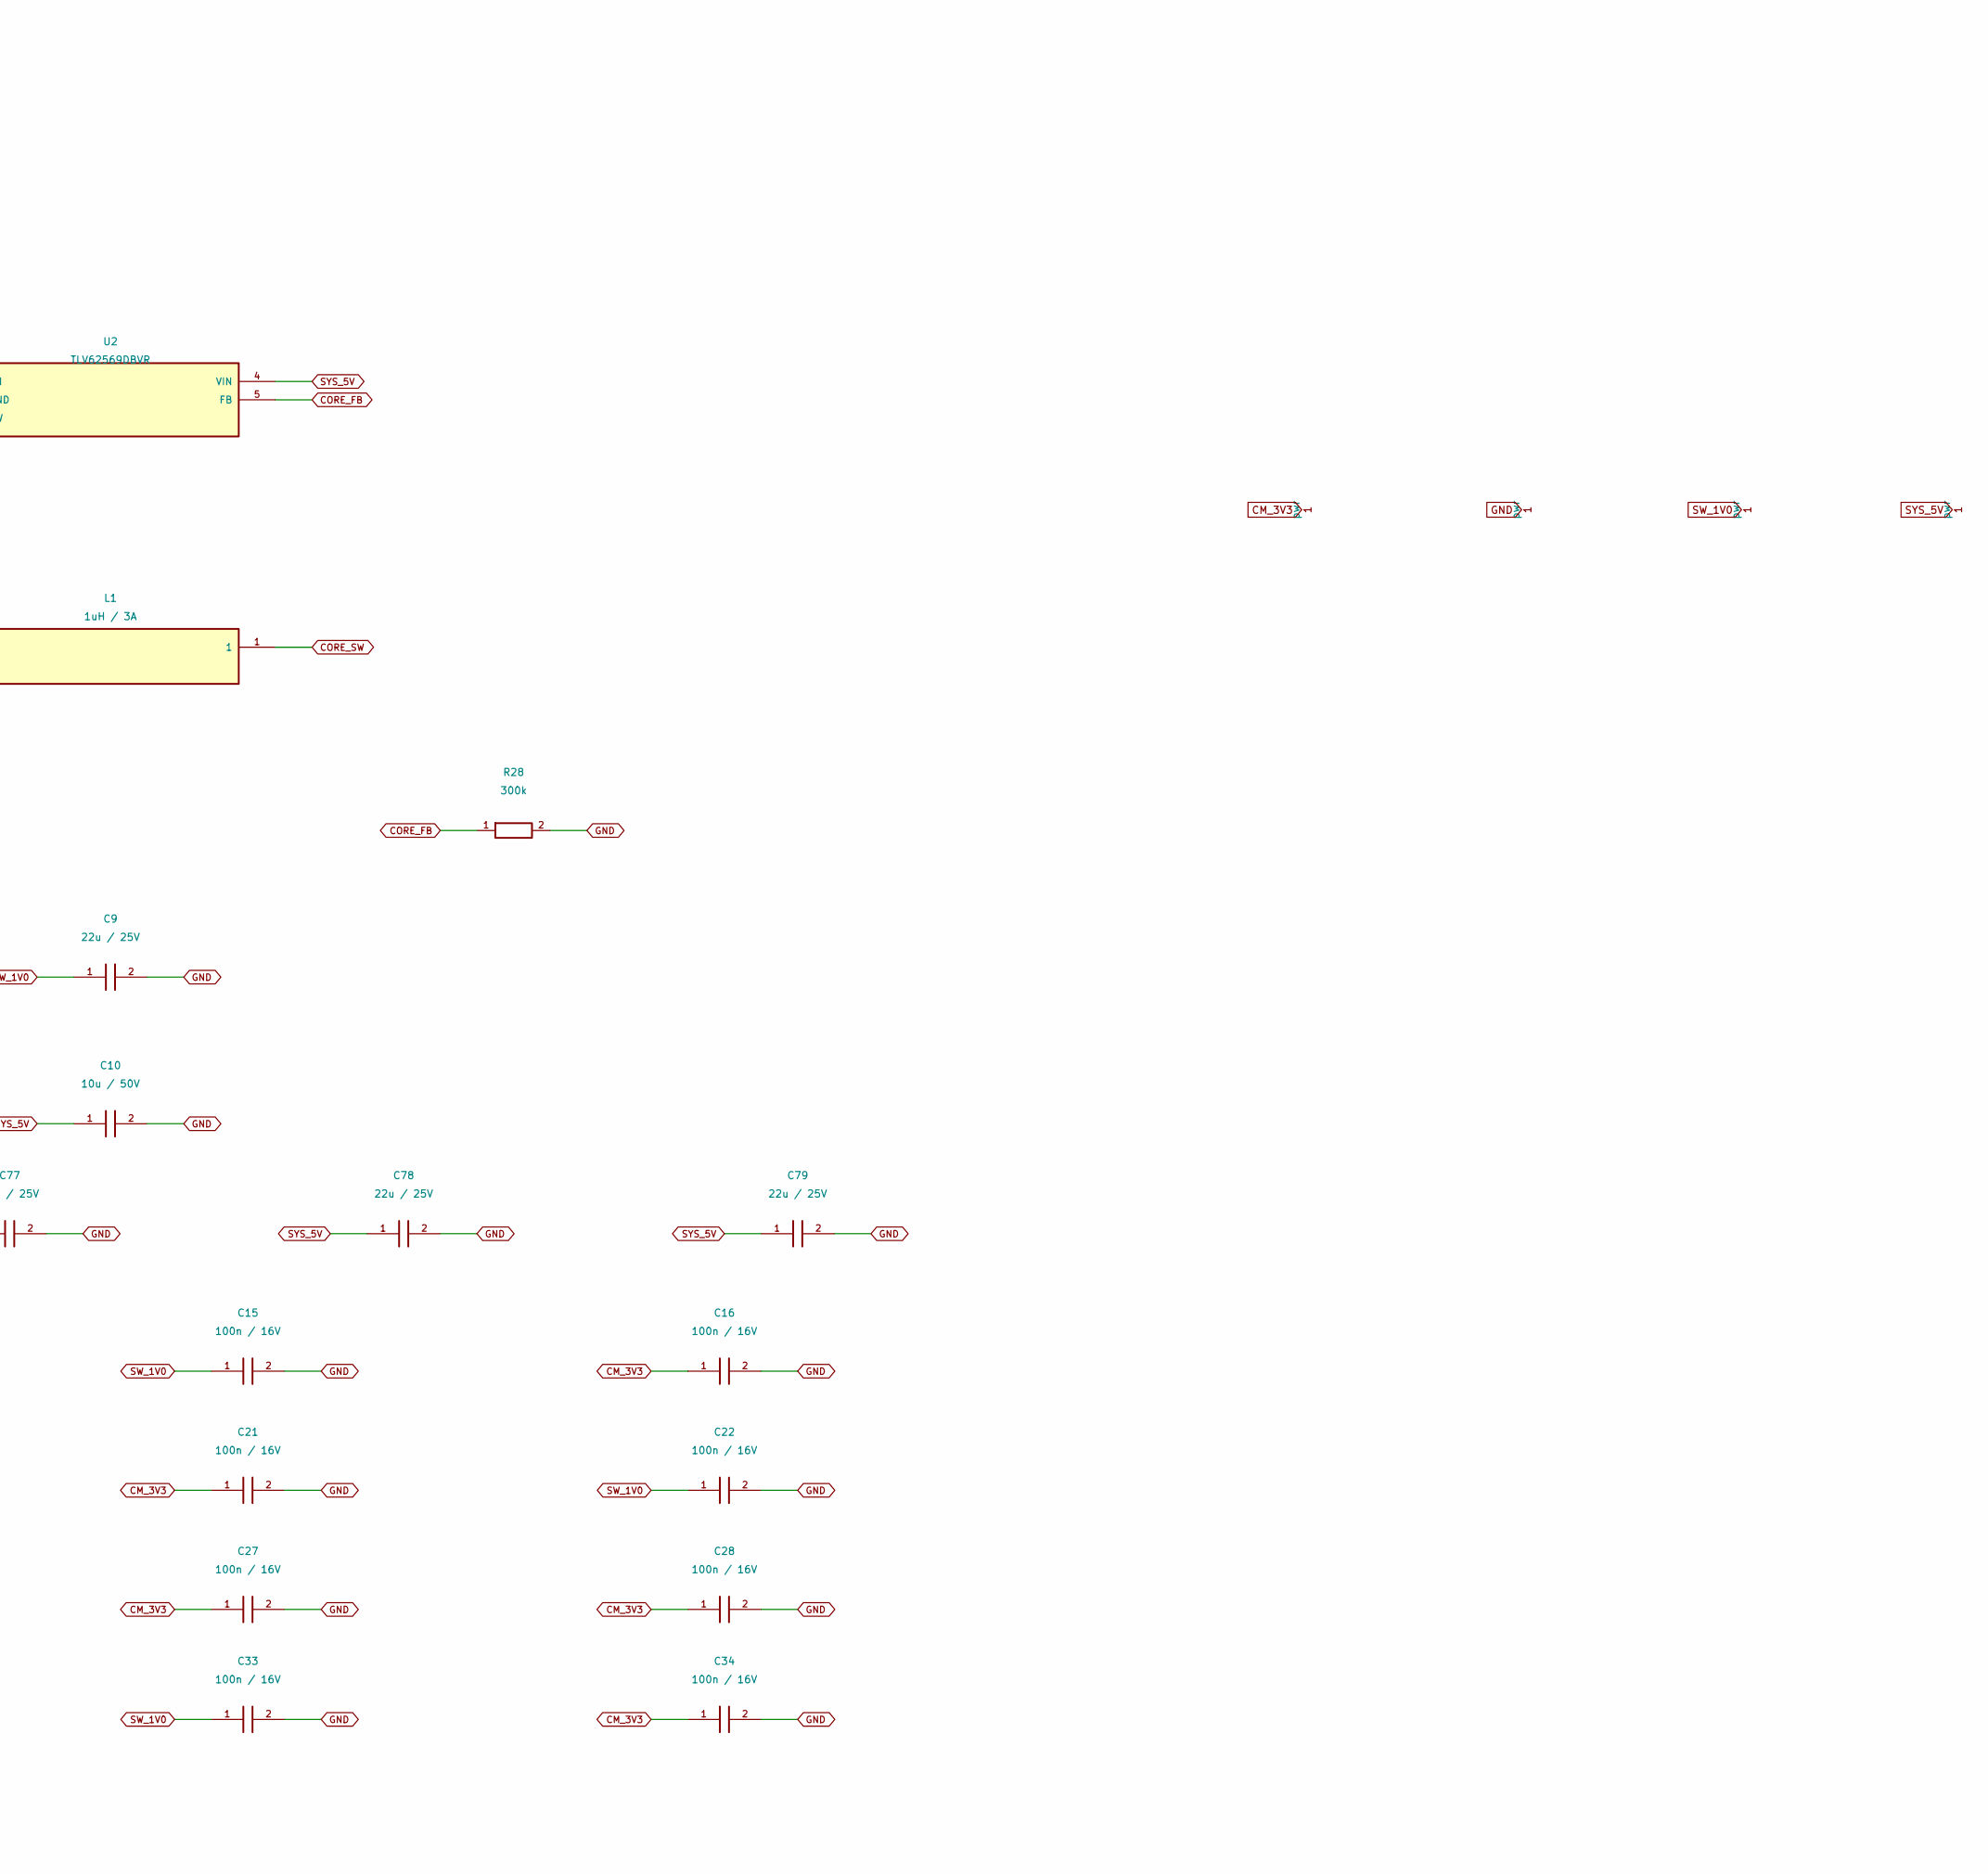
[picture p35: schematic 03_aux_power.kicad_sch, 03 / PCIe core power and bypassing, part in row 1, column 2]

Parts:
C9, C77, C78, C79: 22u / 25V; C_0805_2012Metric; MANUFACTURER PART NUMBER CL21A226MAQNNNE; LCSC Part Number C45783
C10: 10u / 50V; C_1206_3216Metric; MANUFACTURER PART NUMBER CL31B106KAHNNNE; LCSC Part Number C14860
C11, C12, C13, C14, C15, C16, C17, C18, C19, C20, C21, C22, C23, C24, C25, C26, C27, C28, C29, C30, C31, C32, C33, C34, C35, C36: 100n / 16V; C_0402_1005Metric; MANUFACTURER PART NUMBER CL05B104KO5NNNC; LCSC Part Number C1525
L1: 1uH / 3A; IND-SMD_L2.5-W2.0-1; MANUFACTURER PART NUMBER VLS252010HBX-1R0M-1; LCSC Part Number C88211
R27: 200k; R_0603_1608Metric; MANUFACTURER PART NUMBER 0603WAF2003T5E; LCSC Part Number C25811
R28: 300k; R_0603_1608Metric; MANUFACTURER PART NUMBER 0603WAF3003T5E; LCSC Part Number C23024
U1: PI7C9X2G404SLBFDEX; LQFP-128_L14.0-W14.0-P0.40-LS16.0-BL-EP5.8; MANUFACTURER PART NUMBER PI7C9X2G404SLBFDEX; LCSC Part Number C500767
U2: TLV62569DBVR; SOT-23-5_L3.0-W1.7-P0.95-LS2.8-BR; MANUFACTURER PART NUMBER TLV62569DBVR; LCSC Part Number C141836

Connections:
CM_3V3: C11.1, C13.1, C16.1, C21.1, C24.1, C26.1, C27.1, C28.1, C30.1, C34.1, U1.1 (VDDR), U1.8 (VDDR), U1.15 (VAUX), U1.49 (VDDR), U1.64 (VDDR), U1.79 (CVDDR), U1.82 (CVDDR), U1.84 (CVDDR), U1.96 (VDDR), U1.113 (AVDDH), U2.1 (EN); also elsewhere on the board
CORE_FB: R27.2, R28.1, U2.5 (FB)
CORE_SW: L1.1, U2.3 (SW)
GND: C9.2, C10.2, C11.2, C12.2, C13.2, C14.2, C15.2, C16.2, C17.2, C18.2, C19.2, C20.2, C21.2, C22.2, C23.2, C24.2, C25.2, C26.2, C27.2, C28.2, C29.2, C30.2, C31.2, C32.2, C33.2, C34.2, C35.2, C36.2, C77.2, C78.2, C79.2, R28.2, U1.2 (VSS), U1.4 (VSS), U1.11 (VSS), U1.12 (VSS), U1.30 (VSS), U1.32 (VSS), U1.34 (VSS), U1.41 (VSS), U1.50 (VSS), U1.56 (VSS), U1.61 (VSS), U1.63 (VSS), U1.66 (VSS), U1.87 (VSS), U1.90 (VSS), U1.95 (VSS), U1.104 (VSS), U1.109 (CGND), U1.112 (CGND), U1.120 (VSS), U1.126 (VSS), U1.129 (EP), U2.2 (GND); also elsewhere on the board
SW_1V0: C9.1, C12.1, C14.1, C15.1, C17.1, C18.1, C19.1, C20.1, C22.1, C23.1, C25.1, C29.1, C31.1, C32.1, C33.1, C35.1, C36.1, L1.2, R27.1, U1.3 (VDDC), U1.13 (VDDCAUX), U1.14 (VDDCAUX), U1.23 (VDDC), U1.29 (VDDC), U1.31 (VDDC), U1.40 (VDDC), U1.55 (VDDC), U1.62 (VDDC), U1.65 (VDDC), U1.91 (VDDC), U1.99 (AVDD), U1.105 (AVDD), U1.108 (AVDD), U1.119 (AVDD), U1.125 (AVDD)
SYS_5V: C10.1, C77.1, C78.1, C79.1, U2.4 (VIN); also elsewhere on the board

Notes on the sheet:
03 / PCIe core power and bypassing
1.0 V regulator enabled by CM5 3.3 V: I/O supply precedes switch core. Keep each bypass capacitor at its associated supply pin. CM5 3.3 V auxiliary load includes switch I/O, clock buffer, microSD and UART I/O; never use it to power SSDs.

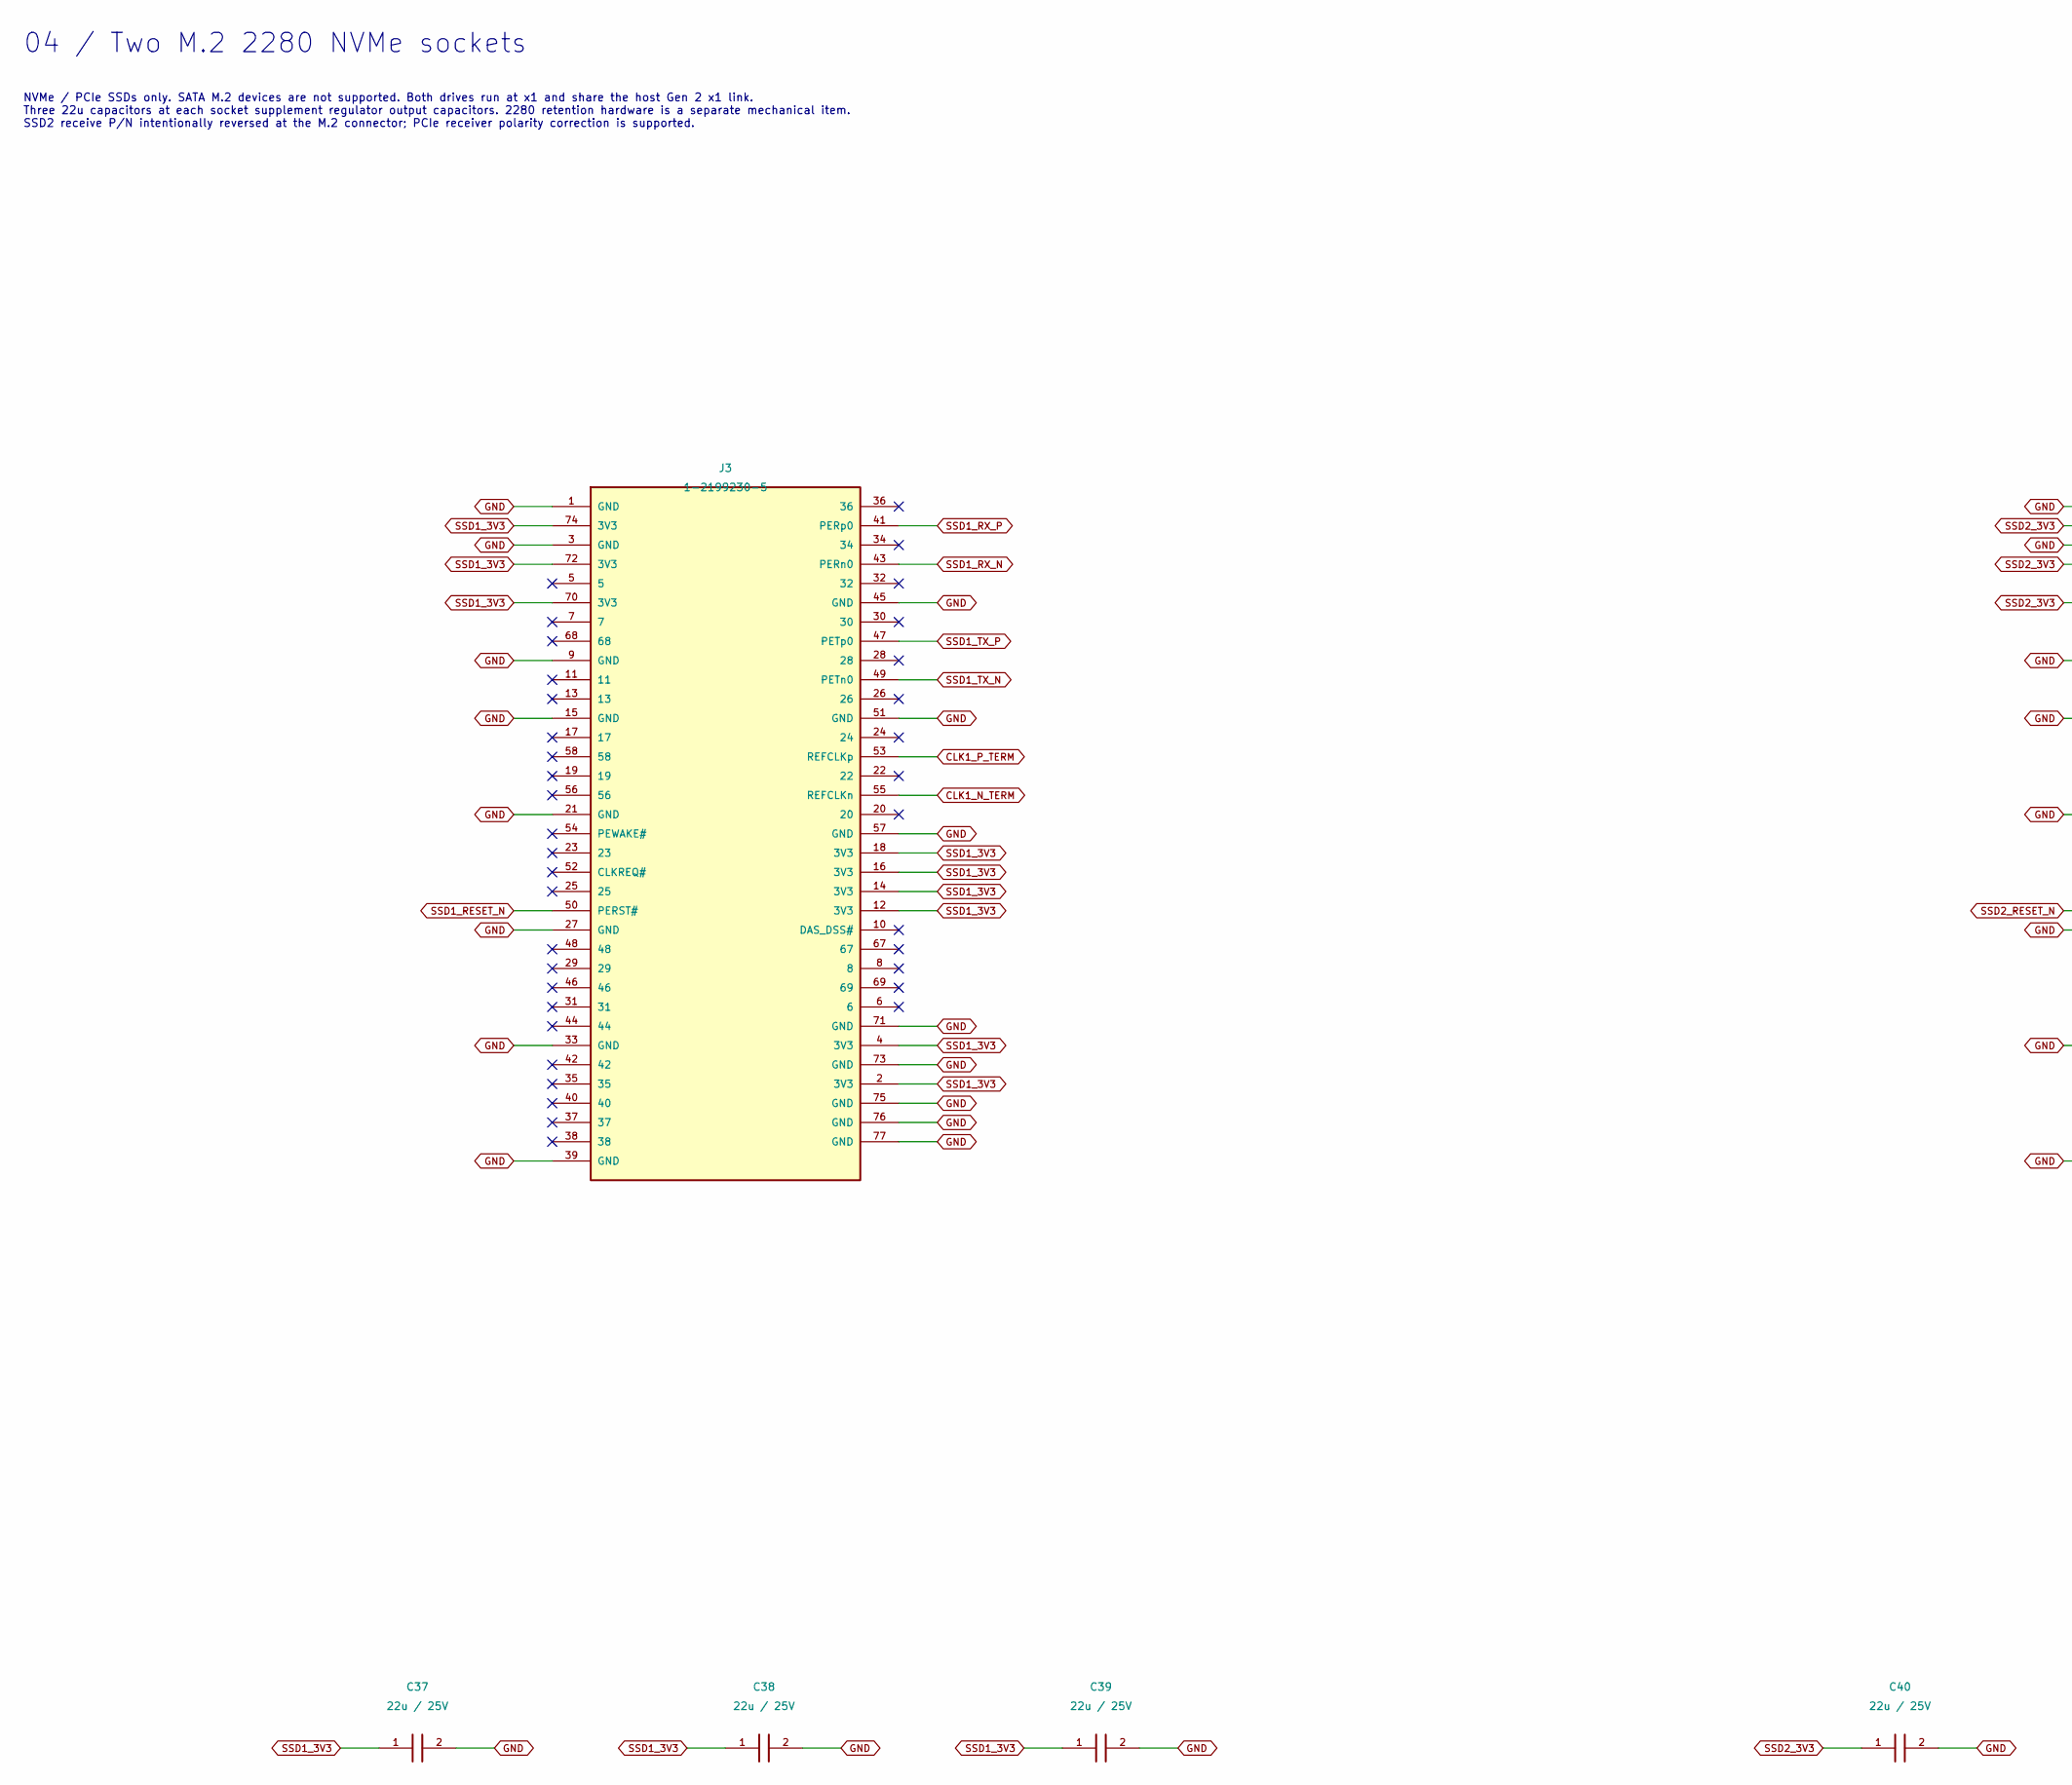
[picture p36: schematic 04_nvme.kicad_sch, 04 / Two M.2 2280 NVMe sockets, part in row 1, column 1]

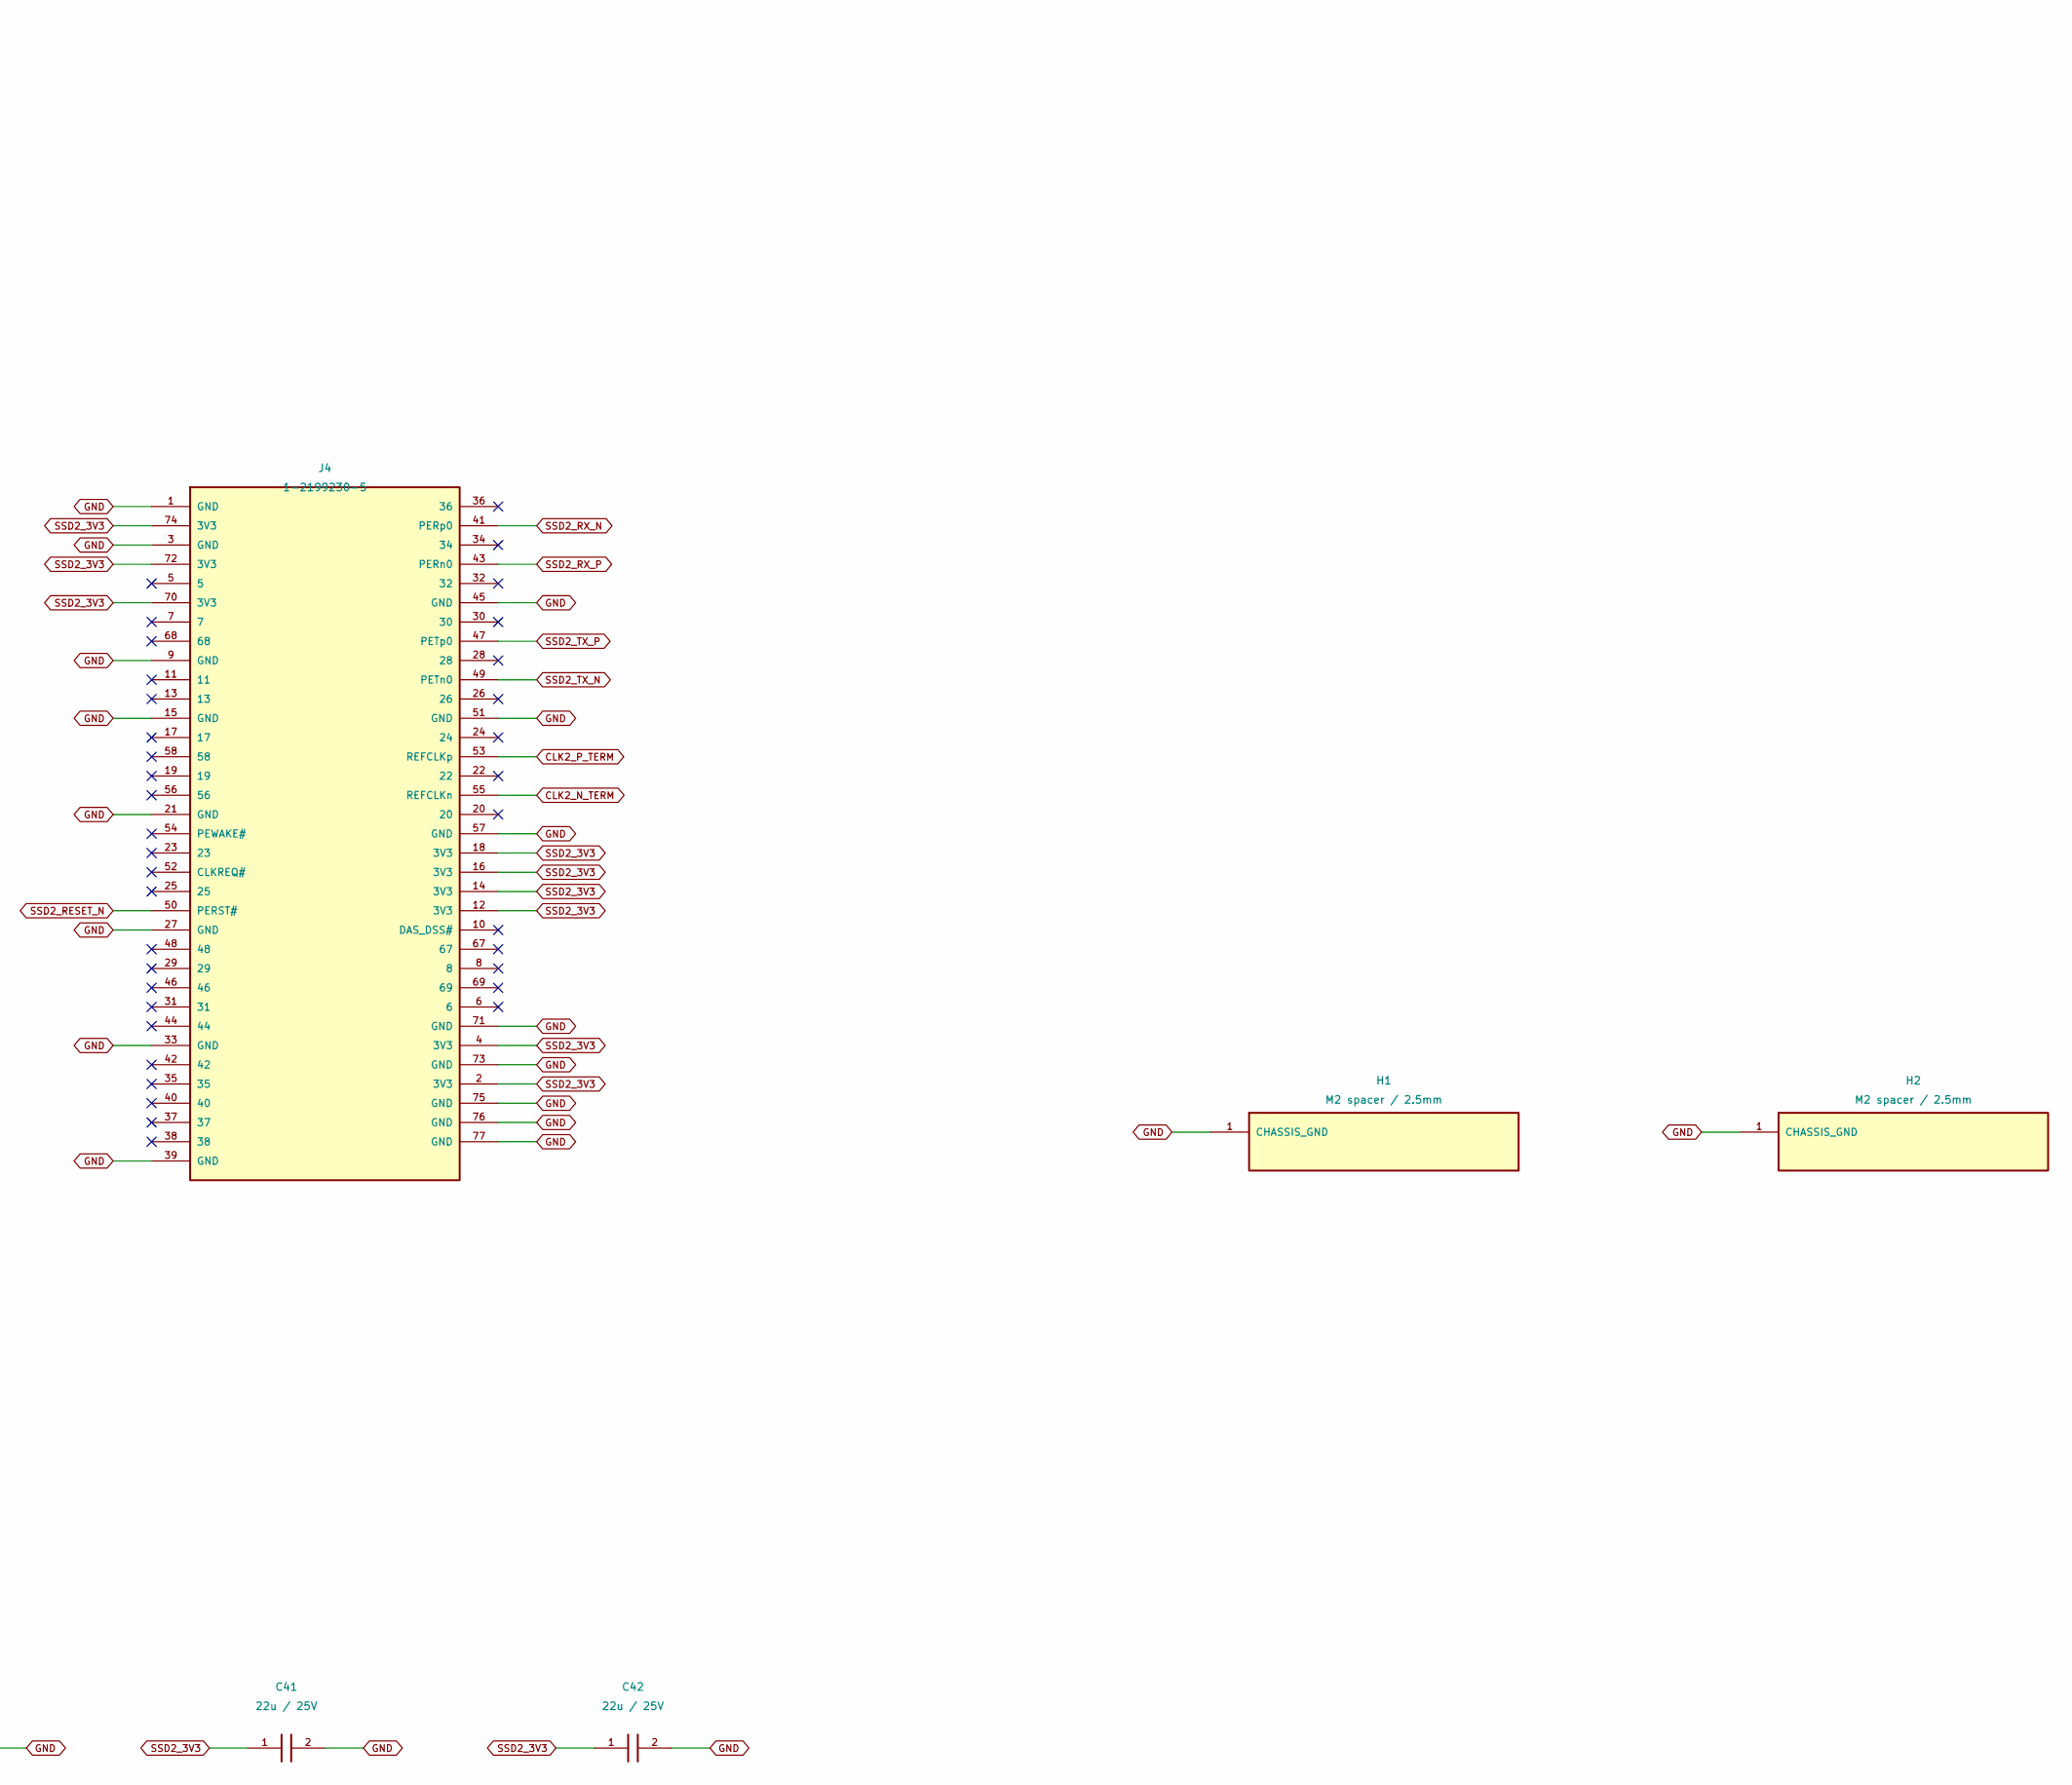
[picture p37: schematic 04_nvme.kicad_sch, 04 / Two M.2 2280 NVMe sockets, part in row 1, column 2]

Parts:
C37, C38, C39, C40, C41, C42: 22u / 25V; C_0805_2012Metric; MANUFACTURER PART NUMBER CL21A226MAQNNNE; LCSC Part Number C45783
H1, H2: M2 spacer / 2.5mm; YIYUAN_SMTSOM225BTR; MANUFACTURER PART NUMBER SMTSOM225BTR; LCSC Part Number C5301773
J3, J4: 1-2199230-5; PCIE-SMD_75P-P0.50_1-2199230-5; MANUFACTURER PART NUMBER 1-2199230-5; LCSC Part Number C590854

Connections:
CLK1_N_TERM: J3.55 (REFCLKn); also elsewhere on the board
CLK1_P_TERM: J3.53 (REFCLKp); also elsewhere on the board
CLK2_N_TERM: J4.55 (REFCLKn); also elsewhere on the board
CLK2_P_TERM: J4.53 (REFCLKp); also elsewhere on the board
GND: C37.2, C38.2, C39.2, C40.2, C41.2, C42.2, H1.1, H2.1, J3.1 (GND), J3.3 (GND), J3.9 (GND), J3.15 (GND), J3.21 (GND), J3.27 (GND), J3.33 (GND), J3.39 (GND), J3.45 (GND), J3.51 (GND), J3.57 (GND), J3.71 (GND), J3.73 (GND), J3.75 (GND), J3.76 (GND), J3.77 (GND), J4.1 (GND), J4.3 (GND), J4.9 (GND), J4.15 (GND), J4.21 (GND), J4.27 (GND), J4.33 (GND), J4.39 (GND), J4.45 (GND), J4.51 (GND), J4.57 (GND), J4.71 (GND), J4.73 (GND), J4.75 (GND), J4.76 (GND), J4.77 (GND); also elsewhere on the board
SSD1_3V3: C37.1, C38.1, C39.1, J3.2 (3V3), J3.4 (3V3), J3.12 (3V3), J3.14 (3V3), J3.16 (3V3), J3.18 (3V3), J3.70 (3V3), J3.72 (3V3), J3.74 (3V3); also elsewhere on the board
SSD1_RESET_N: J3.50 (PERST#); also elsewhere on the board
SSD1_RX_N: J3.43 (PERn0); also elsewhere on the board
SSD1_RX_P: J3.41 (PERp0); also elsewhere on the board
SSD1_TX_N: J3.49 (PETn0); also elsewhere on the board
SSD1_TX_P: J3.47 (PETp0); also elsewhere on the board
SSD2_3V3: C40.1, C41.1, C42.1, J4.2 (3V3), J4.4 (3V3), J4.12 (3V3), J4.14 (3V3), J4.16 (3V3), J4.18 (3V3), J4.70 (3V3), J4.72 (3V3), J4.74 (3V3); also elsewhere on the board
SSD2_RESET_N: J4.50 (PERST#); also elsewhere on the board
SSD2_RX_N: J4.41 (PERp0); also elsewhere on the board
SSD2_RX_P: J4.43 (PERn0); also elsewhere on the board
SSD2_TX_N: J4.49 (PETn0); also elsewhere on the board
SSD2_TX_P: J4.47 (PETp0); also elsewhere on the board

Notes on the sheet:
04 / Two M.2 2280 NVMe sockets
NVMe / PCIe SSDs only. SATA M.2 devices are not supported. Both drives run at x1 and share the host Gen 2 x1 link. Three 22u capacitors at each socket supplement regulator output capacitors. 2280 retention hardware is a separate mechanical item. SSD2 receive P/N intentionally reversed at the M.2 co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

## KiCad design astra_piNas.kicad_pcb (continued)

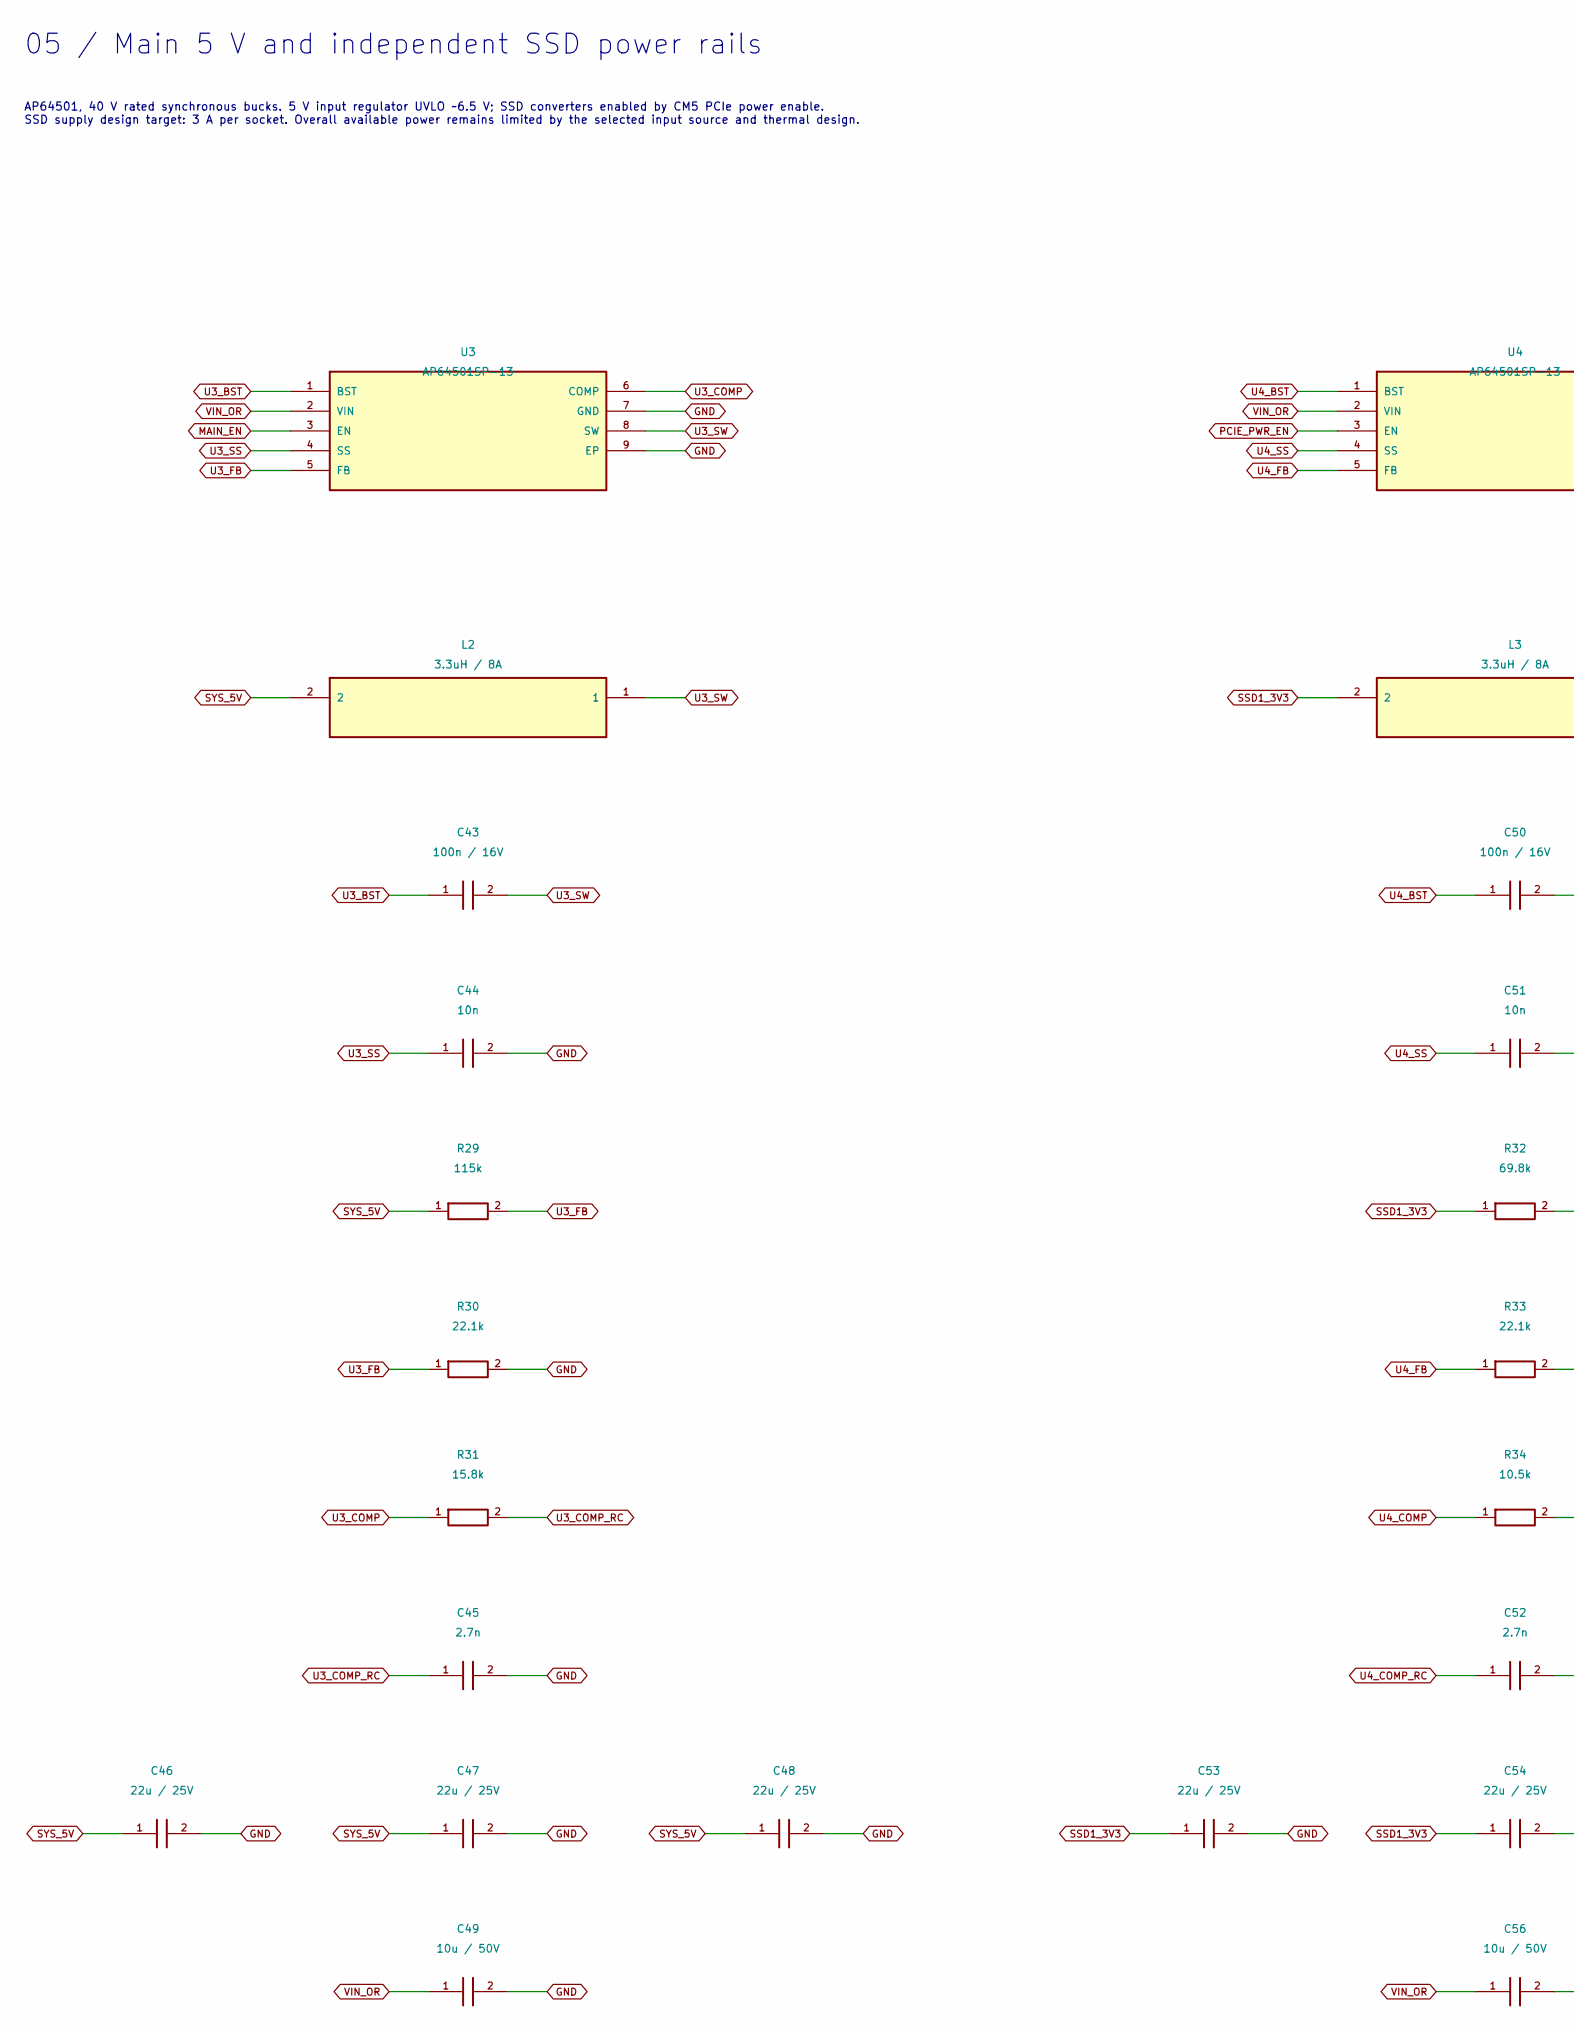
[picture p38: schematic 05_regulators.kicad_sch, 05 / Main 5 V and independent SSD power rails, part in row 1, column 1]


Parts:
C43, C50, C57: 100n / 16V; C_0402_1005Metric; MANUFACTURER PART NUMBER CL05B104KO5NNNC; LCSC Part Number C1525
C44, C51, C58: 10n; C_0603_1608Metric; MANUFACTURER PART NUMBER CL10B103KB8NNNC; LCSC Part Number C1589
C45, C52, C59: 2.7n; C_0603_1608Metric; MANUFACTURER PART NUMBER CL10B272KB8NNNC; LCSC Part Number C84713
C46, C47, C48, C53, C54, C55, C60, C61, C62: 22u / 25V; C_0805_2012Metric; MANUFACTURER PART NUMBER CL21A226MAQNNNE; LCSC Part Number C45783
C49, C56, C63: 10u / 50V; C_1206_3216Metric; MANUFACTURER PART NUMBER CL31B106KAHNNNE; LCSC Part Number C14860
L2, L3, L4: 3.3uH / 8A; IND-SMD_L7.3-W6.6; MANUFACTURER PART NUMBER MDA7050-3R3M; LCSC Part Number C2847540
R29: 115k; R_0603_1608Metric; MANUFACTURER PART NUMBER 0603WAF1153T5E; LCSC Part Number C22783
R30, R33, R36: 22.1k; R_0603_1608Metric; MANUFACTURER PART NUMBER 0603WAF2212T5E; LCSC Part Number C25961
R31: 15.8k; R_0603_1608Metric; MANUFACTURER PART NUMBER 0603WAF1582T5E; LCSC Part Number C22880
R32, R35: 69.8k; R_0603_1608Metric; MANUFACTURER PART NUMBER 0603WAF6982T5E; LCSC Part Number C23098
R34, R37: 10.5k; R_0603_1608Metric; MANUFACTURER PART NUMBER 0603WAF1052T5E; LCSC Part Number C22855
U3, U4, U5: AP64501SP-13; SOIC-8_L4.9-W3.9-P1.27-LS6.0-BL-EP-1; MANUFACTURER PART NUMBER AP64501SP-13; LCSC Part Number C2071517

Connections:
GND: C44.2, C45.2, C46.2, C47.2, C48.2, C49.2, C51.2, C52.2, C53.2, C54.2, C55.2, C56.2, C58.2, C59.2, C60.2, C61.2, C62.2, C63.2, R30.2, R33.2, R36.2, U3.7 (GND), U3.9 (EP), U4.7 (GND), U4.9 (EP), U5.7 (GND), U5.9 (EP); also elsewhere on the board
MAIN_EN: U3.3 (EN); also elsewhere on the board
PCIE_PWR_EN: U4.3 (EN), U5.3 (EN); also elsewhere on the board
SSD1_3V3: C53.1, C54.1, C55.1, L3.2, R32.1; also elsewhere on the board
SSD2_3V3: C60.1, C61.1, C62.1, L4.2, R35.1; also elsewhere on the board
SYS_5V: C46.1, C47.1, C48.1, L2.2, R29.1; also elsewhere on the board
U3_BST: C43.1, U3.1 (BST)
U3_COMP: R31.1, U3.6 (COMP)
U3_COMP_RC: C45.1, R31.2
U3_FB: R29.2, R30.1, U3.5 (FB)
U3_SS: C44.1, U3.4 (SS)
U3_SW: C43.2, L2.1, U3.8 (SW)
U4_BST: C50.1, U4.1 (BST)
U4_COMP: R34.1, U4.6 (COMP)
U4_COMP_RC: C52.1, R34.2
U4_FB: R32.2, R33.1, U4.5 (FB)
U4_SS: C51.1, U4.4 (SS)
U4_SW: C50.2, L3.1, U4.8 (SW)
U5_BST: C57.1, U5.1 (BST)
U5_COMP: R37.1, U5.6 (COMP)
U5_COMP_RC: C59.1, R37.2
U5_FB: R35.2, R36.1, U5.5 (FB)
U5_SS: C58.1, U5.4 (SS)
U5_SW: C57.2, L4.1, U5.8 (SW)
VIN_OR: C49.1, C56.1, C63.1, U3.2 (VIN), U4.2 (VIN), U5.2 (VIN); also elsewhere on the board

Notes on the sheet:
05 / Main 5 V and independent SSD power rails
AP64501, 40 V rated synchronous bucks. 5 V input regulator UVLO ~6.5 V; SSD converters enabled by CM5 PCIe power enable. SSD supply design target: 3 A per socket. Overall available power remains limited by the selected input source and thermal design.



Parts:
C64, C65: 1u / 25V; C_0603_1608Metric; MANUFACTURER PART NUMBER CL10B105KA8NNNC; LCSC Part Number C29936
C66: 10u / 50V; C_1206_3216Metric; MANUFACTURER PART NUMBER CL31B106KAHNNNE; LCSC Part Number C14860
C80: 100n / 50V; C_0603_1608Metric; MANUFACTURER PART NUMBER CL10B104KB8NNNC; LCSC Part Number C1591
D1, D4: SS54; SMA_L4.4-W2.8-LS5.4-RD; MANUFACTURER PART NUMBER SS54; LCSC Part Number C123946
D2: SMBJ26A; SMB_L4.6-W3.6-LS5.3-RD; MANUFACTURER PART NUMBER SMBJ26A; LCSC Part Number C123820
D3: 10V gate clamp; SOD-123_L2.8-W1.8-LS3.7-RD; MANUFACTURER PART NUMBER BZT52C10; LCSC Part Number C2103
F1: 5A / 125V fast fuse; FUSE-SMD_L6.1-W2.6; MANUFACTURER PART NUMBER 0451005.MRL; LCSC Part Number C48467
J5: DC-005D-2.0-PU-SP(UL); DC-IN-TH_DC-005D-2.0-PU-SP; MANUFACTURER PART NUMBER DC-005D-2.0-PU-SP(UL); LCSC Part Number C7428653
J6: TYPE-C-31-M-12; USB-C_SMD-TYPE-C-31-M-12_1; MANUFACTURER PART NUMBER TYPE-C-31-M-12; LCSC Part Number C165948
Q1: AO3401A; SOT-23_L2.9-W1.3-P1.90-LS2.4-BR; MANUFACTURER PART NUMBER AO3401A; LCSC Part Number C15127
Q2: MMBT3906LT1G; SOT-23-3_L2.9-W1.3-P1.90-LS2.4-BR; MANUFACTURER PART NUMBER MMBT3906LT1G; LCSC Part Number C53444
Q3: 2N7002; SOT-23-3_L2.9-W1.3-P1.90-LS2.4-BR; MANUFACTURER PART NUMBER 2N7002; LCSC Part Number C8545
R38, R42, R56, R57: 100k; R_0603_1608Metric; MANUFACTURER PART NUMBER 0603WAF1003T5E; LCSC Part Number C25803
R39: 22.1k; R_0603_1608Metric; MANUFACTURER PART NUMBER 0603WAF2212T5E; LCSC Part Number C25961
R40: 1k / 0.5W; R_1206_3216Metric; MANUFACTURER PART NUMBER ESR18EZPF1001; LCSC Part Number C2074262
R41, R43, R55: 10k; R_0603_1608Metric; MANUFACTURER PART NUMBER RC0603FR-0710KL; LCSC Part Number C98220
U6: CH224K; ESSOP-10_L4.9-W3.9-P1.0-LS6.0-TL-EP; MANUFACTURER PART NUMBER CH224K; LCSC Part Number C970725

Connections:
BARREL_IN: D1.2 (A), D2.1 (C), F1.2
BARREL_RAW: F1.1, J5.4
GND: C64.2, C65.2, C66.2, D2.2 (A), J5.2, J6.1 (EH), J6.2 (EH), J6.3 (EH), J6.4 (EH), J6.A1B12 (GND), J6.B1A12 (GND), Q3.2 (S), R39.2, R57.2, U6.3 (CFG3), U6.9 (CFG1), U6.11 (GND); also elsewhere on the board
MAIN_EN: R38.2, R39.1; also elsewhere on the board
PD_CC1: J6.A5 (CC1), U6.7 (CC1)
PD_CC2: J6.B5 (CC2), U6.6 (CC2)
PD_GATE: C80.1, D3.2 (A), Q1.1 (G), R42.2, R43.1
PD_GATE_ENABLE: Q2.3 (C), Q3.1 (G), R57.1
PD_GATE_SINK: Q3.3 (D), R43.2
PD_GOOD_N: R55.2, U6.10 (PG)
PD_PNP_BASE: Q2.1 (B), R55.1, R56.1
PD_SENSE: R41.2, U6.8 (VBUS)
PD_VDD: C64.1, Q2.2 (E), R40.2, R56.2, U6.1 (VDD), U6.2 (CFG2)
USB_PD_SWITCHED: D4.2 (A), Q1.3 (D)
USB_PD_VBUS: C65.1, C80.2, D3.1 (K), J6.A4B9 (VBUS), J6.B4A9 (VBUS), Q1.2 (S), R40.1, R41.1, R42.1
VIN_OR: C66.1, D1.1 (K), D4.1 (K), R38.1; also elsewhere on the board

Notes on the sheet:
06 / Barrel and USB-C PD power inputs
Center-positive barrel input: 9-25 V DC. USB-C requires a 20 V / 3 A PD supply; its data contacts are unconnected. Schottky source OR-ing prevents reverse feed. The highest source normally supplies the load; seamless changeover is not guaranteed.

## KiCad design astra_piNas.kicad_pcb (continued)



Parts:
C67, C68, C69, C70: 100n / 50V; C_0603_1608Metric; MANUFACTURER PART NUMBER CL10B104KB8NNNC; LCSC Part Number C1591
C71: 10u / 50V; C_1206_3216Metric; MANUFACTURER PART NUMBER CL31B106KAHNNNE; LCSC Part Number C14860
D5: SS54; SMA_L4.4-W2.8-LS5.4-RD; MANUFACTURER PART NUMBER SS54; LCSC Part Number C123946
J8: HR913180AE; RJ45-TH_HR913180AE; MANUFACTURER PART NUMBER HR913180AE; LCSC Part Number C19724762
R44, R45: 330; R_0603_1608Metric; MANUFACTURER PART NUMBER 0603WAF3300T5E; LCSC Part Number C23138
R58: 1k / 0.5W; R_1206_3216Metric; MANUFACTURER PART NUMBER ESR18EZPF1001; LCSC Part Number C2074262
U7: WC-PD60B120A; WC_PD60B120A_MECHANICAL_REVIEW; MANUFACTURER PART NUMBER WC-PD60B120A; LCSC Part Number C2848082

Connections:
CM_3V3: R44.1, R45.1; also elsewhere on the board
ETH0_N: J8.10 (MD1-); also elsewhere on the board
ETH0_P: J8.11 (MD1+); also elsewhere on the board
ETH1_N: J8.5 (MD2-); also elsewhere on the board
ETH1_P: J8.4 (MD2+); also elsewhere on the board
ETH2_N: J8.2 (MD3-); also elsewhere on the board
ETH2_P: J8.3 (MD3+); also elsewhere on the board
ETH3_N: J8.9 (MD4-); also elsewhere on the board
ETH3_P: J8.8 (MD4+); also elsewhere on the board
ETH_CT0: C67.1, J8.12 (MDCT1)
ETH_CT1: C68.1, J8.6 (MDCT2)
ETH_CT2: C69.1, J8.1 (MDCT3)
ETH_CT3: C70.1, J8.7 (MDCT4)
ETH_LED_A: J8.17 (LEDG+), R44.2
ETH_LED_ACT_N: J8.18 (LEDG-); also elsewhere on the board
ETH_LED_LINK_N: J8.20 (LEDY-G+); also elsewhere on the board
ETH_LED_Y: J8.19 (LEDY+G-), R45.2
GND: C67.2, C68.2, C69.2, C70.2, C71.2, J8.21 (SHELL), J8.22 (SHELL), R58.2, U7.5 (VOUT-), U7.6 (VOUT-); also elsewhere on the board
POE_12V: C71.1, D5.2 (A), R58.1, U7.7 (VOUT+), U7.8 (VOUT+)
POE_VA1: J8.13 (VC1+), U7.1 (VA1)
POE_VA2: J8.14 (VC1-), U7.2 (VA2)
POE_VB1: J8.15 (VC2+), U7.3 (VB1)
POE_VB2: J8.16 (VC2-), U7.4 (VB2)
VIN_OR: D5.1 (K); also elsewhere on the board

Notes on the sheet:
07 / Gigabit Ethernet and PoE++ candidate
PoE module is a PROVISIONAL sourcing choice: only 15 in LCSC stock at capture. Low stock does not satisfy the original deep-stock requirement. Do not release this sheet for manufacture until module pin 9/10 mechanical coordinates and 802.3bt class power are confirmed.

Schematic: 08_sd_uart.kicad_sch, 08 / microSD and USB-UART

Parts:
C72, C74, C75, C76: 100n / 50V; C_0603_1608Metric; MANUFACTURER PART NUMBER CL10B104KB8NNNC; LCSC Part Number C1591
C73: 22u / 25V; C_0805_2012Metric; MANUFACTURER PART NUMBER CL21A226MAQNNNE; LCSC Part Number C45783
J7: TYPE-C-31-M-12; USB-C_SMD-TYPE-C-31-M-12_1; MANUFACTURER PART NUMBER TYPE-C-31-M-12; LCSC Part Number C165948
J9: TF-01A; TF-SMD_TF-01A; MANUFACTURER PART NUMBER TF-01A; LCSC Part Number C91145
R46, R47, R48, R49, R50: 10k; R_0603_1608Metric; MANUFACTURER PART NUMBER RC0603FR-0710KL; LCSC Part Number C98220
R51, R52: 5.1k; R_0603_1608Metric; MANUFACTURER PART NUMBER 0603WAF5101T5E; LCSC Part Number C23186
R53, R54: 330; R_0603_1608Metric; MANUFACTURER PART NUMBER 0603WAF3300T5E; LCSC Part Number C23138
U8: RT9742GGJ5; TSOT-23-5_L2.9-W1.6-P0.95-LS2.8-BR; MANUFACTURER PART NUMBER RT9742GGJ5; LCSC Part Number C250547
U9: CH343P; TQFN-16_L3.0-W3.0-P0.50-BL-EP1.7; MANUFACTURER PART NUMBER CH343P; LCSC Part Number C2846043
U10: USBLC6-2SC6; SOT-23-6_L2.9-W1.6-P0.95-LS2.8-BL; MANUFACTURER PART NUMBER USBLC6-2SC6; LCSC Part Number C7519

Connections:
CM_3V3: C72.1, C76.1, U8.5 (VIN), U9.1 (VIO); also elsewhere on the board
GND: C72.2, C73.2, C74.2, C75.2, C76.2, J7.1 (EH), J7.2 (EH), J7.3 (EH), J7.4 (EH), J7.A1B12 (GND), J7.B1A12 (GND), J9.6 (VSS), J9.10 (GND), J9.11 (GND), J9.12 (GND), J9.13 (GND), R51.2, R52.2, U8.2 (GND), U9.2 (GND), U9.17 (EP), U10.2; also elsewhere on the board
SD_3V3: C73.1, J9.4 (VDD), R46.1, R47.1, R48.1, R49.1, R50.1, U8.1 (VOUT)
SD_CLK: J9.5 (CLK(SCLK)); also elsewhere on the board
SD_CMD: J9.3 (CMD(DI)), R46.2; also elsewhere on the board
SD_DAT0: J9.7 (DAT0(D0)), R47.2; also elsewhere on the board
SD_DAT1: J9.8 (DAT1(RSV)), R48.2; also elsewhere on the board
SD_DAT2: J9.1 (DAT2(RSV)), R49.2; also elsewhere on the board
SD_DAT3: J9.2 (CDDAT3(CS)), R50.2; also elsewhere on the board
SD_PWR_EN: U8.4 (EN/~EN); also elsewhere on the board
UART_CC1: J7.A5 (CC1), R51.1
UART_CC2: J7.B5 (CC2), R52.1
UART_RX_BRIDGE: R54.2, U9.5 (RXD)
UART_RX_CM: R53.2; also elsewhere on the board
UART_TX_BRIDGE: R53.1, U9.4 (TXD)
UART_TX_CM: R54.1; also elsewhere on the board
UART_USB_N: J7.A7 (DN1), J7.B7 (DN2), U9.8 (UD-), U10.3, U10.4
UART_USB_P: J7.A6 (DP1), J7.B6 (DP2), U9.7 (UD+), U10.1, U10.6
UART_V3: C75.1, U9.6 (V3)
UART_VBUS: C74.1, J7.A4B9 (VBUS), J7.B4A9 (VBUS), U9.3 (VDD5), U9.9 (VBUS), U10.5

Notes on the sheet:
08 / microSD and USB-UART
USB-UART is independently powered by its USB cable; VIO follows CM5 3.3 V. No connection between debug VBUS and SYS_5V. GPIO14/15 UART requires OS configuration; this is not the separate CM5 on-module boot-debug UART.



Board: 6 copper layers, 100.0 x 120.0 mm, 176 parts (12 on the bottom side), 133 nets.

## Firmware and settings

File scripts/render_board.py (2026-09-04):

"""Render two oblique KiCad views and compose the README image (requires Pillow)."""
from pathlib import Path
import argparse, subprocess
from PIL import Image, ImageDraw, ImageFont
ROOT=Path(__file__).resolve().parents[1]
OUTPUT=ROOT/'docs/images'
def compose():
    width,height,gap,header=1800,2000,40,105
    canvas=Image.new('RGB',(2*width+3*gap,height+header+2*gap),'#edf0f3')
    draw=ImageDraw.Draw(canvas)
    font=ImageFont.truetype('/usr/share/fonts/truetype/dejavu/DejaVuSans.ttf',44)
    for i,side in enumerate(('top','bottom')):
        x=gap+i*(width+gap)
        draw.text((x+36,gap+24),side.title(),font=font,fill='#263445')
        im=Image.open(OUTPUT/f'render-{side}.png').convert('RGBA')
        assert im.width<=width and im.height<=height
        canvas.paste(im,(x+(width-im.width)//2,gap+header+(height-im.height)//2),im)
    canvas.save(OUTPUT/'board-3d-overview.png',optimize=True)
if __name__=='__main__':
    parser=argparse.ArgumentParser();parser.add_argument('--compose-only',action='store_true');args=parser.parse_args()
    if not args.compose_only:
        for side,rotation in [('top','342,12,348'),('bottom','18,348,12')]:
            subprocess.run(['kicad-cli','pcb','render','--side',side,'--rotate',rotation,
                '--width','1800','--height','2000','--quality','high','--background','transparent',
                '--zoom','0.72','-o',str(OUTPUT/f'render-{side}.png'),str(ROOT/'astra_piNas.kicad_pcb')],check=True,cwd=ROOT)
    compose()

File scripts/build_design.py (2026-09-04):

from pathlib import Path
import json,re,uuid,copy,math,shutil
from sexpr import *
ROOT=Path(__file__).resolve().parents[1]
CAT=json.loads((ROOT/'sources/catalog.json').read_text())
LIB=loads((ROOT/'lib/astra_piNas.kicad_sym').read_text())
IMPORTED={s[1]:s for s in children(LIB,'symbol')}
PARTS={}
for name,s in IMPORTED.items():
 props={p[1]:p[2] for p in children(s,'property')}
 n=props.get('LCSC Part')
 if n:PARTS[n]={'name':name,'fp':props['Footprint'].split(':')[-1],'pins':{child(p,'number')[1]:child(p,'name')[1] for u in children(s,'symbol') for p in children(u,'pin')}}
# Retain downloaded originals; generated readable symbols live separately.
Q=lambda s:json.dumps(str(s),ensure_ascii=False)
uid=lambda s:str(uuid.uuid5(uuid.NAMESPACE_URL,'astra_piNas/'+s))
F=lambda n:f'{float(n):.4f}'.rstrip('0').rstrip('.')
SCHEETS={};COMP={};SYMS={};COUNTS={};NOTES={}
def txt(s,x,y,size=1.27):return f'(text {Q(s)} (at {F(x)} {F(y)} 0) (effects (font (size {size} {size})) (justify left)) (uuid {uid(s+str(x)+str(y))}))'
def sheet(name,title,notes=''):
 SCHEETS[name]=[];NOTES[name]=(title,notes)
 SCHEETS[name].append(txt(title,12.7,15.24,2.54))
 if notes:SCHEETS[name].append(txt(notes,12.7,24.13,1.05))
def passive_part(n,kind):
 # Standard KiCad footprints are vendored into the project.
 pkg=CAT[n]['package'];size='1206' if '1206' in pkg else '0805' if '0805' in pkg else '0603'
 metric={'0603':'1608','0805':'2012','1206':'3216'}[size]
 src=f'{"Resistor" if kind=="R" else "Capacitor"}_SMD.pretty/{kind}_{size}_{metric}Metric.kicad_mod'
 fp=Path(src).name[:-10]
 p=ROOT/'lib/astra_piNas.pretty'/Path(src).name
 if not p.exists():
  data=(Path('/usr/share/kicad/footprints')/src).read_text()
  # Remove stock-library 3D paths so the project has no external model dependency.
  v=loads(data);v=[a for a in v if not (isinstance(a,list) and a[0]=='model')];p.write_text(dumps(v))
 return {'name':kind+'_'+n,'fp':fp,'pins':{'1':kind+'1','2':kind+'2'},'kind':kind}
def register(n,kind=None):
 if n in PARTS:return PARTS[n]
 if kind:PARTS[n]=passive_part(n,kind);return PARTS[n]
 raise ValueError(n)
def symbol(symname,p,groups,types):
 if symname in SYMS:return
 props=''.join(f'(property {Q(k)} {Q(v)} (at 0 0 0) (effects (font (size 1 1)) hide))' for k,v in [('Reference','U'),('Value',symname),('Footprint','astra_piNas:'+p['fp'])])
 ss=f'(symbol {Q(symname)} (pin_names (offset 0.8)) (in_bom yes) (on_board yes) {props}'
 locs={}
 for unit,nums in enumerate(groups,1):
  ps=[];kind=p.get('kind')
  if kind:
   # Horizontal two-terminal IEC resistor/capacitor.
   positions=[(-5.08,0,0),(5.08,0,180)];h=5.08;w=2.54
   if kind=='R':shape='(rectangle (start -2.54 1.016) (end 2.54 -1.016) (stroke (width 0.254) (type default)) (fill (type none)))'
   else:shape=''.join(f'(polyline (pts (xy {x} -1.778) (xy {x} 1.778)) (stroke (width 0.254) (type default)) (fill (type none)))' for x in [-0.635,0.635])
  else:
   half=math.ceil(len(nums)/2);h=max(7.62,(half+1)*2.54);w=17.78 if max(map(lambda k:len(p['pins'][k]),nums),default=0)<18 else 24.13
   positions=[(-w-5.08,h/2-2.54-j*2.54,0) for j in range(half)]+[(w+5.08,h/2-2.54-j*2.54,180) for j in range(len(nums)-half)]
   shape=f'(rectangle (start {-w} {h/2}) (end {w} {-h/2}) (stroke (width 0.254) (type default)) (fill (type background)))'
  for k,(x,y,a) in zip(nums,positions):
   length=2.54 if kind=='R' else 4.445 if kind=='C' else 5.08
   ps.append(f'(pin {types.get(k,"passive")} line (at {F(x)} {F(y)} {a}) (length {length}) (name {Q("~" if kind else p["pins"][k])} (effects (font (size 0.95 0.95)))) (number {Q(k)} (effects (font (size 0.9 0.9)))))')
   locs[(unit,k)]=(x,y,a)
  ss+=f'(symbol {Q(symname+"_"+str(unit)+"_1")} {shape} '+''.join(ps)+')'
 SYMS[symname]={'sexpr':ss+')','locs':locs,'groups':groups,'part':p}
def add(sh,ref,n,nets,x,y,kind=None,groups=None,unit=1,types=None,symname=None,value=None):
 x=round(x/1.27)*1.27;y=round(y/1.27)*1.27
 p=register(n,kind);pins=p['pins']
 if groups is None:groups=[list(pins)]
 types=types or {};symname=symname or p['name'];symbol(symname,p,groups,types)
 sy=SYMS[symname];h=max([abs(v[1]) for (u,k),v in sy['locs'].items() if u==unit]+[3])+5.08
 if ref not in COMP:COMP[ref]={'ref':ref,'lcsc':n,'part':p,'nets':{str(k):v for k,v in nets.items()},'uuid':uid(ref+'_u'+str(unit)),'sheet':sh,'sym':symname,'value':value or CAT[n]['model']}
 else:assert COMP[ref]['nets']=={str(k):v for k,v in nets.items()}
 c=COMP[ref];mpn=CAT[n]['model'];val=value or mpn
 props=[('Reference',ref,x,y-h,False),('Value',val,x,y-h+2.54,False),('Footprint','astra_piNas:'+p['fp'],x,y,True),('Datasheet',CAT[n]['url'],x,y,True),('MANUFACTURER PART NUMBER',mpn,x,y,True),('Manufacturer',CAT[n]['brand'],x,y,True),('LCSC Part Number',n,x,y,True),('LCSC Stock',str(CAT[n]['lcsc_stock']),x,y,True)]
 ss=f'(symbol (lib_id {Q("astra_piNas:"+symname)}) (at {F(x)} {F(y)} 0) (unit {unit}) (in_bom yes) (on_board yes) (dnp no) (uuid {uid(ref+"_u"+str(unit))})'
 for k,v,px,py,hide in props:ss+=f'(property {Q(k)} {Q(v)} (at {F(px)} {F(py)} 0) (effects (font (size 1.0 1.0)){" hide" if hide else ""}))'
 for k in groups[unit-1]:ss+=f'(pin {Q(k)} (uuid {uid(ref+"pin"+k)}))'
 ss+=f'(instances (project "astra_piNas" (path {Q("/"+uid("root")+"/"+uid("sheet_"+sh))} (reference {Q(ref)}) (unit {unit})))))'
 SCHEETS[sh].append(ss)
 for k in groups[unit-1]:
  dx,dy,a=sy['locs'][(unit,k)];px=x+dx;py=y-dy;net=nets.get(k)
  if net is None:SCHEETS[sh].append(f'(no_connect (at {F(px)} {F(py)}) (uuid {uid(ref+k+"nc")}))');continue
  end=px+(-5.08 if a==0 else 5.08)
  SCHEETS[sh].append(f'(wire (pts (xy {F(px)} {F(py)}) (xy {F(end)} {F(py)})) (stroke (width 0) (type default)) (uuid {uid(ref+k+"wire")}))')
  # Global label extends away from the symbol.
  rot=0 if a==0 else 180
  SCHEETS[sh].append(f'(global_label {Q(net)} (shape bidirectional) (at {F(end)} {F(py)} {rot}) (effects (font (size 0.9 0.9)) (justify {"right" if a==0 else "left"})) (uuid {uid(ref+k+"label")}) (property "Intersheetrefs" "${{INTERSHEET_REFS}}" (at {F(end)} {F(py)} {rot}) (effects (font (size 0.8 0.8)) hide)))')
 return c
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

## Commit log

2026-09-04 Add routed six-layer CM5 dual-NVMe carrier and review documentation
    [01_cm5.kicad_sch, 02_pcie.kicad_sch, 03_aux_power.kicad_sch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]
2026-09-04 Document experiment prompts and add PCB layer and schematic gallery
2026-09-04 Add combined six-layer PCB overview to README
2026-09-04 Add local passive 3D models and two-sided angled board render
    [astra_piNas.kicad_pcb]
